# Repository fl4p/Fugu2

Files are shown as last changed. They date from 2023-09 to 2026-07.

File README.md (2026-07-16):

# Bi-directional DC-DC buck or boost converter for Solar MPPT

Links: [git](https://github.com/fl4p/Fugu2)
| [kicanvas](https://kicanvas.org/?github=https%3A%2F%2Fgithub.com%2Ffl4p%2FFugu2)
| [cadlab](https://cadlab.io/project/28816)
| [docs](doc/)
| [pdf schematics](Schematics.pdf)
| IBOM (TODO)
| [firmware](https://github.com/fl4p/fugu-mppt-firmware)
| [additional docs & resources](https://github.com/fl4p/fugu-mppt-doc)

```
TODO 3d web rendering
gate drv considerations:
- separate gate discharge diode?
- eval gate drv voltage?
- pull down for each fet? 10k pull down?
usb-c: select 12V instead of 5V

final points:
- what about the LS diodes? SMD and TO220, do power measurements.
    - ST15100S and ...
    - 2nd LS switch parallel ?
- sw push footprint
- test without TVS diodes at solar voltage divider. when does the mcu die? 
- tune dead-time

bom opts:
- Cin: C11, C22 replace with MSASH32MSB5475MPCA01 / HMK325BJ475MM-PE ?
    cheaper and specifically for SMPS
```

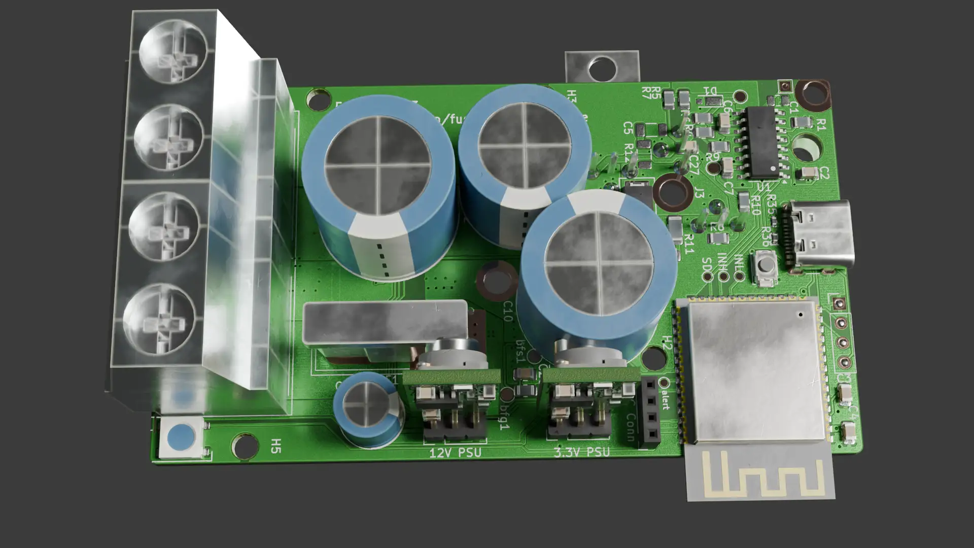
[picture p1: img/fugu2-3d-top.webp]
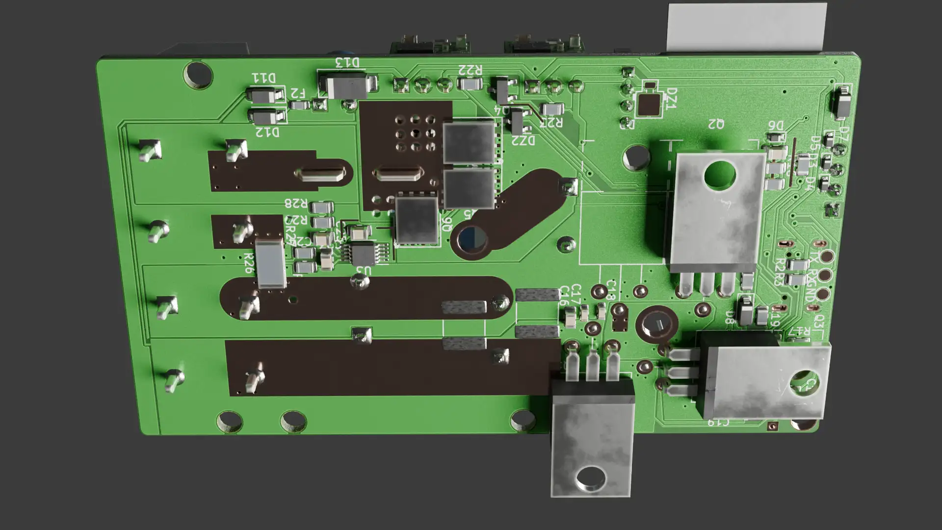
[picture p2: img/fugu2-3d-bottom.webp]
|   |
|:------------------------------------------------------------------------------------------------:|
|  Current Hardware v2.3 rendering with USB type-C port and large terminal blocks (top & bottom)   |

## Gallery

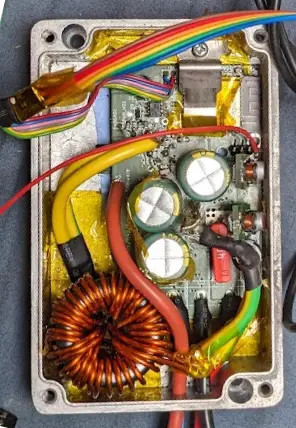
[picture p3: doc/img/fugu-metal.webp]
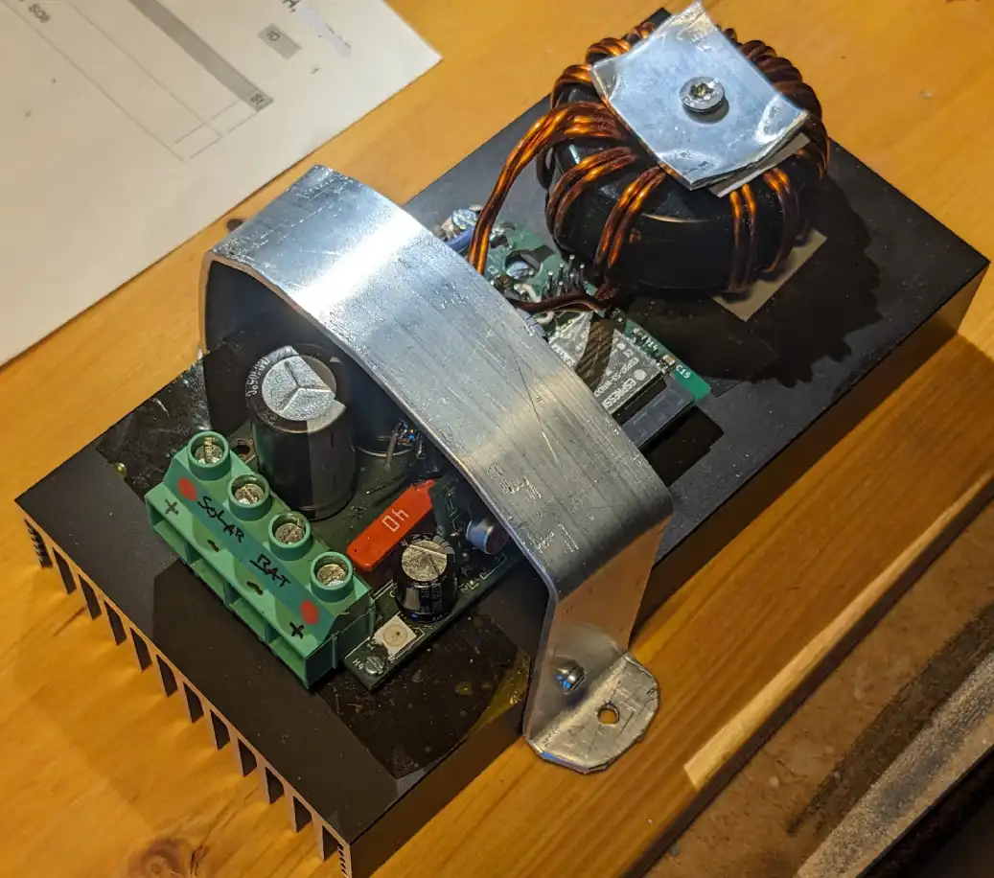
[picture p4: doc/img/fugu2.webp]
|  |  |
|:---:|:---:|
| Small aluminium enclosure with two T130 sendust coil cores [fmetal](HW%20Stories/Fugu%20Metal/README.md) | mounted on heatsink, T184 sendust core [fheat](HW%20Stories/fheat.md) |

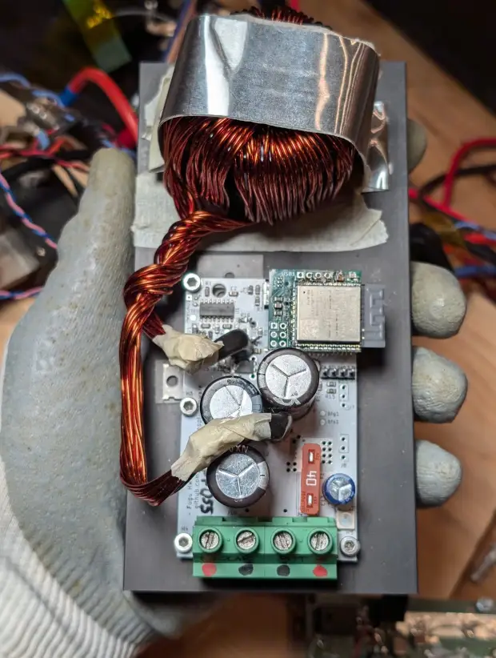
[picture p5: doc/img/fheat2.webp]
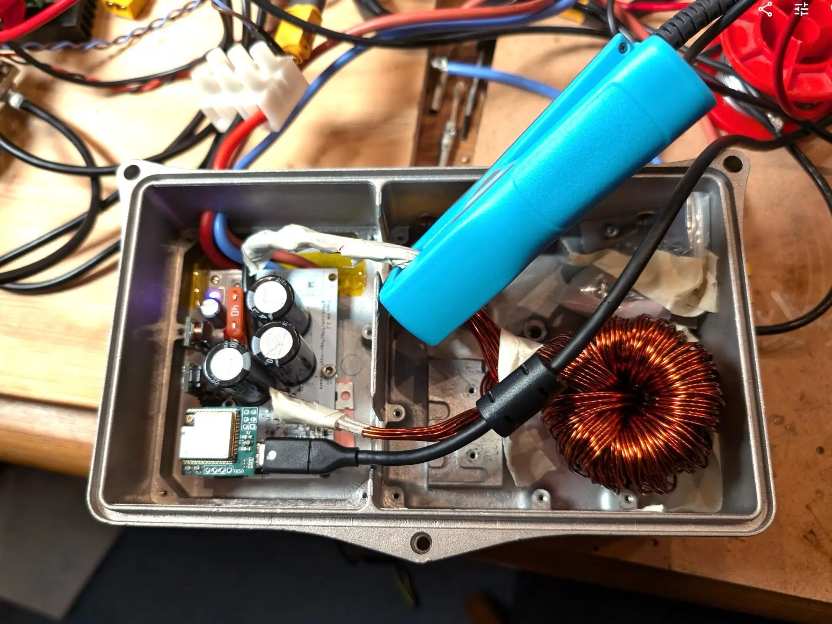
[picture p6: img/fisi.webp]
|  |  |
|:---:|:---:|
| improved coil with two T184 sendust cores [fheat2](HW%20Stories/fheat2.md) | inside an enclosure from a RF amp  [fisi](HW%20Stories/fisi.md) |

## Specs

* Solar input voltage: 12 ~ 80V (higher voltage configurations possible, please create an issue if you need help with
  component selection)
* Battery output voltage: 12 ~ 60V (LiFePo4 4s ~ 16s)
* Max output current: 32 A
* Boost operation with input and output terminals swapped
* Efficiency Measurements
    * Vin=72 Vout=27 Iout=32A: 98.17% (measured with INA228 & Riedon
      SSA-100, [smart-shunt](https://github.com/open-pe/smart-shunt-fw))
    * Vin=71.5 Vout=27.1 Iout=29.1A: 98.12% (measured with INA228, Riedon RSN20-50, DCCT
      DS200ID, [details](doc/Efficiency%20Measurements.md))

This is inspired by [Fugu MPPT](https://www.instructables.com/DIY-1kW-MPPT-Solar-Charge-Controller/).
The design has been optimized with real life experience, considering signal noise and EMI issues,
replaced hall sensor with shunt resistor and faster switching. See the list below for more changes.

## How to build

You can place the ESP32-S3 directly on the board and use the USB pin header or the ESP-PROG header for flashing.
Alternatively, you can place SMD pin headers where the ESP32-S3 footprint is and use the MCU header board.
This makes it easier to replace the MCU in case it breaks. You can of course create your own header board using another
MCU series such as the STM32.

* order PCB (or make @home)
    * 1x `Fugu2.kicad_pcb`
    * 1x `psu/buck100.kicad_pcb` (for 3.3V supply)
    * 1x `mcu-head/Fugu2-esp32s3-wroom-head.kicad_pcb` (optional. this allows easy replacement of the ESP32S3 during
      development. alternatively place the ESP32(-S3) directly on the Fugu2 board)
    * you can use [kikit-packer](https://github.com/fl4p/kikit-packer/)
      or [Kikakuka](https://github.com/buganini/Kikakuka/) to create a single PCB for the manufacturing job.
        * kikit-packer instructions: follow the install instructions in
          the [readme](https://github.com/fl4p/kikit-packer/tree/main?tab=readme-ov-file). make sure you have `Fugu2/`
          and `kikit-packer/` in the same directory. then run `panelize.sh` (linux, mac) or `panelize.bat` (windows). It
          will generate `combined.kicad_pcb` which you can send to your PCB manufacturer.
* assemble PCBs (ibom TODO)
    * you can order assembly through pcbway or jlcpcb
    * if you assemble @home
        * place solder-paste on all SMD pads
        * put SMD items first (resistors, caps, diodes, inductors and then IC)
        * heat with a hotplate (a cooking pan filled with sand works) or hot air gun
        * solder the THT components (electrolytic caps, power inductor, mosfets, pin headers, power terminal blocks)
* mount the PCB on a heatsink (expect 20W of heat)
    * drill mounting holes
    * if mosfets are not isolated use thermal pads for isolation
    * M3 plastic screws are a cheap and easy alternative
* enclosure
    * todo: there is no enclosure yet
* build inductor
    * order core and copper wire.
      cores are available at [semic](https://www.semic.info/) or digikey.
      I buy wire from eBay.
    * wind the coil
* flash [firmware](https://github.com/fl4p/fugu-mppt-firmware)

## Design Principles

* Simplicity with minimum number of components, while keeping EMI and efficiency in mind
* Only 2-layer PCB and using mostly 0805 SMD components, so this can be made at home
* Using TO220 switches for the buck for easy maintenance
* Dense PCB design to reduces parasitic L and R

## Compared to the original design:

- Multiple input caps to increase life-time, efficiency and reduced EMI
- 2 high-side switches in parallel to reduce heat and increase efficiency
- Using ESP32 ADC to sense input voltage, INA226 for bat voltage
- Using current sense resistor with INA226 (immunity against magnetic fields, less drift)
- Current sense on the battery side (less noise, can detect bat reverse current)
- Low-side current sensing because it supports up to 60V battery voltage (for 16s lifepo4 48V batteries)
- Backflow switch on battery side (bat eFuse if sth goes wrong, can safely handle a short of the high-side switches)
- Backflow switch powered by bootstrapping charge pump from the HS gate driver (no extra DC-DC)
- Much higher 4 A gate drive current (previously 130mA and 1.4 A) to reduce switching losses (TI UCC21330)
- Introducing RC snubber circuit to reduce EMI and MOSFET voltage stress
- TVS protection circuit to protect internal power supply
- off-board 3.3V and 12V power-supply
- USB break-out and off-board programmer (ESP PROG Header)
- Improved voltage and current sense PCB Design (voltage divider & filter caps close to ADC)
- Using LM5163 for power supply. (XL7005A explodes at surge voltages ~80V. Seems vulnerable at temps >~70°C)

## Power loss reduction

* 4A gate driver UCC21330BQDRQ1 with programmable dead-time
    * fast switching (high-side)
    * optimized dead-time, reduce free-wheeling losses (low-side)
* dense half-bridge PCB design for minimum parasitic inductance
* short and min-area gate-drive tracks for minimum gate drive inductance
* low-side rectifier Schottky barrier diode to reduce free-wheeling loss and reverse-recovery loss
* cascade of input capacitors: 220nF, 1uF, 10uF, 470uF input caps to minimize capacitor ESR-loss
    * low impedance electrolytics
* optimized coil designs
    * optimized core flux density and core power loss
    * multi-[strand](https://www.e-magnetica.pl/doku.php/strand) coil for reduced R_dc and R_ac (considering skin &
      proximity effect)

# Inductor Quick Start Guide

The inductor should have an inductivity value that is high enough to keep the ripple current in range, a common design
rule is that ripple is in the range of 0.3 ~ 0.5 of the dc current. Notice that inductivity decreases with dc bias
current. The dc bias current is the average current through the coil. This means that the higher the output current of
the converter,
the lower the inductivity. This causes the AC indcutor ripple current to rise faster than linear with higher currents.
High ripple currents cause more loss in the inductor core (hysteresis loss) and capacitors (parasitic ESR).
Going beyond the safe limits can cause extremely high peak currents leading to destruction of the FETs.

The [micrometals design tool](https://www.micrometals.com/design-and-applications/design-tools/inductor-designer/) is a
good starting point to find suitable inductor designs with mostly toroid cores. It gives the user recommendations on
core shape, core material and wire (diameter and strands).

Off-the-shelf inductors exists, however they are usually expensive (>$20), such as the 	
CODACA CPEX4141L-500MC (optimized for dc bias / saturation current) and CPEA4141L-500MC (optimized for low loss).
On LCSC you'll
find [Ruishen RSEQ32-470M](https://www.lcsc.com/product-detail/Power-Inductors_Ruishen-RSEQ32-470M_C37634010.html),
[RSEQ3635-460M](https://www.lcsc.com/product-detail/C37634012.html)  and
[RSEQ3635-700M](https://www.lcsc.com/product-detail/Power-Inductors_Ruishen-RSEQ3635-700M_C37634013.html).
I have only tested toe CODACA cores and no experience with the LCSC parts.

Diving into inductor design can be overwhelming at first. In practice there is no perfect inductor for a specific
application.
Given current, voltage and temperature contraints, the designer usually optimizes for one or more goals, which always
comes with trade-offs. In short:

* chose inductivity L0 high enough (L0 is the unbiased inductivity, e.g. I=0)
* good dc bias saturation performance (L drops with increased dc current)
* low DC resistance of winding
* low core losses

Winding an inductor is nothing to worry about and is actually fun. Below you'll find two design proposals, one
for 12 and 24V, upto 40A and the other for 48V batteries. Before, let's have a short intro to better understand the
design decisions.

A well designed inductor has a core/copper loss ratio between 50/50 and
20/80 ([micrometals](https://www.micrometals.com/design-and-applications/core-design-considerations/#inductor-design-basics)).
Copper is easier to cool
than the core.
With higher DC output current the core material magnetization increases and inductivity value drops. A good design has a
maximum drop of ~50% of its initial inductivity.
Lower inductivity will cause higher ripple current, which will cause more loss in the core and capacitors (increased AC
amplitude of magnetic field and current).

For higher DC currents chose a larger core (or materials optimized for DC saturation, which can have low availability
and a higher price tag).
For higher output voltage chose a higher inductivity value.

Sendust (KoolMµ)  is a magnetic core material commonly used for power applications. It is affordable with high
availability,
has good saturation characteristics and low loss.
Manufacturers offer optimized materials, tuning for price, dc bias and/or core loss.
([KDM](https://semic.cz/!old/files/pdf_www/Ljf_KDM.pdf): KPH, KAM, KAH, KH)

For the coil winding choose isolated Copper wire made for electrical applictions commonly referred as W210 with typical
conductivity of 58.5 MS/m. Choose diameter and number of strands so that inner diameter of the toroid core has a good
usage.
Prefer multiple strands for easier winding (>2mm diameter becomes unhandy to wind) and reduced ac loss (skin & proximity
effects). Many strands (>10) increase complexity of winding. A diameter between 1 and 2mm appears to be good choice.
More copper reduces dc resistance and leakage fringing (TODO ref). Evenly wind the wire on the core to reduce leakage
fringing.

## 12V or 24V battery up to 40A

* Optimized for low loss 12V and 24V batteries, up to 40A battery current @39kHz
* Core: 2 stacked [KS184-125A](https://www.semic.info/ljf-t184-s-125a-bk/) (or 0077438A7
  from [digikey](https://www.digikey.com/en/products/detail/magnetics-a-division-of-spang-co/0077438A7/18626927))
* Wire: Ø=1.18mm Cu (1.25mm total), W210 (Grade 2) Copper
* Winding: 10 strands, 12 turns, need 20 meter wire in total (10x 2m)
* Systematic name: 2s-KS184-125A-118cu-10s-12t
* [Micrometals analyzer](https://www.micrometals.com/design-and-applications/design-tools/inductor-analyzer/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)

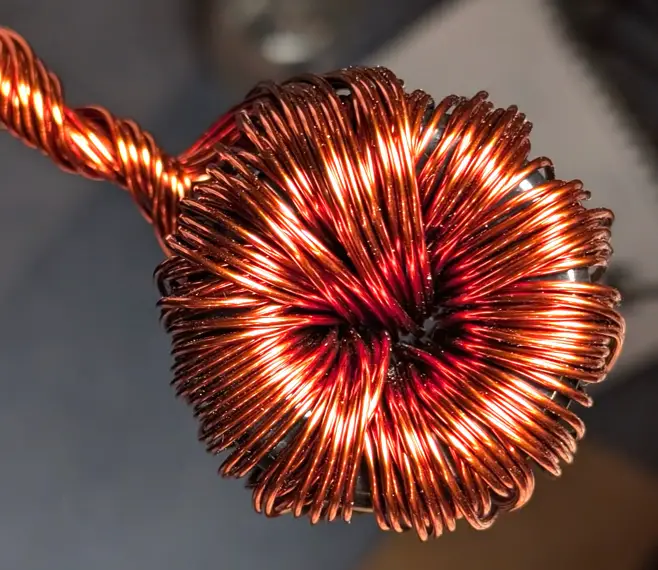
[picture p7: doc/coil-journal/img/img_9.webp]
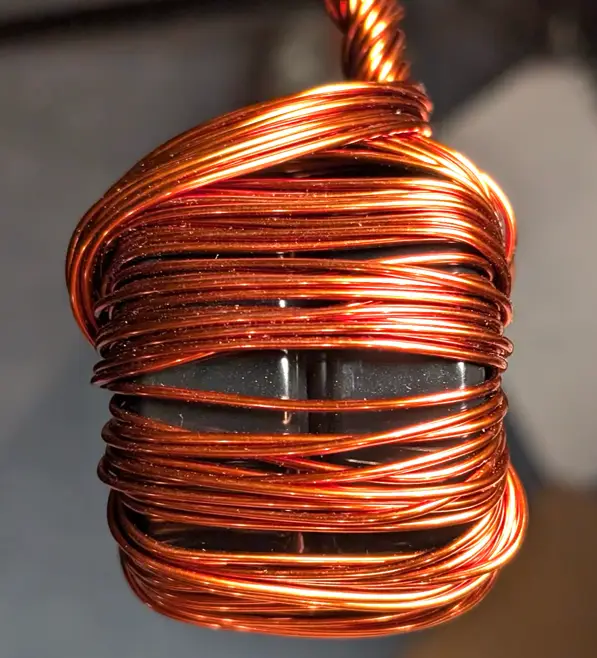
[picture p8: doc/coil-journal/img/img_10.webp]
 

## 48V batteries up to 20A

* Core: 1x [KS184-125A](https://www.semic.info/ljf-t184-s-125a-bk/)
* Wire: Ø=1.63mm Cu (AWG14), W210 (Grade 2) Copper
* Winding: 4 strands, 20 turns
* Systematic name: 1s-KS184-125A-163cu-4s-20t
* [Micrometals Analyzer](https://www.micrometals.com/design-and-applications/design-tools/inductor-analyzer/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)

# Mosfet Selection

In a nutshell, the LS switch should have low Rds_on, low Qrr, low Qgd (low self turn-on). The HS switch should have low
Qsw.
See [Toshibas Product Guide on pg. 16](https://www.mouser.com/datasheet/2/408/toshiba%20america%20electronic%20components,%20inc._bce008-1209380.pdf#page=16).

Use [fetlib](https://github.com/fl4p/fetlib) for an extensive parametric search and ranking by power loss estimation.

## High Side Mosfet (HS, cntrl)

- exposed to switching stress
- short switching times to lower switching losses (small Qsw) but increase potential ringing (EMI)
- low Rds_on
- body diode never conducts
- picks:
    - IPP055N08NF2S (80V 5.5mΩ Qsw=13nC)
    - IPP040N08NF2S (80V,)
    - CSD19501KCS (80V 5.5mΩ Qsw=11nC)
    - IPA050N10NM5S (100V 5mΩ Qsw=16nC Qoss=67nC)
    - IPP089N15NM6 (150V Qsw=11nC)
    - IPP057N15NM6 (150V Qsw=16nC)
    - IPP050N10NF2S (100 V)

## Low Side Switch (LS, sync)

- Choose a mosfet with low Q_rr ([how to compute qrr loss](https://www.ti.com/lit/ta/ssztc00/ssztc00.pdf))
    - Qrr rises with increasing temperature, current and current transient
    - Qrr ringing and loss can be reduced with external Schottky diode
      or [cascode configuration](https://www.researchgate.net/publication/378199983_Improving_the_Reverse-Recovery_Performance_of_Si_SJ-MOSFETs_with_a_Low-Voltage_GaN_HEMT_in_a_Cascode_Configuration).
- low Rds_on
- low Qgd, Qgd/Qgs (prevent self turn-on)
- low r_g (prevent self turn-on)
- Picks
    - IPP040N08NF2S
    - IPP022N12NM6
    - IPP019N08NF2S
    - IPP018N10N5 (100 V) 

Current through the LS Switch always flows from source to drain (4th quadrant of V-I plane),
which makes the gate drive signal rather irrelevant. It is much easier to switch than the HS, ringing is generally
not an issue. [TI Gate Drive Fudamentals](https://www.ti.com/lit/ml/slua618a/slua618a.pdf#page=22)
Switching happens near zero voltage, as the body diode is usually already/still conducting when switching on/off.

Choose a MOSFET that is designed for synchronous rectification. Consider switch node ringing and choose a higher voltage
fet to avoid channel break-down if needed.

# Higher input voltages

* input caps
* remove PV supply diode at board power supply
* bigger inductivity to keep ripple current at a reasonable level
* change mosfets HS & LS V_GS(breakdown) to 120V, 150V or 200V
* voltage sense resistors

# Water Robustness Considerations

* Add a clear varnish coat to the PCB and components (especially the current sensor circuit, Supply DCDC converters)
* Choose low R_filt for the anti-aliasing filter at the current sensor (INA226) inputs to avoid destruction of the
  chip's amplifiers.
* If using a (almost) sealed enclosure (aluminium box), add a bag silica to compensate internal humidity. When the
  converter is cooling down at night it'll suck water into the enclosure. The ESP32 WROOM metallic case is not sealed.
  Consider placing a membrane? Sticker on its breathing hole.

# Further Reads

* [Power Conversion Eff. Opt.](doc/Power%20Conversion%20Efficiency%20Optimization.md)

https://www.minewing.com/

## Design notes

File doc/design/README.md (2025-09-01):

MMPT Charger for residual applications.
- cost efficient
- not too heavy
- wireless RF interface

In our MPPT application we target batteries of 12, 24 and 48 V (nominal).
This the effective output voltage range is 10 ~ 59V.

Standard residual solar panels have open-circuit volages between 16 and 40 V.
-> Buck topo

For a power MOSFETS 80 V, 100 V, 120 V, 150 V, 200V
We pick 80 V.

For 2x 450W panels and a 24V battery we should accept currents up to 40A.

Hi
* improves panel matching and partial shading performance
* incresed failure safety 
* conversion ratios closer to 1 means higher efficiency
* convential microcontrollers (with RF) have limited PWM precision
* GaN usually needs >2-layers design (+cost)
  * fast switching requires good gate drive design
  * 

GaN?

GaN 

dsPIC33

Hihgher:
One of the most important design objective of DC-DC converters is conversion efficiency.
The higher the eff. the lower the power loss reducing the need of cooling.

Varying load points (operating point, working point) should be considered in thermal design
and component selection. If we want to optimize total efficiency across the whole working range
we measure would use the weighted average.

For compact designs with thermal it might be sufficient to just evaluate the highest load point.

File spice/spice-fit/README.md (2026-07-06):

# spice-fit — datasheet-fit diode models + application benches

Build and validation for the datasheet-fit SPICE models in [`../models/`](../models/),
plus Fugu2 application benches that use them. Repo overview: [`../README.md`](../README.md).

## Part fits (one subdir each)

| Part | Fit dir | VF@15 A, 25 °C |
|---|---|---|
| SMC **ST15100S** | [`st15100s/`](st15100s/README.md) | 0.68 V typ |
| PANJIT **SVT15100UB** | [`svt15100ub/`](svt15100ub/README.md) | **0.61 V typ** (lower loss) |

Each subdir: the digitized `datasheet_points.py`, `plot_validation.py` (model-vs-
datasheet overlay), any `trace_*.py` / `val_*.cir`, and a `reference/` with the
datasheet PDF + curve crops. The full **datasheet-over-vendor-model** write-up
(with the SMC ST15100 evidence) lives in [`st15100s/README.md`](st15100s/README.md).

## Application benches (Fugu2)

- [`ls_schottky_test.py`](ls_schottky_test.py) — does an external LS Schottky
  (ST15100S) across the switch reduce body-diode Qrr? DPT, TO-220 vs TDSON-8
  transfer-loop inductance.
- [`loss_budget_schottky.py`](loss_budget_schottky.py) — loss budget of a parallel
  SVT15100UB across the LS net (deadtime conduction + Qrr + added Coss) vs simply
  shortening the deadtime.

## Running

Use the repo venv: `../../venv/bin/python3` (numpy, scipy, pillow, matplotlib,
spicelib; LTspice for the benches). **LTspice-macOS gotcha:** run headless with
`LTspice -b file.cir` — never `-Run` (hangs the GUI); absolute `.include` paths
don't resolve in `-b`, so use a relative path or inline the `.MODEL`.

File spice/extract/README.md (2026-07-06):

# Commutation-loop parasitic extraction (KiCad → FastHenry → LTspice)

Extracts the **power commutation-loop inductance** of the Fugu2 buck from the
real PCB copper and feeds it into `../buck_parasitcs.asc`, replacing the
hand-guessed lumped inductors.

The switch stage is a compact SMD half-bridge on **B.Cu**: HS = `Q1‖Q3`
(Solar+→SW), LS = `Q2` (SW→BuckGND) with rectifiers `D9`/`D16`. Because the FETs
are SMD (Infineon PG-TDSON-8), not TO-220, the loop is tight and mostly planar.

## Result

**Loop inductance ≈ 5.3 nH** (pitch band 4.8–5.8 nH), HF loop R ≈ 21 mΩ,
measured across the nearest HF ceramic `C16`. See `results.md`.

## Tools

- **FastHenry 3.0.1** (MQS PEEC inductance solver), built from source at
  `/Users/fab/dev/vendor/FastHenry2` (FastFieldSolvers fork). Legacy K&R C, so
  built with: `make fasthenry CFLAGS='-O -DFOUR -m64 -std=gnu89 -fcommon
  -Wno-implicit-function-declaration -Wno-implicit-int -Wno-return-type
  -Wno-deprecated-non-prototype'` → binary in `bin/fasthenry`.
- **KiCad 9 bundled python** (has `pcbnew`) for geometry extraction:
  `/Applications/KiCad/KiCad.app/Contents/Frameworks/Python.framework/Versions/Current/bin/python3`
- **system python3** for the runner/reducer.

## Run

```sh
cd spice/extract
python3 run.py            # parallel 2.0/1.0/0.7 mm convergence sweep, ~8 s
python3 run.py --pitch 1.0   # single pitch
python3 run.py --full        # full 100 kHz–100 MHz L(f) curve (slower)
```

`run.py` shells out to the KiCad python (`kicad_to_fasthenry.py`) and to
`fasthenry`, parses `Zc.mat`, and writes `results.md`.

## How it works

`kicad_to_fasthenry.py` reads `Fugu2.kicad_pcb` and, for nets `Solar+`, `SW`,
`BuckGND` on both layers inside the switch-cluster ROI:

- meshes each filled pour into a **filament grid clipped to the polygon**
  (tracks are Manhattan-routed into the same grid so narrow connections survive;
  a global per-cell occupancy prevents coincident cross-net nodes → no NaN),
- stitches layers with **via** segments,
- shorts each switch drain→source with a thin **device bridge** (loop L =
  copper only; FET package L is added separately in LTspice),
- excites one **port** across the closest ceramic `C16`.

## Speed notes

- FastHenry rebuilds its preconditioner **per frequency**, so we solve only the
  ~10–100 MHz plateau (2 points), not a full sweep — the biggest lever.
- `-p diag` preconditioner + running the independent pitch solves concurrently.
- The source has **no OpenMP** (single-threaded); parallelism comes from running
  many independent solves at once.
- `0.5 mm` pitch needs the slow `-p cube` preconditioner (`diag`/`seg` → NaN on
  the large fine mesh), so the default sweep stops at `0.7 mm`.

## Caveats

- The gridded-filament plane approximation does not converge monotonically with
  pitch (~±9% scatter here) — treat 4.8–5.8 nH as the uncertainty band, not a
  single exact value. A future refinement is FastHenry uniform ground-plane
  (`G`) elements for the broad pours.
- FastHenry is magnetoquasistatic (L/R only); Coss resonance / ringing stays in
  LTspice.

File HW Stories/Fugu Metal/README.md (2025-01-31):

fugu metal in a aluminium case

G107-IP67 Gehäuse 125x80x40mm Alu-Spritzguss-Gehäuse IP67 https://www.ebay.de/itm/163117581325
Computed Thermal Resistance (40mm height, 100cm2 area) https://www.omnicalculator.com/physics/thermal-resistance
https://www.heatsinkcalculator.com/heat-sink-thermal-resistance-calculator.html
R = 0.016547 K/W

Alloy Thermal Conductivity: 110 - 120 130 - 160
W/mK https://www.bopla.de/technische-daten/technische-informationen/materialinformationen-aluminium/eigenschaften-von-aluminiumlegierungen

Input Caps

- 2x Beryl 100V 470µF D16xL26mm (china)
- 2x 10UF 100V X7S 2220 (TDK C5750X7S2A106K230KB) 2.2uF @
  80V [dc-bias](https://product.tdk.com/en/search/capacitor/ceramic/mlcc/info?part_no=C5750X7S2A106K230KB)
- 2x 1uF 100V X7R 1206 (TDK C3216X7R2A105K160AA)
- 2x .22uF 100V X7S 0603 (TY HMK107C7224)

Inductor / Coil

* Core: 2x stacked KS130-060A (33.8mm * 2x11.6mm)
    * sendust toroidal core from [semic-shop](https://www.semic.info/ljf-t130-s-060a-bk-en/)
        * micrometals equivalent: MS-132060-2 (optimized OC-132060-2)
        * https://www.micrometals.com/design-and-applications/design-tools/inductor-analyzer/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
    * Al=61nH, BSAT=1050 mT (per Core)
    * f33.83xf19.30x11.61mm
* Wire: 2 strands of 1.8mm (AWG#13) copper, 140cm (with σCu=58 we compute ESR=4.7mΩ)
    * turns=19.5 Turns
* Computed Inductivity = 2*61nH * 19.5^2 = 46.4 uH

Optimizations:

* Use OC with higher µ: OC-132090-2 @26Aout  : 6.3W -> 5.2W Coil Loss (4cu,1.1 Core)
  https://www.micrometals.com/design-and-applications/design-tools/inductor-analyzer/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
* increase f_sw from 40khz to 60khz:
    * OC-132090-2 loss: 5.2W ->  4.7W. (3.9W cu loss)
      * 4.3W https://www.micrometals.com/design-and-applications/design-tools/inductor-analyzer/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
    * reducing turn from 19 to 17: 4.5W
    * with MS-132090-2: 5.4W

Snubber: C0805C222K2GEC7800 2.2nF 200V C0G

- the aluminium enclose is a humdity trap
- wifi connection with the ESP32-WROOM-1 (PCB antenna) still possible `WiFi.rssi()` returns -88 ~ -80

- gate driver ir2184
- LS gate drive resistor 15ohm
- HS gate charge resistor 22 dis: 5ohm

HS: 2p TK6R8A08QM
LS switch [FDP027N08B]()

left it outisde at night it was raining
suced water inside. found water on the pcb and chips
ESP32 metal shield looks oxidated. Have problems to communicate with INA226 and external IC2 display whic i connected
for testing.

Sometimes it worked, sometimes not. I could see the device in the battery current graph turning on and off.

I heated the PCB with a hear dryer for some minutes but it didnt help. Now my idea is to turn on WiFi so the ESP32
generates some heat that will eventually evaporate the water from the inside.
THe only problem was, I didn"t have the right firmware version at hand (my laptop died 2 weeks ago),
so before flashing a new firmware that enables the WiFi hardware, I tried to create a flash dump with esptool.py (
read_flash).
That didn't work, it just didn't start to download after it uploaded the stub.

Next effort: try to run a binary from RAM
https://docs.espressif.com/projects/esptool/en/latest/esp32s3/esptool/advanced-commands.html#load-ram
esptool.py --no-stub load_ram ./test/images/helloworld-esp8266.bin

* validate image with image_info

October 2024:

- recovered some firmware code from backups
- replaced the ESP32S3 chip, and the charger was running again
  the 2nd day at 14:00 it ran into power-derating at 600W, 75°C. After a periodic sweep it took some time until current
  calibration passed (temperature drift), but it failed to start the conversion again. I found the 10V power supply
  XL7005A chip to be smoked, including the IR2184 gate driver. replaced both, successful test run at 20V. then 75V solar
  input, after 30 seconds noticed some weird data on serial console about when the INA226 alert pin interrupt was
  set-up. then a little explosion near the 3.3V power supply. now the other XL7005A burned, killing the ESP32S3. need to
  use a better chip, e.g. LM5163 .

Some log lines from that day, picked at different hours:

```
19°C ambient:
V=68.20/25.57 I= 3.5/ 9.04A 240.8W 30°C 124sps  0kbps PWM(H|L|Lm)= 791|1243|1243 MPPT(st= MPPT,1) lag=67.3ms N=92158 rssi=-84
V=66.97/26.89 I= 6.2/14.95A 412.6W 45°C 124sps  0kbps PWM(H|L|Lm)= 867|1168|1168 MPPT(st= MPPT,1) lag=67.3ms N=110781 rssi=-79
V=63.66/27.43 I= 8.8/19.89A 562.2W 70°C 123sps  0kbps PWM(H|L|Lm)= 933|1102|1102 MPPT(st= MPPT,1) lag=10023.8ms N=45069 rssi=-79
V=63.26/27.50 I= 9.4/21.06A 598.6W 74°C 124sps  0kbps PWM(H|L|Lm)= 938|1097|1097 MPPT(st= MPPT,1) lag=10023.8ms N=110973 rssi=-86
de-rating:
V=63.43/27.50 I= 9.5/21.18A 600.5W 75°C 124sps  0kbps PWM(H|L|Lm)= 936|1099|1099 MPPT(st=   CP,1) lag=10023.8ms N=115814 rssi=-82
V=67.70/27.33 I= 7.9/19.05A 536.9W 76°C 124sps  0kbps PWM(H|L|Lm)= 877|1158|1158 MPPT(st=   CP,1) lag=10023.8ms N=136672 rssi=-83

```

the sweep before the 10V power supply burnt

* todo: why not re-starting mppt after sweep? and controlMode=0 (st=N/A)

```
V=66.52/27.22 I= 8.4/19.96A 560.2W 75°C 124sps  0kbps PWM(H|L|Lm)= 889|1146|1146 MPPT(st= MPPT,1) lag=10023.8ms N=151197 rssi=-81
I (56831968) mppt: periodic zero-current calibration
I (56831971) mppt: Start sweep
I (56831974) mppt: Start calibration
I (56831977) sensor: U_in_raw reset calibration
I (56831979) sensor: Io reset calibration
I (56831983) sensor: U_out_raw reset calibration
I (56832003) store: Wrote /littlefs/stats (size 32)
I (56832006) flash: Wrote flash value /littlefs/stats
PWM disabled (duty cycle was 888)
I (56832333) sampler: Sensor U_in_raw calibration: avg=77.4220 std=0.003713
I (56832339) sampler: Sensor Io calibration: avg=0.1864 std=0.001848
I (56832342) sampler: Sensor Io midpoint-calibrated: 0.186386
I (56832351) sampler: Sensor U_out_raw calibration: avg=26.7787 std=0.000010
I (56832354) sampler: Calibration done!
V=77.52/  nan I= nan/  nanA   nanW 75°C  0sps  0kbps PWM(H|L|Lm)=   0|   0| 123 MPPT(st=  N/A,1) lag=10023.8ms N=0 rssi=-87
buck: CCM -> DCM (vr=0.9900, pwmMaxLs=0.0, lsCCM=2047)
Backflow switch disabled
V=77.27/26.70 I=-0.0/-0.10A  -2.7W 76°C 165sps  0kbps PWM(H|L|Lm)=   0|   0| 123 MPPT(st=  N/A,1) lag=10023.8ms N=495 rssi=-82

I (56838317) main: received serial command: ''
I (56838320) main: unknown or unexpected command
V=77.21/26.70 I=-0.0/-0.12A  -3.3W 77°C 165sps  0kbps PWM(H|L|Lm)=   0|   0| 123 MPPT(st=  N/A,1) lag=10023.8ms N=990 rssi=-84
V=77.18/26.69 I=-0.0/-0.14A  -3.8W 77°C 165sps  0kbps PWM(H|L|Lm)=   0|   0| 123 MPPT(st=  N/A,1) lag=10023.8ms N=1488 rssi=-86
V=77.21/26.68 I=-0.1/-0.15A  -4.1W 77°C 165sps  0kbps PWM(H|L|Lm)=   0|   0| 123 MPPT(st=  N/A,1) lag=10023.8ms N=1984 rssi=-88
V=77.44/26.67 I=-0.1/-0.16A  -4.3W 77°C 165sps  0kbps PWM(H|L|Lm)=   0|   0| 123 MPPT(st=  N/A,1) lag=10023.8ms N=2480 rssi=-88
V=77.10/26.67 I=-0.1/-0.16A  -4.5W 77°C 165sps  0kbps PWM(H|L|Lm)=   0|   0| 123 MPPT(st=  N/A,1) lag=10023.8ms N=2976 rssi=-88
V=77.35/26.67 I=-0.1/-0.17A  -4.7W 76°C 165sps  0kbps PWM(H|L|Lm)=   0|   0| 123 MPPT(st=  N/A,1) lag=10023.8ms N=3472 rssi=-85
V=77.24/26.66 I=-0.1/-0.17A  -4.8W 76°C 164sps  0kbps PWM(H|L|Lm)=   0|   0| 123 MPPT(st=  N/A,1) lag=10023.8ms N=3967 rssi=-84
V=77.24/26.66 I=-0.1/-0.18A  -4.9W 76°C 165sps  0kbps PWM(H|L|Lm)=   0|   0| 123 MPPT(st=  N/A,1) lag=10023.8ms N=4464 rssi=-81
V=77.27/26.65 I=-0.1/-0.18A  -5.0W 76°C 165sps  0kbps PWM(H|L|Lm)=   0|   0| 123 MPPT(st=  N/A,1) lag=10023.8ms N=4961 rssi=-81
```

# V2
- Caps
  - the beryl cap is poor, high impedance
  - https://www.digikey.de/short/b9pp4zc5
  - KYOCERA REF1625471M100B has 45mΩ with 16mm.
  - maybe change to 18mm caps
    - chemi con EKZN101ELL561MM25S
    - ruby con 100ZLJ470M18X25 (18mm dia)
- Inductor
  - OE-130090-2 https://www.micrometals.com/design-and-applications/design-tools/inductor-analyzer/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
  - SM-130060-2 (KAM* nanodust, Ljf T130-AM-060A-E14 GK) https://www.micrometals.com/design-and-applications/design-tools/inductor-analyzer/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
  - 2s HS-130060 (58071A2-2)
    - 19Turns, 1.18mmCu, 5strands
  - 2s GX-130125-2
    - 15/16 turns, 1.18mmCu 6strands
    - got 18 turns (L0=90µH with 6strands), very tight!
      - micrometals analyzer with 16,8AWG says ID use=0.47 (for awg17=0.44)

- Switches:
  - Low: IPP022N12NM6AKSA1 (gdrv: 4.7R) and  ST15100S Trench MOS Schottky Rectifier (SMD)
  - HS: 2x IPP040N08NF2SAKMA1 (gdrv: 4.7R, discharge: 4.7R/2)

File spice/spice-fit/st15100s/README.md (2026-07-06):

# ST15100S SPICE model — datasheet fit

SMC Diode Solutions **ST15100S** (100 V, 15 A trench-MOS Schottky rectifier,
TO-277B) has **no vendor SPICE model** published (the "Spice Model" column on
SMC's Ultra-Low-VF list points to the homepage). This directory builds one by
fitting the datasheet (N2219 Rev.-) and validating it in LTspice.

> **See also:** the lower-VF pin-compatible alternative **PANJIT SVT15100UB**
> (0.61 vs 0.68 V @15 A) — fit in [`../svt15100ub/`](../svt15100ub/README.md).
> Repo overview in [`../../README.md`](../../README.md).

**Model:** [`../../models/ST15100S.lib`](../../models/ST15100S.lib)

## Guiding principle: the datasheet outranks any vendor SPICE model

Trust order: **datasheet table > datasheet chart > vendor SPICE model.** A vendor
`.lib` is a *derivative* — a curve-fit constructed *from* the datasheet — so it can
only lose or distort information relative to the datasheet, never add it; the
temperature block (`TRS1/TRS2`, `EG`, `XTI`) is where it usually goes wrong. Case in
point: SMC's own **ST15100** model matches its datasheet at 25 °C but at 125 °C/15 A
gives 0.863 V vs the table's 0.66 V typ (+203 mV, wrong direction), exploding to
1.57 V @30 A — it contradicts the datasheet it ships with. So this model was built
*from the ST15100S datasheet*, and any vendor model should be validated against the
datasheet **at the operating point AND at temperature** before it's trusted.

## Result (LTspice-validated)

| Characteristic | Model | Datasheet | 
|---|---|---|
| VF @ 15 A, 25 °C | 0.685 V | 0.68 typ / 0.71 max |
| VF @ 15 A, 125 °C | 0.598 V | 0.60 typ / 0.64 max |
| CT @ 5 V, 1 MHz | 663 pF | 650 pF typ |
| CT @ 0 / 10 V | 2200 / 436 pF | 2200 / 420 pF |

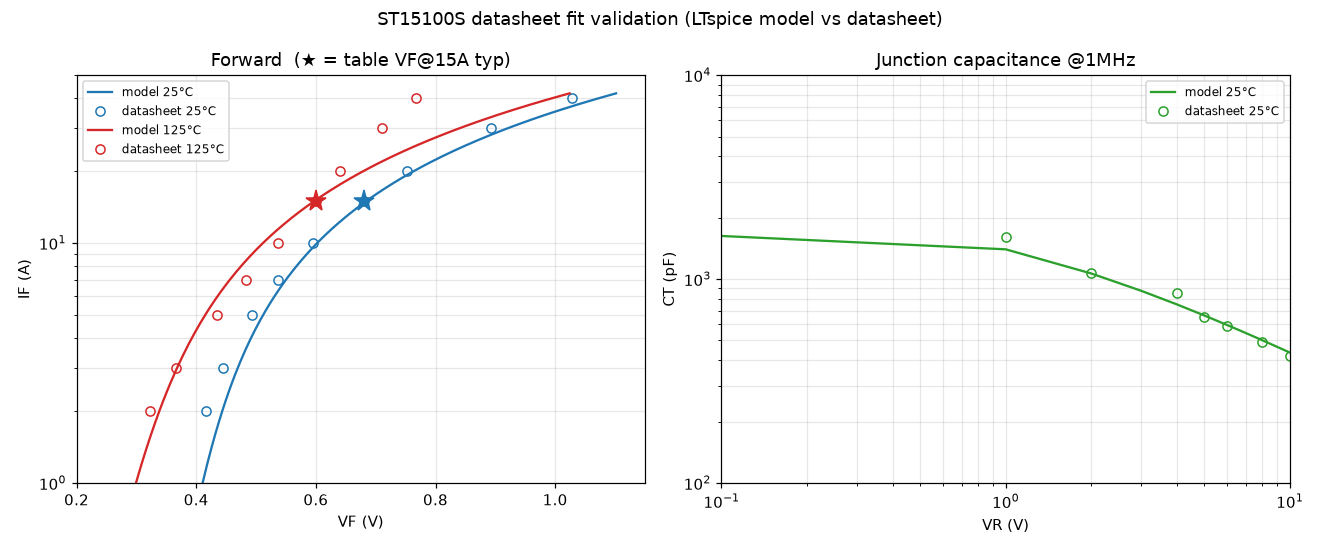
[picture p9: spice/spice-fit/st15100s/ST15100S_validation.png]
validation


## Method

1. **Data source.** SMC's site is behind a JS "browser security check" WAF
   (`_wtsjsk` cookie), so `curl`/WebFetch get 403. The datasheet PDF and the two
   sibling models (`ST15100`, `ST15100C`) were fetched with a headless browser
   (Playwright) that executes the challenge, then via same-origin `fetch`.
2. **Digitize the forward curves** (`trace_fwd.py`) — a gridline-calibrated
   raster trace of Figure 1 (both 25 °C and 125 °C), adapting the
   grid-mask + dark-run approach from `pwr-mosfet-lib/dslib/viz/raster_extract.py`,
   plus a connected-component filter to remove the in-chart label boxes. The
   guaranteed 15 A points come from the table, not the trace.
3. **Fit** (`fit` cells, see git history / notes) — IS, N, RS to the 25 °C
   operating region; CJO, VJ, MJ to the C-V curve; EG, XTI to the forward VF(T)
   shift. `EG = 0.69 eV` is the physical Schottky barrier and is independently
   consistent with the datasheet reverse-leakage temperature ratio (750×).
4. **Validate** (`val_fwd.cir`, `val_cap.cir`, `plot_validation.py`) in LTspice.

## Cross-check vs the manufacturer sibling model AND datasheet

Both SMC sibling **models** (`ST15100`, `ST15100C`) and the SMC **ST15100
datasheet** (N1038, `reference/ST15100_N1038_datasheet.pdf`) were pulled and
checked. Three findings, each of which validates a modelling choice here:

**(a) A single physical diode cannot reproduce the high-current tail of EITHER
sibling's Figure 1 — so anchor to the guaranteed table, not the chart tail.**
Both charts (digitized) show the 125 °C curve staying *lower-VF* than 25 °C at
every current — **no crossover** — with the gap narrowing to a mid-current
minimum then *widening* at high current:

| gap (VF₂₅ − VF₁₂₅) | 2 A | ~10 A (min) | 30 A |
|---|---|---|---|
| ST15100 (digitized) | +68 mV | +22 mV | +94 mV |
| ST15100S (digitized) | +94 mV | +60 mV | +182 mV |

Same shape; ST15100S just has a larger gap (bigger temp coefficient). A widening
high-current gap means the 125 °C incremental resistance is *lower* than 25 °C
(ST15100: 17.5→13.9 mΩ; ST15100S: 14.9→8.75 mΩ over 10→30 A) — hard to reconcile
with a Schottky's RS *rising* with temperature. A physical single-diode model
(positive RS-TC) instead makes the curves *converge* at high current, so it
cannot trace these chart tails. Hence the model is anchored to the guaranteed
**table VF@15 A** (both temps) + the 10–20 A operating region, and is allowed to
deviate from the extreme high-current 125 °C tail. This is inherent to fitting
either part — NOT an ST15100S-specific anomaly (an earlier version of this note
wrongly claimed ST15100's curves cross; they do not). See
`reference/ST15100_fig1_curves.png`.

**(b) SMC's own ST15100 model contradicts SMC's own ST15100 datasheet.** The
model gives VF@15A 0.666 V (25 °C) → **0.863 V (125 °C)** — but the datasheet
table says 0.70 → **0.66**. The model is +203 mV off and *backwards* in
temperature direction (its `EG=1.17` Si-bandgap + large `TRS1/TRS2`). Copying
that block would import the bug; this model uses `EG=0.69` so VF correctly falls.

**(c) The siblings have genuinely different temp coefficients** (ST15100 −40 mV,
ST15100S −80 mV @15 A over 25→125 °C), so a sibling model can't just be reused —
each part needs its own temperature fit.

(ST15100C datasheet: SMC's server 502s on that specific file; the direct TO-220
sibling ST15100 is conclusive.)

## Caveats

- Optimised for the 10–20 A operating region; the 2 A and 40 A tails carry more
  error (a single SPICE diode cannot fit the full 2–40 A span at both temps —
  the datasheet curves *diverge* with temperature).
- Reverse-leakage **magnitude** is ~20× low (0.5 µA vs 10 µA typ @100 V) — a
  known single-diode Schottky limitation (SMC's own sibling model under-predicts
  it too). The temperature *behaviour* is physical. Negligible for
  switching/conduction simulation.
- `TT=0`: Schottky, negligible reverse recovery.

## Files

| File | |
|---|---|
| `../../models/ST15100S.lib` | the model (validated) |
| `trace_fwd.py` | digitize Fig 1 forward curves |
| `datasheet_points.py` | digitized + table reference points |
| `val_fwd.cir`, `val_cap.cir` | LTspice validation benches |
| `plot_validation.py` | model-vs-datasheet overlay → `ST15100S_validation.png` |
| `reference/` | datasheet PDF, sibling mfr models, Fig-1 crops |

**LTspice-macOS gotcha:** run headless with `LTspice -b file.cir` (no `-Run`,
which hangs the GUI). Absolute `.include` paths do **not** resolve in `-b` mode —
use a relative path from the `.cir`, or inline the `.MODEL` (as `plot_validation.py` does).

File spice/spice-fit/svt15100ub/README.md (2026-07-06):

# PANJIT SVT15100UB SPICE model — datasheet fit

PANJIT **SVT15100UB** (100 V, 15 A "Extreme Low VF" trench-MOS Schottky, TO-277B)
has **no vendor SPICE model** — Panjit's library contains no SVT/trench parts at
all. Built from the datasheet (SVT15100UB-REV.02, 2025-12-10), same method as the
SMC `ST15100S` fit, and validated in LTspice.

**Model:** [`../../models/SVT15100UB.lib`](../../models/SVT15100UB.lib)

## Why this part

A lower-loss alternative to the SMC ST15100S (same 100 V/15 A/TO-277B):

| @15 A, 25 °C | **SVT15100UB** | SMC ST15100S |
|---|---|---|
| VF typ / max | **0.61 / 0.66 V** | 0.68 / 0.71 V |
| IR @100 V, 25 °C | **80 µA max** | 500 µA max |
| IFSM | 250 A | 220 A |
| Forward curves | **4 temps** (25/75/125/150 °C) | 2 temps |

## Result (LTspice-validated)

| Characteristic | Model | Datasheet |
|---|---|---|
| VF @15 A, 25 °C | 0.608 V | 0.61 typ / 0.66 max (table) |
| VF @5 A / 1 A, 25 °C | 0.474 / 0.389 V | 0.47 / 0.38 (table) |
| VF @15 A, 125 °C | 0.529 V | ~0.54 (Fig 4; not in table) |
| CJ @1 / 5 / 10 V | 2019 / 1091 / 707 pF | ~2000 / 1250 / 600 (Fig 2) |

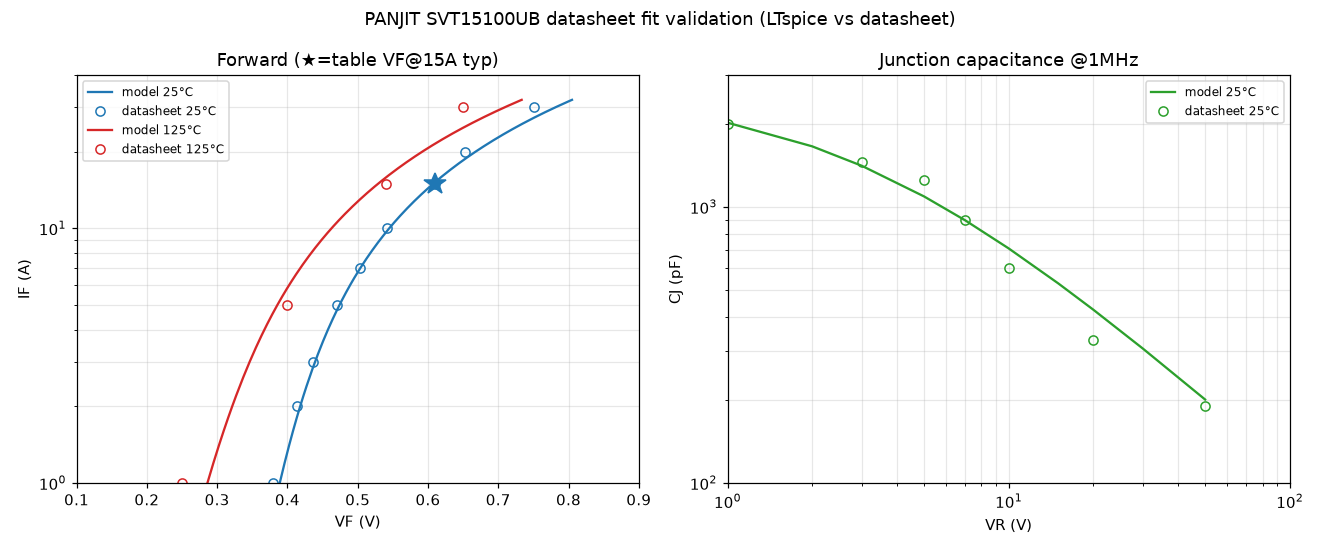
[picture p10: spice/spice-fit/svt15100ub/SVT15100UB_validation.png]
validation


## Method & fit notes

- Datasheet has only 6 pages, richer curves than SMC: **Fig 4 gives four forward
  temperature curves**. Digitized with a gridline-calibrated raster trace, the
  x-scale pinned to the vertical gridlines (`VF=(col-272)/858`) and the log-y
  calibrated against the 25 °C **table anchors** (1/5/15 A) — so the calibration
  is validated by the guaranteed points before any 125 °C value is read.
- Table gap: **no VF@15 A at 125 °C** (only 1 A & 5 A) — the 15 A/30 A hot points
  come from Fig 4 (~0.54 / 0.65 V). No tabular CT (Fig 2 only).
- `IS=9.5e-7, N=1.05, RS=0.0104` — lower RS than ST15100S (0.0144), matching the
  lower VF.
- **`TRS1=0`**: the datasheet's incremental resistance is ~14 mΩ at *both* 25 °C
  and 125 °C (5→15 A), so RS is temperature-independent here. This keeps the
  25/125 °C curves from crossing at high current (gap stays ~75 mV) — avoiding the
  vendor-model failure mode where an over-large RS tempco makes the hot curve
  explode past the cold one (see the SMC ST15100 model, `../reference/`).
- `EG=0.65` (~Schottky barrier) reproduces the VF(T) shift across all four curves
  and the ~1000× reverse-leakage temperature ratio (80 µA→15 mA @100 V).
- `TT=0`: Schottky. **Caveat:** reverse-leakage magnitude ~10× low (single-diode
  Schottky limit); the single-junction cap model can't perfectly track Fig 2's
  flat-then-knee shape (MJ=0.90 is the compromise). Both negligible for
  switching/conduction simulation.

Same guiding principle as the ST15100S fit: **the datasheet is the ground truth**
(here there's no vendor model at all), validate in LTspice at operating point and
temperature. Full write-up: [`../st15100s/README.md`](../st15100s/README.md);
index: [`../README.md`](../README.md).

## Files
| File | |
|---|---|
| `../../models/SVT15100UB.lib` | the model |
| `datasheet_points.py` | digitized + table reference points |
| `plot_validation.py` | model-vs-datasheet overlay → `SVT15100UB_validation.png` |
| `reference/` | datasheet PDF, Fig-4 (forward) & Fig-2 (cap) crops |

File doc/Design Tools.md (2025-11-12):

# Inductor

[micrometals designer](https://www.micrometals.com/design-and-applications/design-tools/inductor-designer/)

[micrometals analyzer](https://www.micrometals.com/design-and-applications/design-tools/inductor-analyzer/)

https://www.mag-inc.com/Design/Design-Tools

# Capacitors
https://product.tdk.com/en/search/lc_select_tool

https://ds.murata.com/simsurfing/mlcc.html?lcid=en-us

# Mosfets / GaN
EPC Cross Reference https://epc-co.com/epc/design-support/part-cross-reference-search
[EPC Buck](https://epc-co.com/epc/design-support/tools-and-calculators/gan-power-bench/gan-fet-selection-tool-for-buck-convertors)

https://www.dmcinfo.com/latest-thinking/blog/id/10517/mosfet-power-loss-calculator

# Thermal, Heat sink

https://www.heatsinkcalculator.com/heat-sink-size-calculator.html

https://epc-co.com/epc/design-support/gan-power-bench/gan-fet-thermal-calculator

# Python

ltspice package to read LT-spice .raw file

https://schemdraw.readthedocs.io/en/latest/

latex circuits https://ctan.org/pkg/circuitikz?lang=en
M4 circuits  https://ece.uwaterloo.ca/~aplevich/Circuit_macros

interactive plots
https://github.com/matplotlib/ipympl

QSPice

# DCDC
https://www.poweresim.com/

# PV
https://github.com/pvlib/pvlib-python

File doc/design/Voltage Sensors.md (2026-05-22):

To measure high voltages, we use two resistor to form a voltage divider.
Parallel to the lower resistor we add a capacitor, which serves two purposes:

1. Buffering ADC input. Filter capacitance should be much higher than ADC input capacitance.
2. RC low-pass to filter aliasing frequencies

We can compute the cut-off frequency of the "filtered voltage divider" with $f_c = \frac{1}{2\pi * (R_1//R_2) * C_1}$
and with $R2 << R1$ it is simply $f_c = \frac{1}{2\pi * R_2 * C_1}$

Let's use some real values:

We chose R1 = 200k and R2 = 7.5k for a max. input voltage of 80V.
With an input capacitor value of 100nF, the cut-off frequency (-3dB = 0.5 attenuation) will be 212 Hz .
At 2 kHz, attenuation will be -20dB, which is a factor of 0.01. At 20 kHz, -40dB = 1e-4.

Rise time (10% to 90%) of an RC low-pass is $t_r = RC \cdot 2.2$, so here 1.65 ms.

## Non-linearity
The the ESP-IDF API reference about
the [ESP32-S3 ADC](https://docs.espressif.com/projects/esp-idf/en/v4.4/esp32s3/api-reference/peripherals/adc.html)
mentions some non-linearity at the upper voltage end. We can ignore this, or implement some polynominal curve fit
calibration. We can calibrate each chip individually or use the same coefficients we are chips.
Here we use a voltage range of 0 .. 2.86V and ignore the non-linearity.

## ADC input impedance
$R_1$ should be << $R_{ADC}$.

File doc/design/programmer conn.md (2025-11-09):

esp32 has wifi. we will need usb mostly for dev, jtag, hw config. system integration through usb is rather uncommon and usb hosts usually have bluetooth.
we can also put the esp32 i host mode and use a female connector for usb sticks etc.
to keep things simple & small, we chose for a 2.54 4-pin header connector (TOOD JST?)

the USB connector enables
- flashing/programming and serial console
- JTAG debugger
- USB mass storage, otg, host
board can read usb sticks or emulate one
TODO: feed vbus into PV inp? 
if we manage to get 20v 5A, the board can be a usb-c powered charger, power supply
- usb type c can (no PD) 15 W at 5 V / 3 A

TODO> have CC1 and CC2 NOT CONNECTED to each other, like RPI issue, see https://hackaday.com/2023/01/04/all-about-usb-c-resistors-and-emarkers/

to keep things simple, maybe just add another 4pin header, +5V, GND, D- D+ 
the extension board can then implement usb-connector (type C has many different footprint), protection diodes, resistors, even PD?

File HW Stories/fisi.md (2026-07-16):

# fisi (now fry)



- Board: Fugu HW 2.2
- Enclosure from Wisi Value Line VX 22
- Switches:
  - Low: IPP022N12NM6AKSA1 (gdrv: 4.7R) and  ST15100S Trench MOS Schottky Rectifier (SMD)
  - HS: 2x IPP040N08NF2SAKMA1 (gdrv: 4.7R, discharge: 0R)
  - no snubber (?)
- Inductor:
  - Core: 2x [KDM KS184-125A](https://www.semic.info/ljf-t184-s-125a-bk/) (Al=2*281nH)
  - Coil: 12 strands d=1.18mm Cu W210 Wire, 10 Turns (really 10? maybe 12?)
  - L0_nom = 56µH or 81??
- Caps:
  - in: 2x Rubycon ZLH 470uF 100V 16mmx31mm (Z=33mΩ each)
  - out: 1x "
- Power Measurement: ([smart-shunt](https://github.com/open-pe/smart-shunt-fw))
  - Pin=879W Pout=863W, Ploss=1.83%
  - Pin=1.02kw Pout=1.00 Ploss=2.09%

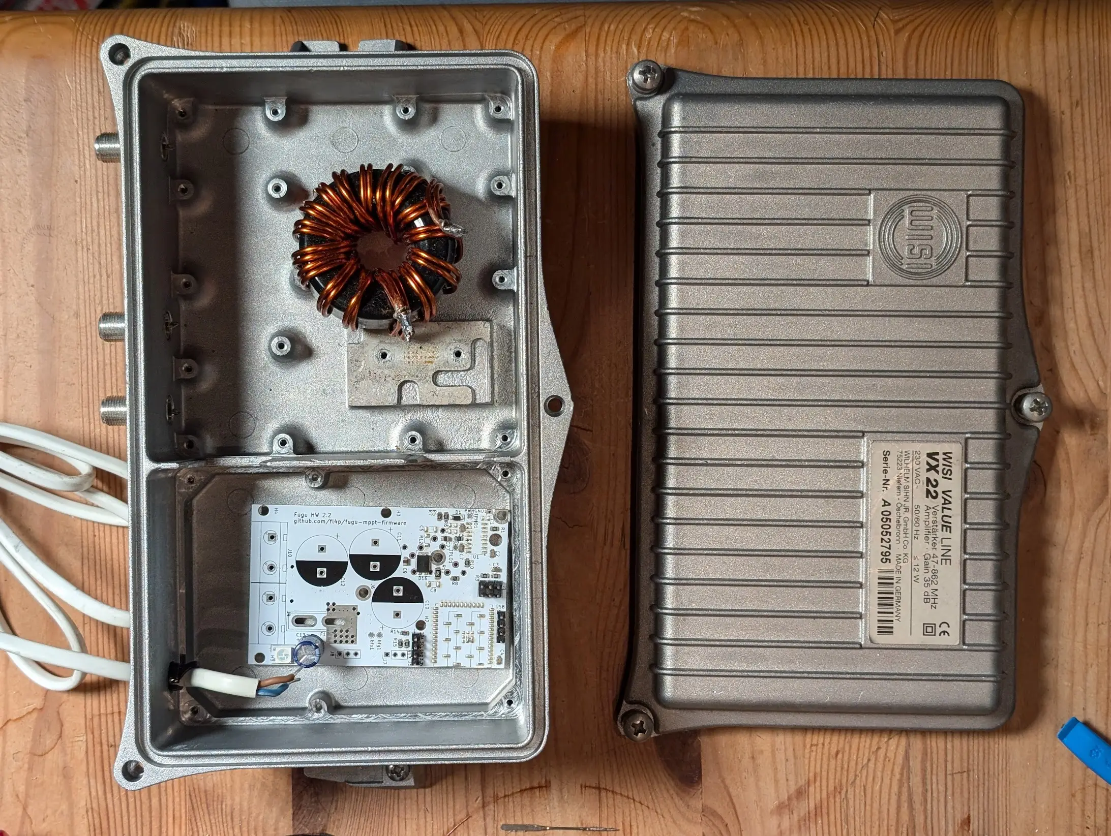
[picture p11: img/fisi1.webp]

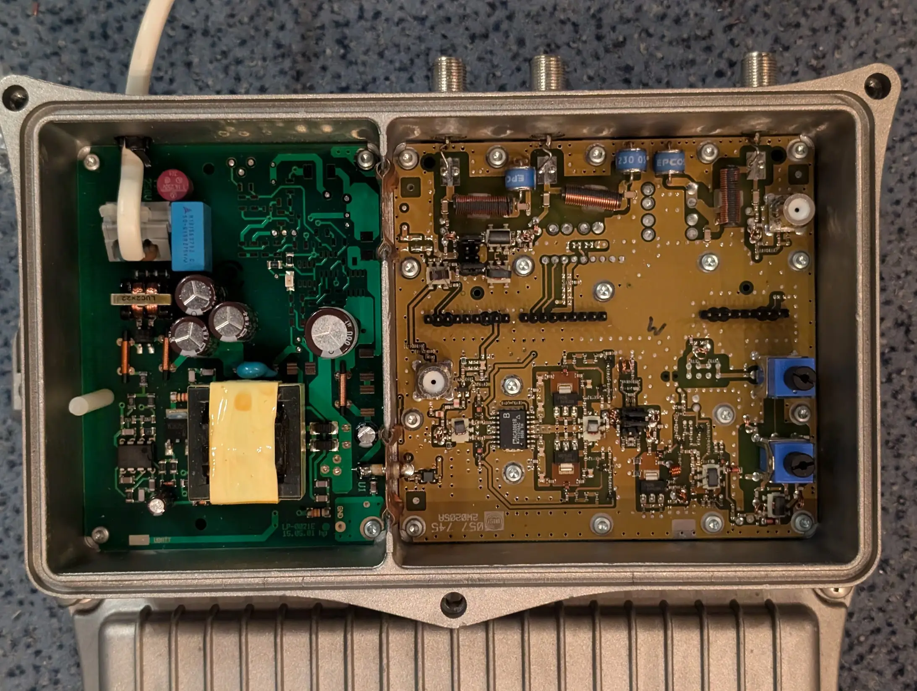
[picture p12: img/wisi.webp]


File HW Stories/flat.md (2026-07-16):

# flat

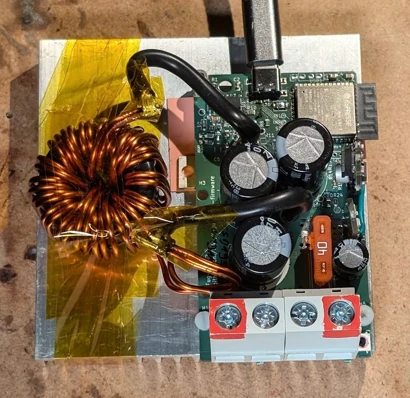
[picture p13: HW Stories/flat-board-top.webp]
flat-board-top


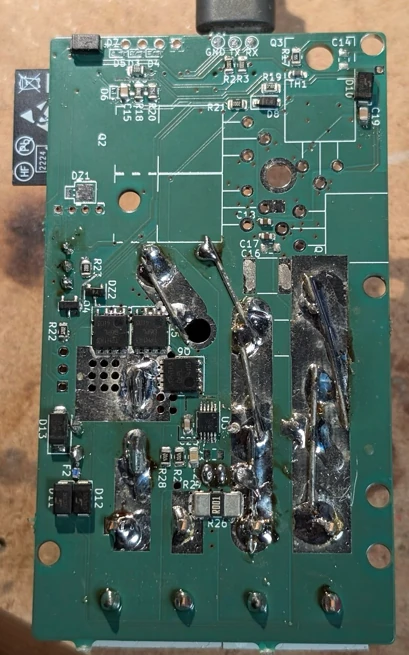
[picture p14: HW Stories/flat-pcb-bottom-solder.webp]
flat-pcb-bottom-solder


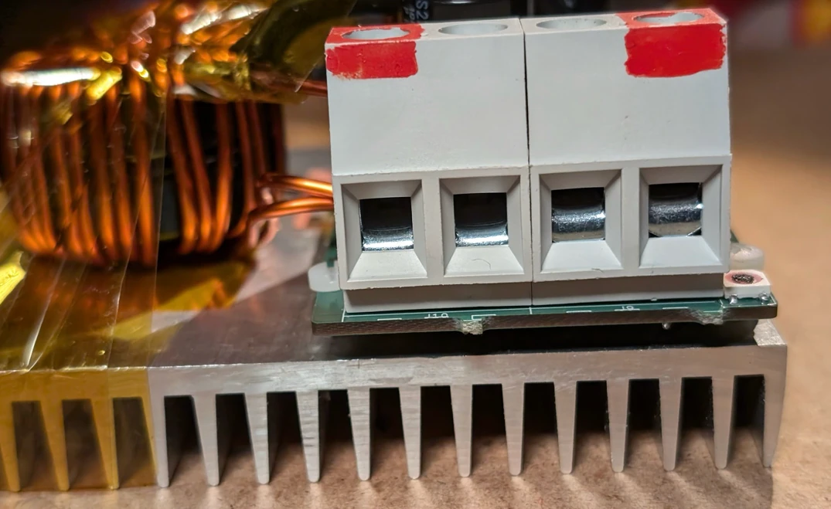
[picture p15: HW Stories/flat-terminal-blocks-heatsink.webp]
flat-terminal-blocks-heatsink


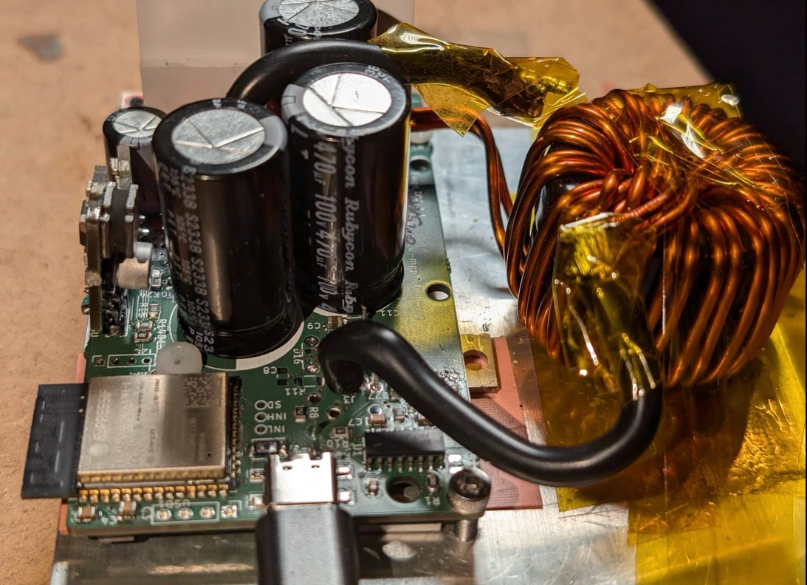
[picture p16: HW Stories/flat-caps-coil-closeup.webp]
flat-caps-coil-closeup


* first time tried the 3.3V -> 12V boost supply for gate drive voltage
* first build with on-board usb-c

Switches (written on board)
- LS: 1x IPP019N08NF2S
  - 4.7 gate charge
  - no gate dsg (there was an issue with the supply or something, see below)
- HS: 2p CSD

Coil
- Core: 2 staked KS130-060A (Al=122nH/N^2)
- 19~20?Turns => 44~54 uH?

Caps:
- Input: 2p rubycon ZLH 470u 100v
- no 10u ceramic input caps

Heat sink: 100x100x18mm aluminium (~3-5 €)

- ls rise time 262NS
  - FALL 176NS
  - too much?
- when connecting the gate discharge r 2.2, it fails (boot strap supply UV, failure)
- hs r/ftime = 50ns (good)

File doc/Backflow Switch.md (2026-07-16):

The backflow switch prevents current flow from the battery through the converter and the solar panels at night.

It ensures safe shutdown in case of shorted solar terminals.

To better understand, why it is needed, take a look at this equivalent circuit diagram of the converter, which includes
the power mosfets body diodes and the coil only:

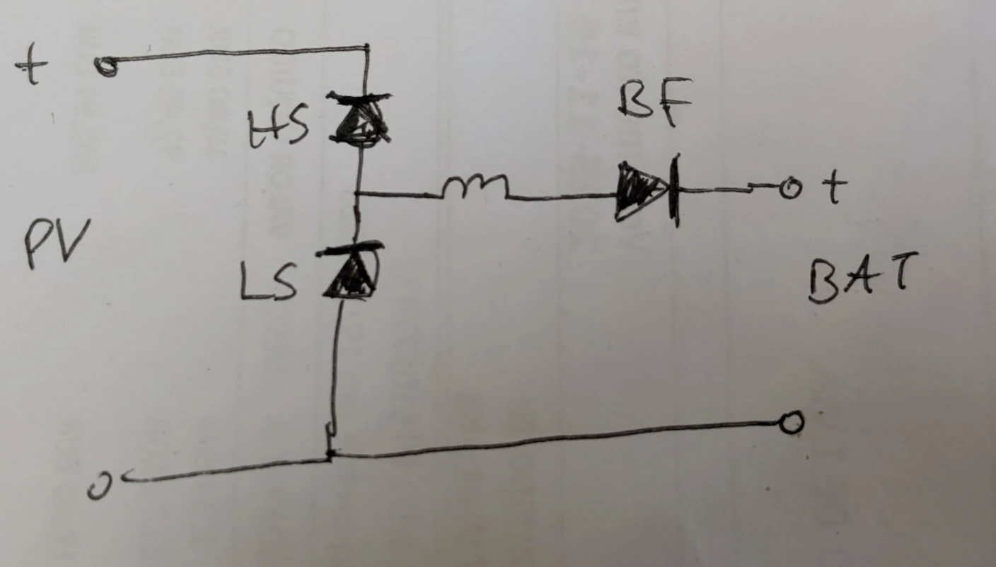
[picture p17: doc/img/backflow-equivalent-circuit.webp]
backflow equivalent circuit


(HS: High-side mosfet, LS: low-side MOSFET, BF: backflow switch)

## Location

There are 4 locations where the backflow switch can be placed:

* Bat(+)
* Bat(GND)
* Solar(+)
* Solar(GND)

The current at the Solar (high-voltage) side is less, so conduction loss will be lower. Notice that the
maximum blocking voltage is the battery voltage, not the solar voltage. So with 60V battery voltage, a 80V switch is
sufficient,
even with 100V solar voltag
Putting the backflow switch on the battery (low-voltage) side comes with fail-safe benefits in these 2 situations:

(1) In case of a shorted HS Mosfet, solar current will flow unregulated into the battery. With lithium batteries,
the BMS will cut charging at some point when the end-of-charge voltage is reached. Then the solar voltage is present at
battery terminals, which might destroy any connected loads.
Just opening the backflow switch will not help here, because of the body diode. We can permanently turn on the LS
switch, which will short the solar voltage and stop any battery current, protecting the charger output against over-voltage.

(2) In case of a shorted LS switch the backflow switch on the battery side can prevent a burned fuse.

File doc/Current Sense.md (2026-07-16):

## High-side current sensing

* immune to ground connecting errors, leakage
* works in an non-isolated power-loop rig (buck output connected to boost input and boost output to buck input)
* can monitor coil current if bandwidth is sufficiently high (x10 switching freq?)

how to implement:

* using a high CMRR amplifier (e.g. INA226, INA228)
* or heaper: put op amp supply to power rail (+) and a supply that creates -5V from power rail (+). open collector output
  builds a current source that allows level-shift to ground through a resistor:
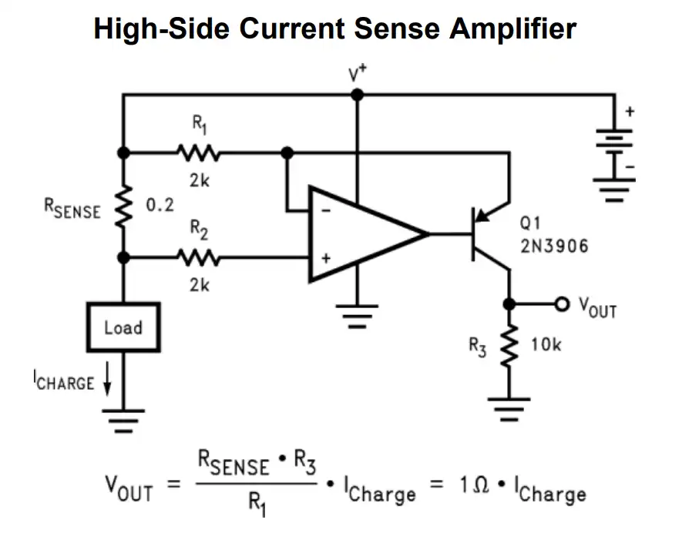
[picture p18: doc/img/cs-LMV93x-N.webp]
   (from the LMV93x-N datasheet)

## low side current sensing
* simpler and cheaper

## bi-directional current sensing
* independently of high- or low-side measurement
* buck hardware can become boost hardware by swapping input and output
* detect faults that cause reverse current 

# Design Notes / Literature

* [pcb: INA226 datasheet](https://www.ti.com/lit/ds/symlink/ina226.pdf#page=30) 
* Current sense filtering https://www.ti.com/lit/ds/symlink/ina226.pdf#page=14

[Current-sensing techniques for DC-DC converters](https://rincon-mora.gatech.edu/publicat/cnfs/mw02_isns.pdf), H.P. Forghani-zadeh et
al.

* series sense resistor
* Rds sensing
* filter-sense inductor
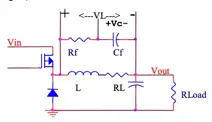
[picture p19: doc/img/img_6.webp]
* 
* 
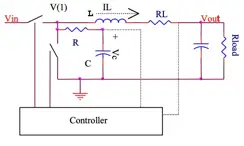
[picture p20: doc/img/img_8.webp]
* 
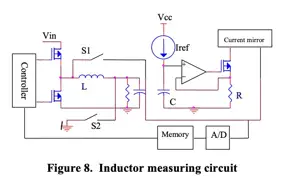
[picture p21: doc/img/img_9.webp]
* 

# Amplifiers
Todo this list needs an update

| | | DC CMRR | CMRR @50 kHz | Gain err | TempDrift | Voff  | BW | gains | notes |
|---|---|---|---|---|---|---|---|---|---|
| INA281  | +110 V | 120-dB  | 65-dB | 0.5% | 20ppm | | 1.3MHz | 20..500 | cheapest TI , $1.18 |
| INA310A | 110V | 160dB | | 0.15% | 10ppm | 20uV  | 1.3MHz | 20..500 | int. Comparator $1.53 |
| INA310B | 110V | 160dB | | 0.5% | 20ppm | 150uV | 1.3MHz | 20..500 | int. Comparator |
| INA169  | 60V | | | | | | | | $1.22 |
| INA791x | | | | | | | | | internal 50A EZ-Shunt |

Reject Noise

* 50hz inverter
* 380Hz Power supply
* 39 kHz pwm

A loss-less technique to measure average output current:
Use an RC-Filter to measure average switch node voltage. With this V_sw_avg, Vo and the coil ESR we can compute the
current.
Note that copper has temp coeff a = 0.0043/°C (https://cirris.com/temperature-coefficient-of-copper/), so a temperature
change of 30°C results about 13% error. For an MPPT this is fairly enough, not for precise energy metering though.

https://sci-hub.se/10.1109/MWSCAS.2002.1186927

INA226
INA229

# OP amp / current sense amp

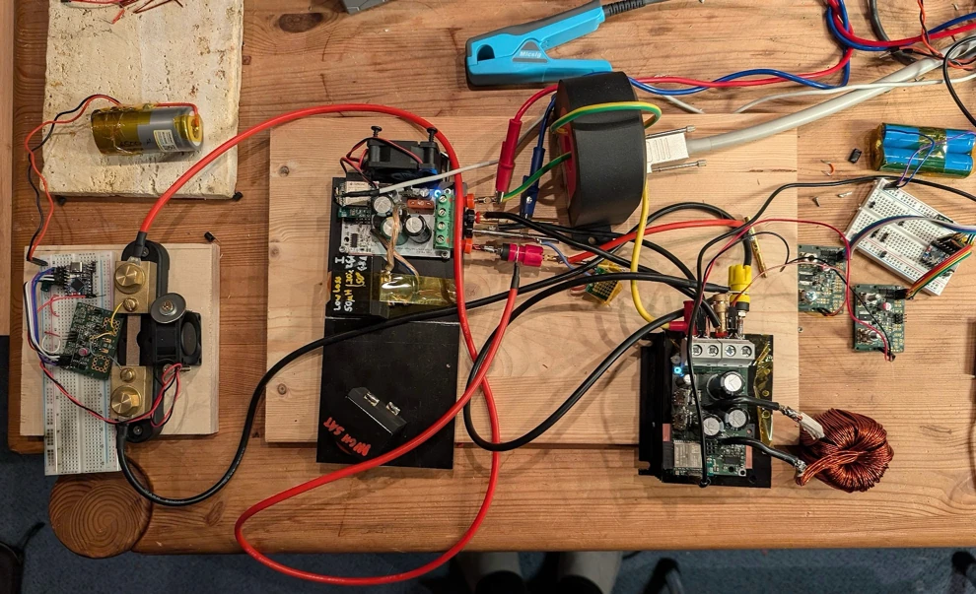
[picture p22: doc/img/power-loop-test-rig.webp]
power-loop-test-rig


the OP amp should have no Vos cross-over distortion, and a low Vos drift

* LMV931SQ3T2G (onsemi) is $0.18
* MMBT3906 (onsemi) is a SMD substitute for 2N3906 (PNP BJT, 40V, 200mA)
* for Vbat up to 60V: BC856BLT1G (65V, 100mA) or MMBT2907ALT1G (60V, 600mA) or MMBTA56LT1G (80V, 500mA), all ~300MHz

* MCP6C02 https://www.mouser.de/datasheet/2/268/Zero_Drift_65V_High_Side_Current_Sense_Amplifier_D-3444102.pdf
    * already comes with level-shift
    * 68V common mode
    * VOS: ±1.65 μV (typic
    * CMRR: 154 dB (typical)


https://www.analog.com/media/en/technical-documentation/data-sheets/ltc2063-2064-2065.pdf

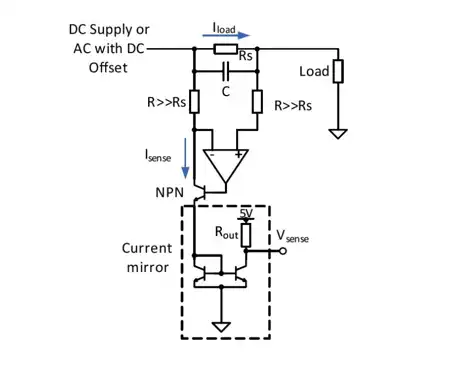
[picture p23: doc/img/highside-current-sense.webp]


from https://www.mouser.com/pdfDocs/RECOMACDCBOOKOFKNOWLEDGE.pdf#page=181
from https://recom-power.com/en/acdc-bok-chapter13-measuring.html?0 (AC/DC book of knowledge)

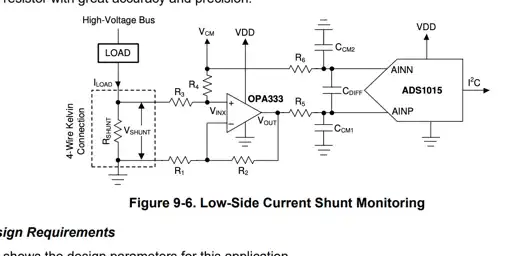
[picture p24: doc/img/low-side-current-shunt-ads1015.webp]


OPA333:

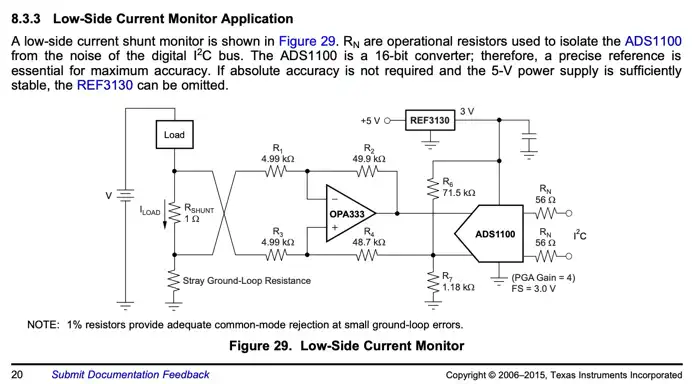
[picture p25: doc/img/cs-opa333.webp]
cs-opa333.web


# Simulations

[low-side bi-directional](https://www.falstad.com/circuit/circuitjs.html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)

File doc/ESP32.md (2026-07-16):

ESP32 vs ESP32-S3

The ESP32 has a higher bandwidth ADC and PWM high-speed mode for "glitch free" transition, whatever this means.
see LED Control (LEDC) https://docs.espressif.com/projects/esp-idf/en/stable/esp32/api-reference/peripherals/ledc.html

| | ESP32 | ESP32-S3 |
|---|---|---|
| ADC SPS | 2M | 83.3k |
| PWM high-speed mode | y | n |
| USB phy | n | y |
| heap RAM | | |
| | | |

https://github.com/UnexpectedMaker/esp32s3/blob/main/schematics/schematic-omgs3.pdf

* Programming /flashing over USB
    * need BOOT button, as when chip is in panic boot loop, unable to put it in download mode over USB

Mounting the ESP32-S3 on a small break out enables easy replacement.
We can choose another chip with a different footprint.
MCU specific interfaces (USB etc) that do not belong to the board
can be moved to that break out.

KiCad SMD 2.54mm pin headers are ordinary 90deg THT headers with the odd pins
twisted. An SMD footprint of such headers can be placed inside the ESP32-S3-WROOM
footprint.
[SMD 2.54mmpin header](https://pt.farnell.com/fischer-elektronik/sl11-smd-062-40s/header-pin-2-54mm-40way/dp/9729046)

# Pin Considerations

check the [ESP32-S3 datasheet](https://www.espressif.com/sites/default/files/documentation/esp32-s3_datasheet_en.pdf)

* Vcc GND
* EN not normally not needed. The MCU can sleep and wake-up. The EN is just needed for programming
* Some pins have start up glitches (GPIO1-17 low, GPIO18-20 high!). don't use this for pwm signals
    * GPIO >= 21 for outputs
* ADC1 channels are useful (ADC2 conflicts with WiFi)
* SPI native pins?

Rust Dev Board Kicad https://github.com/esp-rs/esp-rust-board/tree/master/hardware/esp-rust-board
Power Supply https://www.espressif.com/sites/default/files/documentation/esp32-s3_datasheet_en.pdf#cd-pwr-supply

| | Int. Flash | PSRAM | Ambient Temp. Max |
|---|---|---|---|
| ESP32-S3-WROOM-1U-N4R2 | | | 85 |
| ESP32-S3-WROOM-1U-H4 | | | 105 |
| ESP32-S3-WROOM-1-H4 | | | 105 |

# Flash and PSRAM

* PSRAM resides in the ESP-S3 chip
* Flash is inside the WROOM metal enclosure, connected to the ESP32 chip with SPI
* Flash has 100k erase cycles

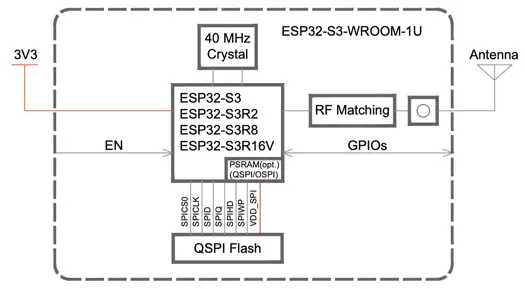
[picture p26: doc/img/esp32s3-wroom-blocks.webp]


# Antenna Connector

* U.FL Series connector from Hirose
* MHF I connector from I-PEX
* AMC connector from Amphenol
  https://www.digikey.pt/en/products/detail/seeed-technology-co-ltd/103990623/18724506

| MPN | Type | Freq | Gain | cable | Px | |
|---|---|---|---|---|---|---|
| Seeed XIAO ESP32C3 | Rod  | 2.45GHz | 2.81dBi | | 2€ | [digikey](https://www.digikey.pt/en/products/detail/seeed-technology-co-ltd/103990623/18724506) |
| Ezurio MAF94045 | PCB  | 2.4GHz | 2dBi | 10cm  | 1.3€ | [digikey](https://www.digikey.pt/en/products/detail/ezurio/MAF94045/2392209) |
| Ezurio MAF95310 | PCB  | 2.45GHz, 5GHz | 2.8dBi, 3.4dBi | 18cm  | 1€ | [digikey](https://www.digikey.pt/en/products/detail/ezurio/MAF95310/5876486) |
| Inventek W24P-U | PCB  | 2.4GHz | 3.2dBi | 9cm | 1.3€ | [digikey](https://www.digikey.pt/en/products/detail/inventek-systems/W24P-U/4488778) |
| Inventek W2.4-5P-U | PCB  | 2.4GHz, 5Ghz  | 2.6dBi, 3.3dBi | 9cm | 1.5€ | [digikey](https://www.digikey.pt/en/products/detail/inventek-systems/W2-4-5P-U/4965325) |
| Fanstel ANT060 | Rod  | 2.45GHz | 6dBi | 10cm  | 2.9€ | [digikey](https://www.digikey.pt/en/products/detail/fanstel-corp/ANT060/8323643) |

# Dev Boards

## Unexpected Maker Nano

https://lectronz.com/products/nanos3
um-nanos3

* pricy
* 

## WaveShare
https://www.waveshare.com/esp32-s3-zero.htm

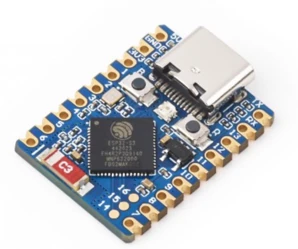
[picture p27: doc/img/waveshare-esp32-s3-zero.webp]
waveshare-esp32-s3-zero


* has thermal issues (over-heat) without heat-sink
* had wifi connection issues. antenna performance is lower than WROOM PCB antenna

https://github.com/femtoduino/femu-hardware/tree/master/femu/kicad/femu
esp32-rust

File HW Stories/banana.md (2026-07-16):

mounted on an 10x10x1.4cm heatsink

# Power Rig Test

* V = 73.7/27
* Iout = 31.5A
* rig supply: 27V, 1.93A
* onboard temp (ntc): 74°C
* coil temp: 100°C
* thermocouple on PCB between caps: 80°C
  * probably heat transfer through wires from coil
* heatsink temp 58°C

put 2sMS184075 coil:
- now 32.8A
- rig supply: 1900mA

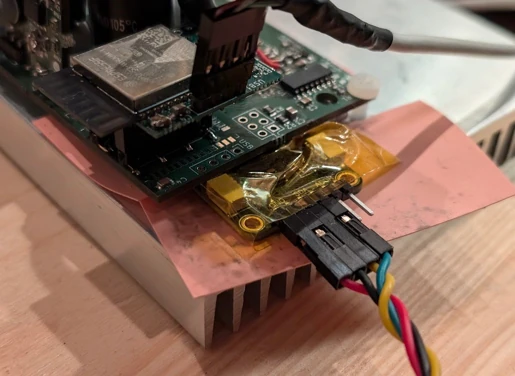
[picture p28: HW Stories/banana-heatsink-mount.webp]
banana-heatsink-mount


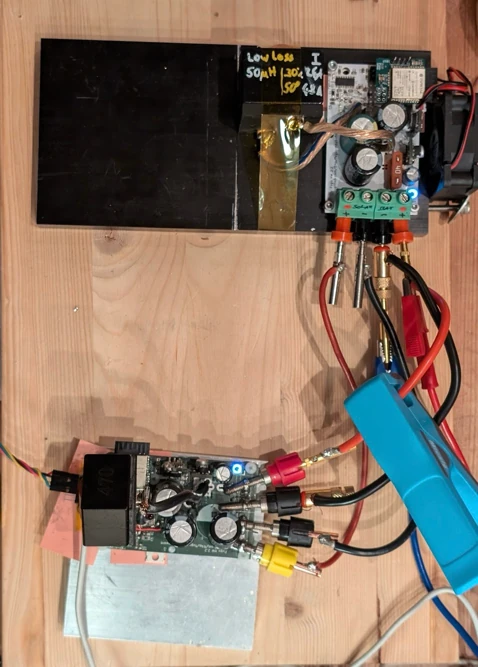
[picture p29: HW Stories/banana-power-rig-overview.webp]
banana-power-rig-overview


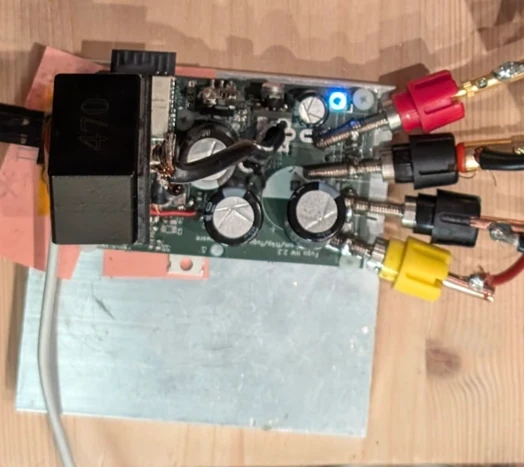
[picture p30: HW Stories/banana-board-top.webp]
banana-board-top


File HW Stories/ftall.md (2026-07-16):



- Board: Fugu HW 2.2
- Switches: (both 100V breakdown)
    - Low: 2p IPA050N10NM5S?  (gdrv: 4.7R)
    - HS: 2x  (gdrv: 4.7R, discharge: 0R)
- Inductor:
    - codacoa high sat 70µH
- Caps:
    - in: 2x Rubycon ZLH 470uF 100V 16mmx31mm (Z=33mΩ each)
    - out: 1x "

```
power loop
Isupply=2.05A
Iout=33A
V=73.8/26.10 I=xxx   xxW 68℃44℃ 443sps  0㎅/s CCM(H|L|Lm)= 786|1261|1261 st= MANU,1 lag=3126㎲ N=2080320 rssi=-50

now cold:
V=74.4/26.06 I=xxx   xxW 28℃28℃  0sps  0㎅/s CCM(H|L|Lm)= 786|1261|1261 st= MANU,1 lag=3090㎲ N=7797 rssi=0
Iout=34.4
Isupply=2.02A

```

```
eff 97.95% (std=0.000353)   loss=16.61W
   in power     812.028 W  (std 0.0255)   @ 71.519V
  out power     795.423 W  (std 0.0257)   @ 27.122V

eff 97.89% (std=0.170010,last=97.97)   loss=17.01W
   in power     788.086 W  (std 7.9790)   @ 71.578V
  out power     772.096 W  (std 8.3676)   @ 27.120V

voltage adcs: 2x ina228, isolated from each other
input current sensor: RSN20-50 with ina228 calibrated to <60ppm error with DCCT + HP3458A
output current sensor: DCCT and HP3458A .

   in power     788.620 W  (std 0.0287)   @ 71.577V
  out power     772.649 W  (std 0.0302)   @ 27.120V
eff 97.98% (std=0.000474,last=97.97)   loss=15.97W

eff 98.24% (std=0.005989,last=98.24)   loss=8.17W
   in power     465.221 W  (std 0.9677)   @ 72.299V
  out power     457.042 W  (std 0.9562)   @ 27.119V

the next day (and new ina228 chip):
eff 97.88% (std=0.013967,last=97.89)   loss=15.06W
   in power     709.154 W  (std 0.0703)   @ 73.888V
  out power     694.208 W  (std 0.0469)   @ 27.104V

eff 97.93% (std=0.001362,last=97.93)   loss=17.03W     <- yesterday it was 97.95%, so yeah so close!! (consider thermal)
   in power     821.922 W  (std 0.0713)   @ 73.950V
  out power     804.892 W  (std 0.0774)   @ 27.112V

now with the small 47u coil (lcsc):
eff 97.77% (std=0.002032,last=97.76)   loss=18.28W
   in power     818.743 W  (std 0.0407)   @ 71.434V
  out power     800.461 W  (std 0.0235)   @ 27.118V
  
after letting everything warm up and applied some forced heat to reach thermal steady state:
eff 97.69% (std=0.001544,last=97.69)   loss=18.70W
   in power     810.185 W  (std 0.0403)   @ 71.490V
  out power     791.442 W  (std 0.0350)   @ 27.126V
  
ms-184075 14T coil: TODO ripple
eff 98.12% (std=0.000000,last=98.12)   loss=15.11W
   in power     803.377 W  (std 0.0000)   @ 71.480V
  out power     788.265 W  (std 0.0000)   @ 27.121V
after warm-up:
eff 98.08% (std=0.001085,last=98.08)   loss=15.50W
   in power     805.414 W  (std 0.0607)   @ 71.524V
  out power     789.918 W  (std 0.0592)   @ 27.134V

```

```
ruishen 700 coil: (ipp=9.82A@39khz)
eff 98.03% (std=0.314417,last=97.91)   loss=16.10W
   in power     820.213 W  (std 2.4756)   @ 71.473V
  out power     803.070 W  (std 1.1517)   @ 27.133V
  
after warmup:
eff 97.88% (std=0.000539,last=97.88)   loss=17.35W
   in power     819.254 W  (std 0.0585)   @ 71.468V
  out power     801.910 W  (std 0.0560)   @ 27.127V
eff 97.87% (std=0.000305,last=97.87)   loss=17.42W
   in power     816.609 W  (std 0.0030)   @ 71.473V
  out power     799.209 W  (std 0.0038)   @ 27.126V
```

```
T184-075 with 2 big strands, 17? turns (ipp=13.86)
eff 96.51% (std=0.001071,last=96.51)   loss=28.95W
   in power     830.910 W  (std 0.3730)   @ 71.403V
  out power     801.941 W  (std 0.3624)   @ 27.119V
  
=> this coil is bad for some reason
```

```
other double strand coil KS184125A (KDM) TODO Iripple?
eff 97.92% (std=0.000000,last=97.92)   loss=17.00W      < wow this is supringly good for
   in power     816.153 W  (std 0.0000)   @ 71.483V     < a single T184 core
  out power     799.137 W  (std 0.0000)   @ 27.132V
after warm up:
eff 97.89% (std=0.001153,last=97.89)   loss=17.22W
   in power     814.696 W  (std 0.0588)   @ 71.491V
  out power     797.466 W  (std 0.0601)   @ 27.130V
```

```
"too many" turns coil (ipp=12.5A)
eff 97.79% (std=0.000000,last=97.79)   loss=18.16W
   in power     820.038 W  (std 0.0000)   @ 71.474V
  out power     801.878 W  (std 0.0000)   @ 27.139V
after warmup 2min:
eff 97.73% (std=0.000559,last=97.73)   loss=18.55W
   in power     818.913 W  (std 0.0226)   @ 71.466V
  out power     800.382 W  (std 0.0233)   @ 27.128V
eff 97.69% (std=0.000699,last=97.69)   loss=18.84W
   in power     815.913 W  (std 0.0333)   @ 71.476V
  out power     797.105 W  (std 0.0358)   @ 27.124V
```

```
2s T130-060 19 turns 13.2AWG, with "earthing" wire  ~7W loss?
eff 97.83% (std=0.000000,last=97.83)   loss=17.77W
   in power     817.746 W  (std 0.0000)   @ 71.440V
  out power     800.012 W  (std 0.0000)   @ 27.126V
warm:
eff 97.77% (std=0.005876,last=97.77)   loss=18.17W
   in power     815.107 W  (std 0.0707)   @ 71.439V
  out power     796.950 W  (std 0.0880)   @ 27.117V
  
micrometals analyzer:
Core Loss (W)	3.577
Rdc (Ω)	        0.008333                                < measured: 4.75Ω
Rac Factor	    7.921
Cu Loss (W)	    10.13
Total Loss (W)	13.71                                   < vs 18W total converter loss???, sth is wrong here)
```

```
another "unknown" 2stack T130 2strands
eff 97.81% (std=0.000000,last=97.81)   loss=17.96W
   in power     818.373 W  (std 0.0000)   @ 71.475V
  out power     800.430 W  (std 0.0000)   @ 27.135V

eff 97.76% (std=0.002451,last=97.76)   loss=18.25W
   in power     814.703 W  (std 0.1072)   @ 71.479V
  out power     796.424 W  (std 0.1213)   @ 27.129V  

```

```
another 2stack T130 1strand "dark" (high temp drift)
eff 97.31% (std=0.000000,last=97.31)   loss=22.18W
   in power     823.757 W  (std 0.0000)   @ 71.439V
  out power     802.031 W  (std 0.0000)   @ 27.127V
eff 97.15% (std=0.009163,last=97.14)   loss=22.71W
   in power     796.010 W  (std 0.6710)   @ 71.506V
  out power     773.237 W  (std 0.7197)   @ 27.112V
```
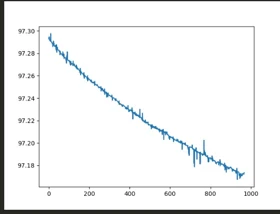
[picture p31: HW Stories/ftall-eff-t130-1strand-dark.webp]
ftall-eff-t130-1strand-dark


```
T130 2stack 6strands (ipp=22A)
eff 97.80% (std=0.000000,last=97.80)   loss=18.19W
   in power     825.300 W  (std 0.0000)   @ 71.456V
  out power     807.063 W  (std 0.0000)   @ 27.127V
warm:
eff 97.69% (std=0.000396,last=97.69)   loss=18.87W
   in power     818.586 W  (std 0.0473)   @ 71.463V
  out power     799.717 W  (std 0.0462)   @ 27.119V
```
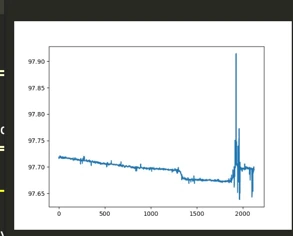
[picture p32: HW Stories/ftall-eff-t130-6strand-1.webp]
ftall-eff-t130-6strand-1

ftall-eff-t130-6strand-2

```
codaca low loss (ipp=16.64A)
eff 98.07% (std=0.000000,last=98.07)   loss=15.85W      < vs "high sat" eff: 97.88%
   in power     821.925 W  (std 0.0000)   @ 71.498V
  out power     806.072 W  (std 0.0000)   @ 27.141V
warm:
eff 98.06% (std=0.003044,last=98.06)   loss=16.06W
   in power     827.109 W  (std 0.1596)   @ 71.510V
  out power     811.067 W  (std 0.1500)   @ 27.146V
after 30h mins:
eff 98.042% (std=0.000922,last=98.04)   loss=16.14W
   in power     824.321 W  (std 0.0473)   @ 71.502V
  out power     808.185 W  (std 0.0462)   @ 27.141V
  
put HS gate discharge resistor 2.2ohm:
eff 98.116% (std=0.001012,last=98.12)   loss=14.89W
   in power     790.514 W  (std 0.0354)   @ 71.587V
  out power     775.624 W  (std 0.0350)   @ 27.140V
```

ftall-eff-codaca-lowloss-1
ftall-eff-codaca-lowloss-2
eff over time samples. applied some forced heat during warm-up

Here's a plot over time of converter efficiency (sampling rate ~4 Hz).
ftall-eff-over-time-fan

The spikes are me touching the converter. Just before x=500 I put a fan next to the converter.
This increased eff by almost 0.05%. As you can see afterwards it takes a long time to reach the steady state of
thermal equilibrium. It also looks like the converter doesn't fall back to its initial

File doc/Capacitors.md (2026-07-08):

# Two roles: ripple (electrolytic) vs. spikes (ceramic)

The input cap bank does two physically separate jobs, split across the two cap types:

| | Electrolytic (bulk) | Ceramic (hot-loop MLCC) |
|---|---|---|
| absorbs | 39 kHz sawtooth ripple | MHz commutation spikes (Qrr/Qoss) |
| limited by | ESR → **loss** | ESL → **loop area / Vds overshoot** |
| purpose | ripple current, bulk energy | EMI, switch-node overshoot, rail hold-up |
| size for | RMS ripple + ESR rating | low ESL, small loop, hold-up during spike |

**The electrolytics own the loss; the ceramics own the HF behaviour.** Ceramics are
*not* an efficiency part — they cut HF noise/EMI and Vds overshoot, not power loss.

## Loss split (Fugu2 @ 72→27 V, 30 A, D = 0.375, 39 kHz)

Ripple (→ electrolytics). At 39 kHz the electrolytics are low-Z (~17 mΩ) and the
ceramics high-Z (~194 mΩ), so >90 % of the ripple flows through the electrolytics:

$$ I_{cin,rms} = I_O\sqrt{D(1-D)} \approx 14.3\,\text{A} $$
$$ P_{ripple} \approx I_{cin,rms}^2 \cdot ESR_{elec} \approx 14.3^2 \cdot 16.5\,\text{m}\Omega \approx 3.4\,\text{W} $$

This is essentially the *whole* Cin loss.

**Temperature does *not* help here.** Aluminium-electrolytic ESR is strongly
temperature-dependent only on the **cold** side (below 20 °C, where the electrolyte
stiffens). *Above* 20 °C the impedance/ESR is nearly flat — per Rubycon's own curve
(technical note Fig. 14, `Zt/Z(20°C)`) the impedance ratio is ~1.0 at 20 °C, ~0.95 at
60–70 °C, ~0.90 at 105 °C, and the ZLH tan δ curve (Fig. 15) is flat from 20 °C to
105 °C. So hot ESR is only ~4–5 % below the 20 °C spec → **no meaningful hot
derating** (an earlier estimate of "~2 W hot" was wrong; it's ~3.2–3.4 W hot too).
Second-order, 39 kHz is *below* the 100 kHz spec point, so real ESR at 39 kHz is if
anything slightly *higher* than the datasheet 33 mΩ. Net: the 20 °C / 100 kHz value
is a good, slightly-conservative estimate; the tool's ~3.4 W is essentially correct.

Spikes (→ ceramics). Per HS turn-on the ceramics deliver Qrr + Qoss ≈ 860 nC in
~18 ns (≈48 A peak), but that is only **0.73 A rms**. The spike is a **tens-of-MHz**
event, so it sees the ceramic's **ring-band ESR ~26 mΩ**, *not* the ~3–5 mΩ 50 kHz /
SRF-floor value (reading a MHz phenomenon off the low-frequency ESR is the same
wrong-band trap as reading electrolytic ESR at the wrong point). That gives
0.73² · 26 mΩ ≈ **14 mW** — still **negligible** (~250× below the ripple; the spike RMS
is ~20× smaller). The electrolytics **can't** supply these spikes (their ~11 nH ESL is
near-open at MHz) — that is why the ceramics sit in the hot loop. (Ring-band ESR and the
DC-bias'd SRF: `dcdc-tools/loss/docs/ring.md`.)

> The Qrr/Qoss *energy* (~0.6 + 1.0 W) **is** a real loss, but it is dissipated in the
> **FET channels** (counted as P_rr / P_coss in the loss budget), not the caps.

## How to reduce P_cin (and what doesn't)

`P_cin = I_cin,rms² · ESR`, and for a buck the input-cap ripple current is set by the
**chopped DC load current**, not by the inductor ripple:

$$ I_{cin,rms}^2 = \underbrace{I_O^2\,D(1-D)}_{\text{chopped DC — fixed}} + \underbrace{\tfrac{D\,\Delta I_L^2}{12}}_{\text{inductor ripple — tiny}} $$

For Fugu2 (32 A, D = 0.375, L ≈ 50 µH → ΔI_L ≈ 8.6 A pp): term 1 ≈ **240 A²**,
term 2 ≈ **2.3 A²** (< 1 %). So the loss is almost entirely the chopped DC term.

| lever | effect on P_cin | why |
|---|---|---|
| **more electrolytics ∥ / lower-ESR parts** | ✅ **P_cin ∝ 1/N** | same ripple current splits over N caps → ESR/N; also cooler → longer life |
| raise f_sw | ❌ ~none | `I_cin,rms = Io·√(D(1−D))` is **independent of f_sw**; only shrinks ripple *voltage*, and raises FET + core loss |
| raise L | ❌ ~none (~25 mW) | only shrinks term 2; doubling L saves <1 % of I_cin,rms². And on Fugu2 → more turns → **higher DCR** (the dominant loss) |

The classic trap: higher L / higher f_sw reduce the **inductor's triangular ripple**,
which lands in the **output** cap (`I_cout,rms = ΔI_L/√12`), *not* the input cap. The
input cap bursts because the HS FET is fully on/off — a duty-cycle effect L and f_sw
can't change. **The only real Cin lever is ESR: more electrolytics in parallel.**
On this magnetics-limited board that's also cheap vs. touching the coil.

Refs: full loss budget `Fugu2/spice/loss_budget.py`; hot-loop L & overshoot
`Fugu2/spice/PARASITIC_MODELING.md`; ceramic vendor SPICE models (TY/Murata DC-bias)
`Fugu2/spice/extract/capmodels/`.

---

# Ceramic

MLCC have can have poor DC bias performance, resulting capacity drop of around 80% at 80V (100V rated voltage).

https://docs.google.com/spreadsheets/d/1vxxJvD4m8UsKfiyYFJieKQtYqnGDK7agQkgYiSCFPeM/edit?usp=sharing

* X7S (and C0G ?) has lower DC-bias capacitance drop
    * good for snubbers, input caps

**Verified 72 V effective-C** (populated parts, read off the vendor DC-bias curves at the
72 V rail): 220 nF **0.164×**, 1 µF **0.195×**, 10 µF **0.157×**. The **10 µF derates the
*hardest*** (a "10 µF" contributes only ~**1.57 µF** at the rail), the 1 µF the least — bigger
case ≠ automatically better, so budget effective C accordingly.

> Per-part ESR(f) / ESL / DC-bias curve values, the cross-check that the TY/Murata SPICE models
> are datasheet-faithful, the SRF-into-ring-band effect, and **how the loss tool resolves caps
> by value-bucket (not MPN)** are in the tool repo: `dcdc-tools/loss/docs/capacitors.md`
> (mechanism: `dcdc-tools/loss/docs/ring.md`).

## Which ceramics carry the ring (BOM / depopulation)

A **first-cut** ranking splits the commutation-ring current **∝ 1/branch-L** (at tens of MHz,
ωL_b ≫ R_b), from the FastHenry branch inductances (copper geometry):

| cap | branch L | 1/branch-L share |
|---|---|---|
| C18, C9, C17 | 0.80–0.92 nH | **~62 % total** |
| C16 | 1.24 nH | ~14 % |
| C21, C22 (10 µF) | 2.0–3.1 nH | ~9 % / ~6 % |
| **C27** (1 µF) | **5.67 nH** | **~3 %** |

**But `∝ 1/branch-L` is the trunk/scalar approximation — it drops the mutual coupling between
branches, and for a decoupled far cap that is badly wrong.** The authoritative physical port
matrix (ceramic ESL/ESR + all off-diagonals, `--cin-esl/--cin-esr`) has now been run
(`dcdc-tools/loss/cin_physical_split.py`), and it splits into two regimes:

- **f_sw ripple band (100 kHz–1 MHz) — the ESR *heat*.** Capacitance-dominated: the two
  **10 µF C21/C22 carry ~83 % of the current, ~91 % of the MLCC ESR loss**; **C27 ~3 %**. Here
  the 1/branch-L proxy is *wrong the other way* (it says C27 ~3 % for the right reason but ranks
  the small-L near caps top, when the big-C caps actually own the ripple).
- **HF ring (>SRF, ~55 MHz) — inductive.** Mutual coupling matters: the full matrix gives
  **C27 ≈ 26 % of the ring current / 22 % of the ring ESR-loss**, *not* ~3 %. C27 is far/
  decoupled, so it escapes the near-bank's circulating cancellation and carries a clean large
  slice.

**C27 is still a depopulation candidate — but on the *ripple* argument, not the ring one.**
It does ~no f_sw ripple work (~3 % of the ESR heat; a 1 µF ceramic against the electrolytics
that own the ripple), so pulling it costs little filtering. What is **not** true is the earlier
"~3 % at the ring": C27 actually carries ~26 % of the ring *current*. Removing it barely moves
the *aggregate* SW ring/peak (Z_eff is common-mode — the parallel caps back-fill), but do not
justify the pull with the 1/branch-L ring figure. Mechanism + the extractor's automatic depop
flag + the three-band reconstruction: `dcdc-tools/loss/docs/ring.md` §8.

| | | | | | 80V dc-bias | R@1kHz | R@50Khz | px | |
|---|---|---|-----|---|---|---|---|---|---|
| murata GRM31cr60e227 | | | | | | | | | |
| murata GRM32EC72A106KE05L | 10uF  | 100V | X7S | 1210 | 1.4uF | | 5mΩ | 100: 0,47750 €  | [link](https://www.murata.com/en-global/products/productdetail?partno=GRM32EC72A106KE05%23) |
| tdk C5750X7S2A106K230KB | 10uF  | 100V | X7S | | 2.22uF | 162mΩ  | 6.3mΩ | | [link](https://product.tdk.com/en/search/capacitor/ceramic/mlcc/info?part_no=C5750X7S2A106K230KB) |
| tdk CKG57NX7R2A106M500JH | 10uF  | 100V | X7R | | 3.6uF | 104mΩ  | 5.3mΩ | | 5mm MEGACAP!  expensive |
| tdk C3216X6S2A106K160AC | 10uF  | 100V | X6S | | 0.8uF | | 4mΩ | | |
| yuden HMK107C7224KAHTE / MCASH168SC7224 (C17/C18) | 220nF | 100V | X7S | 0603 | -86% (31nF) | | 96m | | [link](https://ds.yuden.co.jp/TYCOMPAS/or/detail?pn=MCASH168SC7224KTCA01&u=M) |
| yuden HMK212BC7105KGHTE (smps) | 1uF | 100V | X7S | 0805 | -83% | 762Ω | 20m | 100 : 0,14650 € | [link](https://ds.yuden.co.jp/TYCOMPAS/ut/detail?pn=MMASH21GBC7105KTCA01&u=M) |
| murata GRJ21BC72A105ME11L | 1uF | 100V | | | 0.165uF | 1.5k | 40m | 100 : 0,10120 € | |
| yuden HMR212CC7105KG-T (bypass) | 1uF | 100V | X7S | 0805 | -82% | 724 | 20m | 100 : 0,12090 € | |
| yuden HMK316AC7225KL-TE (smps) | 2.2 | 100V | | | | | 10m | 100 : 0,16320 | |
| TY MSASH32MSB5475MPCA01 (smps)  <br/> HMK325BJ475MM-PE | 4.7uF | 100V | | | | 130mΩ  | 6mΩ | 100 : 0,17120 € | |

# Electrolytic

| | | | | | |
|---|---|---|---|---|---|
| | | | | | |
| | | | | | |
| | | | | | |

$$ C_{in} >= \frac{D \cdot (1-D) \cdot I_O}{ \Delta V_{in} \cdot f_{sw} }$$

[ref: TIDA-010042 400-W GaN-Based MPPT Charge Controller](https://www.ti.com/lit/ug/tiduej8c/tiduej8c.pdf#page=13)

How to select input capacitors for a buck converter https://www.ti.com/lit/pdf/slyt670

TDK has a
good [parametric search](https://product.tdk.com/de/search/capacitor/ceramic/mlcc/list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)

[Digikey aluminium elec. caps D=16mm](https://www.digikey.de/short/dhw78pnf)

See parts datasheet for rated ripple current. Manufacturers usually specify it at 100khz, 105°C.
You'll usually find impedance as well, which gives you an idea how much power lost in the capacitor.

Loss is proportional to HF impedance, usually specified in the data sheet at 100 kHz.

## Film bulk option

Film caps are plausible as an electrolytic replacement only if we accept more input
ripple, higher switching frequency, or a large off-board/edge-of-board capacitor bank.
They do not remove the buck input-cap RMS-current requirement:

$$ I_{cin,rms} \approx I_O\sqrt{D(1-D)} \approx 15\,\text{A} $$

At the current Fugu2 operating point (72→27 V, 32 A, D≈0.375, 39 kHz), the capacitance
needed for a target input ripple is:

| fsw | 0.2 Vpp, roughly present electrolytic-class ripple | 0.5 Vpp | 1.0 Vpp |
|---:|---:|---:|---:|
| 39 kHz | ~960 µF | ~385 µF | ~190 µF |
| 120 kHz | ~313 µF | ~125 µF | ~63 µF |
| 250 kHz | ~150 µF | ~60 µF | ~30 µF |

So a practical film experiment is not "one film cap" at 39 kHz; it is around
**200 µF** for a 1 Vpp target. At 120 kHz the same 1 Vpp target drops to about
**63 µF**, and at 250 kHz it drops to about **30 µF**. Keep the ceramic hot-loop bank
either way: film bulk replaces the slow switching-ripple/energy role, not the
tens-of-MHz commutation-spike role.

Approximate bank sizes and cost using the cheap shortlisted 20 µF KEMET C4AQCBW5200A3FJ
and 15 µF Eaton EFDKS55K156D132LH. Prices below assume the ~200-piece DigiKey break:
KEMET 20 µF at **$3.61** each (116+ tier) and Eaton 15 µF at **$2.61** each
(140+ tier).

| fsw | target ripple | 20 µF MPN | with 20 µF film | 20 µF price | 15 µF MPN | with 15 µF film | 15 µF price |
|---:|---:|---|---:|---:|---|---:|---:|
| 39 kHz | 0.2 Vpp | C4AQCBW5200A3FJ | 48 pcs = 960 µF | ~$173 | EFDKS55K156D132LH | 64 pcs = 960 µF | ~$167 |
| 39 kHz | 0.5 Vpp | C4AQCBW5200A3FJ | 20 pcs = 400 µF | ~$72 | EFDKS55K156D132LH | 26 pcs = 390 µF | ~$68 |
| 39 kHz | 1.0 Vpp | C4AQCBW5200A3FJ | 10 pcs = 200 µF | ~$36 | EFDKS55K156D132LH | 13 pcs = 195 µF | ~$34 |
| 120 kHz | 0.2 Vpp | C4AQCBW5200A3FJ | 16 pcs = 320 µF | ~$58 | EFDKS55K156D132LH | 21 pcs = 315 µF | ~$55 |
| 120 kHz | 0.5 Vpp | C4AQCBW5200A3FJ | 7 pcs = 140 µF | ~$25 | EFDKS55K156D132LH | 9 pcs = 135 µF | ~$23 |
| 120 kHz | 1.0 Vpp | C4AQCBW5200A3FJ | 4 pcs = 80 µF | ~$14 | EFDKS55K156D132LH | 5 pcs = 75 µF | ~$13 |
| 250 kHz | 0.2 Vpp | C4AQCBW5200A3FJ | 8 pcs = 160 µF | ~$29 | EFDKS55K156D132LH | 10 pcs = 150 µF | ~$26 |
| 250 kHz | 0.5 Vpp | C4AQCBW5200A3FJ | 3 pcs = 60 µF | ~$11 | EFDKS55K156D132LH | 4 pcs = 60 µF | ~$10 |
| 250 kHz | 1.0 Vpp | C4AQCBW5200A3FJ | 2 pcs = 40 µF | ~$7 | EFDKS55K156D132LH | 2 pcs = 30 µF | ~$5 |

The capacitance math improves quickly with frequency, but the system trade changes:
120 kHz and 250 kHz move the input-ripple fundamental closer to / into the conducted
EMI band, and FET/Qrr/Coss/core losses must be re-budgeted rather than scaled only
from the capacitor table.

Current DigiKey shortlist (2026-07-08, USD; bank-cost examples use the shown
quantity break where available; verify stock/price before ordering):

| part | value | voltage | dielectric / role | ESR | size | price basis | 1 Vpp bank |
|---|---:|---:|---|---:|---|---:|---:|
| [Eaton EFDKS55K156D132LH](https://www.digikey.com/en/products/filter/film-capacitors/15-%C2%B5f/62) | 15 µF | 550 V | PP, DC filtering | - | 32 x 22 x 37.8 mm | ~$2.61 @140+ | 13 pcs = 195 µF, ~$34 |
| [Eaton EFDKS70K156D132LH](https://www.digikey.com/en/products/filter/film-capacitors/15-%C2%B5f/62) | 15 µF | 700 V | PP, DC filtering | - | 32 x 22 x 37.8 mm | ~$2.59 @140+ | 13 pcs = 195 µF, ~$34 |
| [KEMET C4AQCBW5200A3FJ](https://www.digikey.com/en/products/filter/film-capacitors/20-%C2%B5f/62) | 20 µF | 650 V | PP, AEC-Q200 DC link | 5.3 mΩ | 42 x 20 x 40.2 mm | ~$3.61 @116+ | 10 pcs = 200 µF, ~$36 |
| [TDK B32776Z0206K000](https://www.digikey.com/en/products/filter/film-capacitors/20-%C2%B5f/62) | 20 µF | 1000 V | PP, DC link | 6 mΩ | 42 x 30 x 45 mm | ~$6.76 | 10 pcs = 200 µF, ~$68 |
| [WIMA DCP4L052007GD4KSSD](https://www.digikey.com/en/products/filter/film-capacitors/20-%C2%B5f/62) | 20 µF | 800 V | PP, AEC-Q200 DC link | 6.2 mΩ | 41.5 x 20 x 39.5 mm | ~$9.62 | 10 pcs = 200 µF, ~$96 |
| [KEMET C4ATDBW5200A30J](https://www.digikey.com/en/products/filter/film-capacitors/20-%C2%B5f/62) | 20 µF | 250 V | PP, DC link / switching | 4.2 mΩ | 42.5 x 28 x 37 mm | ~$13.43 | 10 pcs = 200 µF, ~$134 |

Current LCSC shortlist (2026-07-08, USD; live stock/prices, verify before ordering):

| part | LCSC | value | voltage | package | stock | price basis | 1 Vpp bank | notes |
|---|---|---:|---:|---|---:|---:|---:|---|
| [XIAMEN FARATRONIC C3D1U206JF0BC00](https://www.lcsc.com/product-detail/C783659.html) | C783659 | 20 µF | 600 V | TH, P=37.5 mm | 284 | ~$2.07 @126+ | 10 pcs = 200 µF, ~$21 | best confirmed 20 µF LCSC fit |
| [KYET C3D206K2H2702P](https://www.lcsc.com/product-detail/C51939908.html) | C51939908 | 20 µF | 500 V | TH, P=27.5 mm | 65 | ~$1.30 @30+ | 10 pcs = 200 µF, ~$13 | cheap, but low stock and 85 °C |
| [HONGFA HCDB/1U1505KB420](https://www.lcsc.com/product-detail/C5128961.html) | C5128961 | 15 µF | 600 V | DIP-4, P=27.5 mm | 176 | ~$1.34 @100+ | 13 pcs = 195 µF, ~$17 | good price, stock below 200 |
| [KYET KP106J2E2701](https://www.lcsc.com/product-detail/C5116053.html) | C5116053 | 10 µF | 250 V | TH, P=27.5 mm | 2128 | ~$0.41 @100+ | 20 pcs = 200 µF, ~$8 | very cheap, twice the placements |
| [KYET MPBH106K2H2701](https://www.lcsc.com/product-detail/C18214247.html) | C18214247 | 10 µF | 500 V | TH, P=27.5 mm | 2726 | ~$0.53 @30+ | 20 pcs = 200 µF, ~$11 | better voltage margin than the 250 V part |

Using the LCSC Faratronic 20 µF part at the 126+ price, the same 20 µF bank table
becomes approximately: 39 kHz = **$99 / $41 / $21** for 0.2 / 0.5 / 1.0 Vpp,
120 kHz = **$33 / $14 / $8**, and 250 kHz = **$17 / $6 / $4**.

First prototype picks: **10x LCSC C783659**, **10x KEMET C4AQCBW5200A3FJ**, or
**13x Eaton EFDKS55K156D132LH**. The LCSC 10 µF KYET options are cheaper, but they
double placement count and need a datasheet check for ripple-current/thermal limits.
Avoid the 100 V film parts for this role unless the input is truly clamped well
below 100 V; many of the attractive 100 V listings are polyester and leave little
transient margin for a solar input.

## Rubycon

* [Rubycon Catalog](https://www.rubycon.co.jp/wp-content/uploads/catalog/aluminum-catalog.pdf)
* [Rubycon PX Series](https://www.digikey.de/en/htmldatasheets/production/1059592/0/0/1/16px100mefc5x11)

* ZL low imp.
    * ZLH long life
        * ZLJ high ripple
        * ZLQ mini (up to 35V)

## Selection

Round 100 V electrolytic picks for the input bulk positions, using **35 mΩ max** as
the practical impedance filter. Board footprints cover 7.5 mm lead pitch with 16 mm
and 18 mm cans; check enclosure height before using the 40 mm parts. Prices are live
distributor checks from 2026-07-08. The preferred basis is the DigiKey 200-piece
break; where DigiKey did not expose that break in public indexed data, the nearest
visible break is shown.

| mfr, series | cap | v | D | L | ripple @100 kHz | imp @20°C/100 kHz | price basis | px/Z | MPN / supplier |
|---|---:|---:|---:|---:|---:|---:|---:|---:|---|
| Rubycon ZLH | 470 µF | 100 | 16 | 31.5 | 2.40 A | **33 mΩ** | ~$1.17 @200, $233.22/200 | ~$0.035/mΩ | [100ZLH470MEFCGC16X31.5](https://www.digikey.com/en/products/detail/rubycon/100ZLH470MEFCGC16X31-5/3568260) |
| Rubycon ZLJ | 470 µF | 100 | 16 | 31.5 | 2.64 A | **32 mΩ** | ~$1.37 @200, $273.03/200 | ~$0.043/mΩ | [100ZLJ470M16X31.5](https://www.digikey.com/en/products/detail/rubycon/100ZLJ470M16X31-5/3133973) |
| Chemi-Con KZN | 680 µF | 100 | 16 | 40 | higher than KZE | **<30 mΩ class** | ~$2.11 @50 | >~$0.070/mΩ | [EKZN101ELL681ML40S](https://www.digikey.com/en/products/detail/chemi-con/EKZN101ELL681ML40S/4843960) |
| Chemi-Con KZE | 470 µF | 100 | 16 | 31.5 | 1.85 A | **32 mΩ** | ~$2.27 @50, 200 not exposed | ~$0.071/mΩ @50 | [EKZE101ELL471MLN3S](https://www.digikey.com/en/products/detail/chemi-con/EKZE101ELL471MLN3S/4001432) |
| Rubycon ZLJ | 680 µF | 100 | 16 | 40 | 3.15 A | **20 mΩ** | ~$1.73 @200, $345.83/200 | ~$0.086/mΩ | [100ZLJ680M16X40](https://www.digikey.com/en/products/detail/rubycon/100ZLJ680M16X40/3133975) |
| Rubycon ZLJ | 680 µF | 100 | 18 | 35.5 | 3.15 A | **20 mΩ** | ~$2.48 @200, $496.32/200 | ~$0.124/mΩ | [100ZLJ680M18X35.5](https://www.digikey.com/en/products/detail/rubycon/100ZLJ680M18X35-5/3564783) |
| Chemi-Con KYB | 470 µF | 100 | 16 | 31.5 | 2.40 A | **22 mΩ** | ~$3.51 @1, limited stock | ~$0.160/mΩ | [EKYB101ELL471MLN3S](https://www.digikey.com/en/products/detail/chemi-con/EKYB101ELL471MLN3S/4843834) |
| Chemi-Con KZE | 680 µF | 100 | 16 | 40 | 2.20 A | **27 mΩ** | DigiKey page, 200 not exposed | - | [EKZE101ELL681ML40S](https://www.digikey.com/en/products/detail/chemi-con/EKZE101ELL681ML40S/4001435) |
| Chemi-Con KZE | 680 µF | 100 | 18 | 35.5 | 2.20 A | **27 mΩ** | DigiKey page, 200 not exposed | - | [EKZE101ELL681MMP1S](https://www.digikey.com/en/products/detail/chemi-con/EKZE101ELL681MMP1S/756261) |
| Chemi-Con KZE | 560 µF | 100 | 16 | 35.5 | 2.00 A | **29 mΩ** | DigiKey page, 200 not exposed | - | [EKZE101ELL561MLP1S](https://www.digikey.com/en/products/detail/chemi-con/EKZE101ELL561MLP1S/756260) |
| Rubycon ZLJ | 820 µF | 100 | 16 | 40 | 3.71 A | **18 mΩ** | check stock/height | - | 100ZLJ820M16X40 |
| Rubycon ZLJ | 820 µF | 100 | 18 | 35.5 | 3.71 A | **18 mΩ** | check stock/height | - | 100ZLJ820M18X35.5 |

Older / unresolved references:

| mfr, series | cap | v | D | L | ripple @100 kHz | imp @20°C/100 kHz | price basis | MPN |
|---|---:|---:|---:|---:|---:|---:|---:|---|
| Rubycon PX | 470 µF | 100 | 16 | 26 | 1.06 A | <60 mΩ? | - | - |
| Nichicon HE(M) | 470 µF | 100 | 16 | 36 | 1.9 A | 45 mΩ | - | - |
| BERYL RC | 470 µF | 100 | 16 | 26 | 1.98 A | 60 mΩ | - | LCSC C365811 |
| Samyoung NXA | 470 µF | 100 | 16 | 31.5 | 1.85 A | 32 mΩ | - | [pdf](https://www.samyoung.co.kr/download/new/NXA.pdf) |
| Nichicon UHE | 680 µF | 100 | 18 | 35.5 | 1.89 A | 40 mΩ | ~$1.00 @100 LCSC | UHE2A681MHD / LCSC C340710 |

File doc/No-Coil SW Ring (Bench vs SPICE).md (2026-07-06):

# No-Coil SW-Node Ring — Bench vs SPICE

Investigation of the half-bridge switch-node (SW) waveform during a **coil-disconnected
bench test**, and the reconciliation of an over-predicting LTspice model against the scope.
The short version: **the real board is benign** (small overshoot, no avalanche); the sim
over-predicted for three separable reasons, the biggest of which was a **test-deck setup
error (missing input decoupling)**, not device physics.

## Bench measurements (Rohde&Schwarz, RT-ZP11 passive probe)

| Config | Vin | SW peak | Overshoot | Rise | Ring | Avalanche? |
|---|---|---|---|---|---|---|
| No coil, no snubber | 60 V | **74 V** (max 74.1, mean 66.6) | ~1.23× | 15.8 ns | ~55–65 MHz, ~4 cyc | **No** |
| Coil + load (Vout 9 V, Iout 2.6 A) | 20 V | **24 V** (max 24.1, mean 22.1) | ~1.2× | 15.3 ns | **~37 MHz** (Coss loop, scales w/ Vin) | **No** |

Key cross-checks from having two operating points:

- **Overshoot ratio is ~1.2× in both** (60 V→74 V and 20 V→24 V). A steep-low-V-Coss
  device would blow up the *20 V* case (ratio grows as Vin drops); it doesn't. → the real
  Coss(V) is **gentle** (StrongIRFET is planar-trench, not superjunction).
- **The ~60 MHz ring is the local Coss commutation ring — present with *and* without the coil.**
  The loaded (coil-connected) ring **scales with bias** exactly as a Coss tank must:
  **37.0 / 53.8 / 58.5 MHz at 20 / 40 / 60 V** (Fab on-scope periods 27 / 18.6 / 17.1 ns),
  matching **f ∝ 1/√Coss(V)** (bench ratios f₂₀/f₆₀ = 0.63, f₄₀/f₆₀ = 0.92 vs predicted 0.64 / 0.89).
  Solving the tank at 60 V (58.5 MHz, ~800 pF) gives **L ≈ 9.3 nH = the same commutation loop as
  no-coil**, and **loaded-60 V (58.5 MHz) ≈ no-coil-60 V (60 MHz)** → the output coil does **not**
  touch the ring. **Correction history (reversed twice, now stable):** an intermediate draft claimed
  the loaded ring was a *voltage-independent ~18–19 MHz coil self-resonance* (a different loop) —
  that was **bad on-scope cursor reads, ~2× too low**, since retracted: `codex-ee-ring`'s pixel reads
  flagged the scaling, and Fab re-measured 20 V = 27 ns = **37 MHz**. The `--coil-cw` winding-cap SRF
  model built for it is reverted. So the original "present with and without the coil" reading stands,
  now backed by the full 1/√Coss scaling. **(My own earlier pixel read of the 20 V shot as ~20 MHz
  was also wrong — the humps are ~27 ns apart, ~37 MHz.)** Peak/no-avalanche is coil-independent
  regardless (loaded peaks reconcile via Coss: ~25 V@20 V / ~54 V@40 V / 74 V@60 V = the no-coil 74 V).
- **No flat clamp plateau** at 80–85 V in either capture → no avalanche.
- Two grounding methods (GND-croc and "no probe clips") agreed at 72–74 V → the peak is
  real, not a probe-attenuation artifact.

Devices: LS `IPP024N08NF2S`, HS `2× IPP055N08NF2S` (StrongIRFET 80 V), Rg = 15 Ω, no gate
discharge diode.

## What the sim first said, and why it was wrong

The first LTspice model (Infineon `_L0` vendor models, no-coil deck) predicted a **105 V
natural / 85 V-clamped** SW overshoot and concluded the OFF LS FET went into **repetitive
avalanche** (the `_L0` body-diode `Dbd` breaks down at BV = 85 V). That conclusion was
**wrong** — falsified by the scope. It failed for three independent reasons, found in order:

### 1. Missing input decoupling (Cin) — the dominant error, a deck-setup bug

The no-coil driver built the deck with **no input capacitor** (`cin_text=None`, `Cbulk=0`).
The trap: "no coil, no load" strips the *output* side, but **Cin is on the input side and
is always physically present** on the board. Without it, the commutation loop can only close
through the 200 nH input feed (`Lfeed`), which fabricates a **spurious ~11 MHz resonance
that replaces the real ~60 MHz Coss ring** and badly inflates the SW peak.

Fix / proof: add a Cin bypass at the leg and the ring jumps into place:

| Cin at leg | SW peak | ring |
|---|---|---|
| **none** (the bug) | 104.9 V | **11 MHz** |
| 100 nF | 62.5 V | **71 MHz** (≈ scope 60 MHz) |

This alone explains the 12-vs-60 MHz "mystery" and most of the peak error. It is **not** a
device-Coss shape error and **not** an extractor bug — the extractor emits a full Cin
network (`--emit-cin-network`); the driver just didn't consume one. The `no_coil` mode in
`dcdc-tools/loss/lib/deck.py` now **warns** when built with no Cin.

### 2. Vendor `_L0` behavioral Miller network — ~+18 V

In the **no-Cin regime** the `_L0` model over-states the overshoot further. A **clean
home-built model** built from dslib scalars + datasheet physics (gm channel +
nonlinear-junction Coss + physical gate-charge caps + body diode, **without** the vendor's
behavioral `Maux/Eaux/Cox` Miller network) gives a natural peak of **86.8 V vs the vendor's
105 V** — so that behavioral stack adds ~+18 V. **But this delta is a no-Cin artifact:** with
proper input decoupling the two models converge (vendor 62.9 V vs homebrew 62.2 V) — once Cin
suppresses the (spurious) large overshoot, the aux network's contribution is negligible. So
the vendor-aux +18 V only mattered on the wrong (no-Cin) deck. The home-built model still
earns its keep independently on transparency and as a vendor-free `--device-model`
candidate. **Rise-time is NOT validated**, though: on the canonical (real-bank) deck the
home-built edge is **~21 ns** and the vendor `_L0` **~7.8 ns** vs the scope's 15.8 ns —
neither reproduces it, and they bracket rather than match. (The two differ because `_L0`
carries the behavioral aux-Miller network and the home-built uses a fixed Cgd; and the
edge detector itself is fragile against deadtime Coss-divider drift. An earlier "16.6 ns"
figure did not reproduce on the accepted deck and is retracted.) The 700 MHz-bandwidth
probe (≈0.5 ns rise limit) captures the real 15.8 ns edge faithfully, so this is a genuine
model gap, not measurement smearing.

### 3. The over-ring is edge-limited, not a "missing ~2.5 Ω Coss loss" (reframed)

An earlier draft said the clean model rings under-damped and attributed the gap to a **~2.5 Ω
device Coss loss** modeled in the Coss branch. The `dcdc-tools` loaded-sw-ring **damping budget**
shows that is **not physical** — the 2.5 Ω is ~10× any real loop resistance:

- Tank characteristic impedance **Z₀ = √(L/C) ≈ 3.4 Ω** (9.2 nH / 800 pF).
- The observed **~4-cycle decay needs only ζ ≈ 0.04 → ~0.27 Ω** effective series R — *not* 2.5 Ω.
- The physical R budget is ~10× below even that: FastHenry copper **17 mΩ** + **frequency-resolved
  MLCC ESR ~6–12 mΩ** (the SRF-floor under-counted 2–12×; now extracted via ngspice AC from the
  vendor cap models in `loss/lib/params.py`) ≈ **~25 mΩ**. Radiation is µΩ; core loss is N/A (coil out).
- **Coss hysteresis is a *superjunction* effect** — small for this 80 V **trench** part (IPP024). So
  the earlier "lossy-Coss / hysteresis" attribution is **retracted**.
- **The modest first overshoot is the FINITE EDGE, not damping.** The 15.8 ns rise ≈ **one ring
  period** at 60 MHz, so the edge only *weakly excites* the tank. The sim over-rings (undamped ~140 V
  with the correct small Cgd) largely because it does **not reproduce the 15.8 ns edge** (rise-time
  gap → `dcdc-tools` issue #1); a too-fast sim edge over-excites the ring.

**So `Rcoss ~2 Ω` is a peak-calibration knob (~10× physical loop R), not a device Coss-loss term** —
don't cite it as physics. This also resolves the earlier **peak-vs-decay tension**: the peak is
*edge*-controlled, not damping-controlled, so forcing the peak with a series R necessarily over-damped
the decay. With the correct edge, **light damping (~0.27 Ω) matches the decay and the peak falls out**.
A small residual remains (0.27 Ω is still ~10× the ~25 mΩ budget), but it is an order of magnitude
smaller mystery than the retracted 2.5 Ω, and largely moot once the edge is right.

## Refinement: the exact peak is a bracket; the real Cin bank closes it

The *missing-Cin frequency artifact* is settled (missing Cin → 11 MHz; add Cin → the real
~60 MHz-regime ring). The *exact* ring frequency / loop-L split is a separate, still-open
question (see "Frequency" below). The *exact peak* is bracketed, not yet pinned:

- **Lower bound ~62 V** — an *ideal* local input cap (`Cbulk vi 0`, zero ESL) strongly
  decouples and collapses the overshoot to ~62 V (just above the 60 V rail). Vendor `_L0`
  and the home-built model agree here (62.9 V vs 62.2 V), so this bound is model-independent.
- **Upper bound ~105–107 V** — the no-Cin / decoupling-defeated case.
- **Real board 74 V** sits between the two.

An attempt to interpolate by giving a *single* Cin an ESL **failed as a deck/topology bug,
not physics**: a sweep of Cin ESL from 50 pH to 1 nH pinned the peak flat at ~107 V —
i.e. right back at the no-Cin value. The tell (ee-review): 50 pH is 0.02 Ω at 60 MHz and
*cannot* defeat decoupling, and a flat result across a 20× ESL range is not an inductance
effect. What actually happened is the single-branch `cin_text`/`Vs_cin` path was **not
decoupling the commutation node at all** — the loop stayed on the 200 nH `Lfeed`, exactly
as in the no-Cin deck (hence 107 V ≈ 105 V). So that experiment is inconclusive about the
peak; only the two clean brackets above are trustworthy.

Closing the bracket to the measured 74 V needs the **validated `out_cinnet` cin_network**
(9-cap bank, per-cap Lb/ESL/ESR — ceramics ∥ bulk) assembled and wired to the commutation
node by the loss tool's cin-consumer path.

**Acceptance test — peak/avalanche PASS.** With the real assembled 9-cap bank wired to the
commutation node, the canonical no-coil sim at Vin = 60 V gives **peak 72.4 V (vendor `_L0`,
−2 %) / 78.0 V (home-built, +5 %) vs the scope's 74 V**, and **no avalanche** (BV = 85 gives
the same peak as BV = 200, so it never reaches the clamp; Dbd stays off). The scope sits
*between* the two models — a **~5.6 V (~7 %) model spread**, so the peak is *primarily* but
**not exclusively** Cin-limited (it is NOT a clean model "convergence"). The full parallel
bank reproduces the ~74 V overshoot that a single cap could not (it was binary 62 / 107 V).
A separate loss-budget
concern — the Cin trunk (`cin_L_shared/R_shared`) and
the commutation loop (`L_loop`, `r_hs/r_ls`) are **largely the same copper** (7.67 nH ≈
8.21 nH; 6.28 mΩ ≈ 6.85 mΩ), so a deck that places both in series double-counts the loop —
must be fixed in the cin-consumer contract (deck carries only the residual switch-side
copper, `L_loop − cin_L_shared`).

**Caveat on the peak — composition-sensitive, and the mechanism is *not* "ceramics".** A
bank-toggle test shows the **full 9-cap bank gives the lowest peak (77 V)**, while
ceramics-only (91 V) and bulk-only (82 V) are both *higher* — so the decoupling is set by
the **number of parallel branches (lowest effective decoupling ESL)**, not by ceramics
"catching the fast edge" (an earlier framing, now **retracted**). The peak therefore carries
a **±14 V composition sensitivity** tied to the per-cap ESL/ESR/DC-bias-derate defaults in
the assembled `cin_network` — the 77 V ≈ 74 V match is not a clean mechanism proof at that
tolerance. One tell to chase in Slice 2: **bulk-only decoupling *better* than ceramics-only
is physically backwards** at 50–60 MHz (a 0402 ceramic ~0.5 nH/0.19 Ω should beat a bulk can
~5 nH/1.9 Ω ~10× at HF); that the sim shows the reverse points at the ceramic-branch ESL
being set too high (or bulk too low) in the per-cap defaults — the same knob that sets the
±14 V band.

## Frequency — reconciled at ~60 MHz (three measured corrections), hardware Δf pending

This section was **"open / under-determined"** after a 3-agent adversarial review broke an
earlier "solved at 8.2 nH" claim (that was a degenerate `L·C` fit — 60 MHz only appeared when
the physically-present TO-220 leads were zeroed; with the model's own leads restored it rang
37–40 MHz). It is now **reconciled** by anchoring both L and C to *measurements* rather than
model outputs. `f = 1/2π√(LC)` has a one-parameter family of solutions, so the fix is to pin
L and C **independently** — which the following two anchors do.

**Anchor 1 — Coss from the datasheet, not the SPICE models.** A quasi-static C–V charge sweep
(`coss_cv.py`: device off, constant I into drain, `Coss(V) = I / (dV/dt)`) on both models:

| IPP024N08NF2S | Css@40 V | **Css@60 V** | Css@74 V | chord 60→74 V (ring C) |
|---|---|---|---|---|
| vendor `_L0` | 1259 pF | **960 pF** | 835 pF | 893 pF |
| home-built | 1001 pF | **907 pF** | 864 pF | 883 pF |
| **datasheet** | 1000 pF | **~800 pF** | — | ~780 pF |

Both models run **~15–20 % high** on Coss at 60 V vs the datasheet. Corrected to the
datasheet, the ring C (chord over the real 60→74 V swing) is **~780–800 pF** — *not* the
~470 pF once speculated, and *not* the models' ~890 pF. (HS Coss is confirmed **shunted**
during the HS-on ring — its channel mΩ shorts its Coss — so the ring C is LS-side only.)

*Curve-fit close (no scale fudge).* Rather than scaling the whole model down, the home-built
Coss/Cgd were **re-fit to the datasheet Diagram-11 curve** (`coss_fit.py` → behavioral charge
capacitors, with `Qoss=105 nC` / `Qgd=19 nC` as integral constraints). C–V re-verify:
**815 pF@60 V (ds 800), 727@74 V (ds 748)** — within ~3 % of the datasheet across 40–80 V. On
that curve-fit model the ring lands at **60 MHz @ 9.2 nH with no `coss_scale`** — so the
reconciliation is not an artifact of the earlier 0.85 scaling. This also surfaced a genuine
model bug: the old build held **`Cgd = Qgd/40 = 475 pF` constant**, but the real Crss collapses
to ~37 pF by 60 V — so the old model carried ~440 pF of **phantom Cgd** at the ring bias, which
was silently **loading/damping the ring** (see the peak note below). Lesson: a charge-averaged
*constant* Cgd secretly damps a ring and can fake a peak match — use a voltage-dependent Cgd.

**Anchor 2 — the source lead is a *measured* package floor, not a tunable stub.** Aikawa et
al., *"Measurement of the Common Source Inductance of Typical Switching Device Packages"*
(IFEEC 2017, DOI 10.1109/IFEEC.2017.7992207) measured TO-220 **common-source inductance**
(pad-to-die) directly: **3.9–5.7 nH**, *decreasing* with current rating because higher-current
dies carry more parallel source bond wires (FDP120N10, 74 A, 3 bonds → **3.9 nH**). ~⅓ of the
CSI is the bond wire, ~⅔ the fixed leadframe+lead. Our LS `IPP024N08NF2S` is a very-high-current
80 V StrongIRFET → the **low end, ~4 nH** (matches this repo's own
[EMI Parasitics Snubbers](<EMI Parasitics Snubbers.md>) note, *"TO-220: 4 nH common source
inductance"*). This is a **package floor** — irreducible by lead trimming or mount. The earlier
"leads over-estimated, real 2.5 mm leads → higher f" hypothesis is **falsified** by this
measurement: the ~4 nH is internal bond-wire + leadframe, not exposed lead.

**Mount note (horizontal bottom-heatsink, our footprint `TO-220-3_Horizontal_*`).** The SPICE
model's `Lg/Ld/Ls` are *internal* package parasitics — mount-independent; the model doesn't
"assume" vertical vs horizontal. What the mount changes lives on the **board side**: horizontal
mount solders the drain tab flat to the SW-node copper pour (drain lead ≈ **1 nH**, part of the
plane — not a ~2.5 nH vertical stub) and runs the bent leads close to the return plane
(image-plane lowers loop L). So horizontal mount *helps* the drain/external term, but cannot
touch the ~4 nH source-CSI floor.

**The reconciliation (transient, datasheet-curve-fit Coss, no scale fudge):**

| ring-loop L composition | Ltot | ring |
|---|---|---|
| **4 nH board copper + ~1 nH drain + ~4 nH source CSI** | **9.2 nH** | **60 MHz** ✓ |
| 4 nH board + ~6.5 nH leads | 10.7 nH | 55 MHz (low edge) |
| 8.2 nH `out_cinnet` + ~5 nH leads | 13.2 nH | 50 MHz |
| 8.2 nH `out_cinnet` + ~6.5 nH leads | 14.7 nH | 48 MHz |

*(Both the scaled and the curve-fit model give this same frequency column; the peak is a
separate damping story — see below.)*

With the datasheet ~800 pF, the scope's 55–65 MHz demands a **total ring-loop L ≈ 7.5–10.5 nH**,
which decomposes physically as **~4 nH board copper + ~1 nH drain tab + ~4 nH source CSI ≈
9.2 nH → 60 MHz**, peak unchanged. The frequency gap was **three compounding errors, none of
them "lead length"**: (1) **board-copper L too high** — the 8.2 nH `out_cinnet` `L_loop` is
~2× the **4.2 nH golden** PCB-copper figure from the bespoke DPT solver, and is flagged from a
*non-authoritative* board revision; it is the single biggest contributor to the 45 MHz
under-prediction; (2) **Coss ~15–20 % high** in both models vs the datasheet 800 pF; (3) the
earlier "leads zeroed → 60 MHz" was a degenerate fit that happened to compensate (1).

**Still to confirm (turns "reconciled" into "measured"):**
1. **Hardware external-cap Δf test** — drop a known C0G (~470 pF) on SW and re-scope; the
   frequency shift pins L and C non-circularly on the real board. This is the clean check that
   the ~9.2 nH / ~800 pF split above is the real one and not another compensating pair.
2. **Board-copper re-extraction** on the *authoritative* `Fugu2.kicad_pcb` — expect the ring
   loop copper near the ~4 nH golden, not 8.2 nH. If the re-extraction confirms ~4 nH, the
   reconciliation closes without needing the Δf test; if it lands near 8.2 nH, the Δf test
   arbitrates.

**Peak is an EDGE story, not a ring-C or a damping story (phantom-Cgd + reframe).** With the
*correct* voltage-dependent Cgd (small at the 60–74 V ring bias), the curve-fit model rings
*undamped* to ~140 V at 9.2 nH — the old ~78 V was landing near the scope's 74 V only because
the phantom 475 pF constant Cgd was supplying ~2.5 Ω-equivalent damping. A `Rcoss` series R in
the Coss branch pulls it back (Rcoss 0 → 140 V, 1.5 Ω → 92 V, **2.5 Ω → 78 V**, 4 Ω → 70 V, all
~56–60 MHz) — **but ~2.5 Ω is a calibration knob, ~10× any physical loop R, not a real loss term**
(see §3). The physical reason the *real* board's first overshoot is modest is the **finite 15.8 ns
edge (≈ one ring period)**, which only weakly excites the tank; the sim over-rings mostly because
it doesn't reproduce that edge (rise-time gap, `dcdc-tools` issue #1), not because it's missing
2.5 Ω. This **dissolves** the earlier peak-vs-decay tension: the peak is *edge*-controlled and the
~4-cycle decay needs only ~0.27 Ω, so there's no single-R contradiction once the edge is right —
Rcoss was standing in for the missing edge. The peak also carries the Cin-bank decoupling
composition sensitivity (below), independent of the ring L/C.

**What survives regardless (the safety verdict).** The benign / no-avalanche conclusion is
**independent of the ring-L/C identity** — the peak lives on the lower-Q Cin-bank decoupling
loop, and no lead/Coss/damping treatment in this study pushes the real board into avalanche.
The frequency reconciliation does **not** reopen (nor was it needed for) that conclusion.

## What was falsified along the way (don't re-litigate)

- **Qrr / reverse recovery** — TT = 0 changed the peak by 0.0 V (no freewheel current to
  forward-bias the body diodes in the no-coil case).
- **L_loop magnitude** — peak flat across L_loop 4→20 nH. This was itself a missing-Cin
  artifact: with `Lfeed` = 200 nH dominating, the total loop was ~204–220 nH, so sweeping
  board L 4→20 nH was only ±4% → of course flat. The earlier reading of this as an
  "L-independent nonlinear-Coss energy limit / parametric pumping / no-safe-Vin" is
  **retracted** along with the avalanche. On the corrected Cin-present deck, L_loop is
  load-bearing again for the ring frequency — now **reconciled** at a total ring loop of
  ~9.2 nH (~4 nH board copper + ~1 nH drain + ~4 nH measured source CSI) against a datasheet
  ~800 pF Coss → ~60 MHz (see "Frequency" above); the 8.2 nH `out_cinnet` figure is the
  outlier to re-check, and the hardware Δf test is the final confirmation.
- **Coss magnitude** — scaling it *down* raised the peak; model Coss ≈ datasheet anyway.
- **Skin effect as the damper** — real skin-corrected copper is 17 mΩ (+ freq-resolved MLCC
  ESR ~6–12 mΩ ≈ 25 mΩ total), nowhere near the ~2.5 Ω once assumed — and the ~4-cycle decay
  needs only ~0.27 Ω anyway; the over-ring is edge-limited, not under-damped (see §3).
- **Timestep** — the 105 V and 11 MHz were converged (12.8 ns → 0.1 ns), i.e. a *real*
  feature of the (wrong) deck, which is exactly why convergence ≠ correctness.

## Lessons

- **Robustness ≠ accuracy.** The wrong result was timestep-converged and insensitive to
  L_loop, Coss magnitude, gate-L, and Qrr — a fully self-consistent model of the wrong
  circuit. Only the hardware settled it. Validate the dominant physics against an
  independent measurement *before* the sweep matrix.
- **A no-coil / no-load test still needs the input Cin.** It's the easiest decoupling to
  forget and it fabricates a low-frequency resonance that masquerades as the real ring.
- **Distributed HF ring damping is a device/Coss loss, not loop copper** — put it in the
  right circuit element or it double-counts.
- **Get the scope shot early**, and take two grounding methods / two operating points — the
  20 V loaded point is what proved the Coss(V) is gentle.
- **A frequency match can be a degenerate L·C fit.** "60 MHz reproduced at 8.2 nH" looked
  like a pin but only held because physically-present device leads were zeroed; restoring
  them gave 37–40 MHz. `f = 1/2π√(LC)` has a one-parameter family of (L,C) solutions — you
  cannot claim a loop-L from a frequency match alone. Separate L and C **non-circularly**
  (external-cap Δf on the bench, or a lead-inclusive geometric extraction) before pinning.
- **A large-swing resonant ring uses the charge-effective Coss over the *actual* swing**, not
  the small-signal value at one bias — and for a high-bias ring, not the 0→V charge-effective
  either (that over-weights the low-V high-C region). Use the chord over the real swing.
- **Check the probe bandwidth before trusting (or doubting) a fast feature.** The 700 MHz
  probe (~0.5 ns rise) confirmed the 15.8 ns edge and 60 MHz ring are real, not band-limited.

## Verdict

At 60 V no-coil the real board rings to ~74 V with a well-damped **~60 MHz local-Coss ring**;
in normal loaded operation it rings to ~24 V (20 V) with the **same Coss commutation ring, scaling
with bias** (~37 / 54 / 58.5 MHz at 20 / 40 / 60 V — the coil doesn't touch it). It **does not
avalanche** in either case. The sim's avalanche prediction was an
artifact of (1) a missing input capacitor, (2) the vendor model's behavioral Miller network,
and (3) a too-fast simulated edge over-exciting the ring (the ~2.5 Ω "Coss-loss damping" was a
peak-calibration knob, not physics — see §3) — none of them a real board hazard.

---

*Tooling: `dcdc-tools/loss` `no_coil` deck mode (`DeckOpts.no_coil`, with the missing-Cin
guard), `plot_sw_ids.py`, and the home-built dslib model. Validated Fugu2 parasitics:
`out_cinnet/parasitics.json` (L_loop 8.21 nH, r_hs 2.43 / r_ls 4.42 mΩ, full cin_branches).
Copper R(f) skin-corrected ~17 mΩ (nwinc=3). See also
[Half Bridge Simulation (SPICE)](<Half Brdige Simulation (SPICE).md>),
[EMI Parasitics Snubbers](<EMI Parasitics Snubbers.md>), [SW Phases](<SW Phases.md>).*

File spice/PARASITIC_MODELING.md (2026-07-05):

# Fugu2 commutation-loop parasitic modeling — process & findings

Goal: replace the hand-guessed parasitics in `buck_parasitcs.asc` with values
extracted from the real PCB, using vendor SPICE models for the capacitors and
MOSFETs, and cross-check the predicted switch-node ringing.

This doc records **how the model was built**, **what worked / didn't**, and — the
part worth reading before you fight these tools yourself — **what each
manufacturer's SPICE models are actually like to obtain and simulate**.

---

## 0. TL;DR

| Quantity | Value | Confidence |
|---|---|---|
| Commutation-loop PCB copper L (nearest ceramic) | ~4 nH (band 4–6 nH) | high |
| FET pin/lead inductance (TO-220, both switches) | ~9 nH | high (datasheet) |
| **Total hot-loop L** | **~13 nH (pins ~70%)** | high |
| Switch-node ring frequency | **~68 MHz** | high (3 models + analytic agree) |
| Tank impedance Z₀ = √(L/Coss) | 5.6 Ω (13 nH, 420 pF) | high |
| Effective Coss at the swing | ~420 pF (inferred from ring; matches Co(er)≈450 pF) | medium |
| **Un-snubbed overshoot @32 A/80 V** (mfr vendor models) | **5.68 V (peak 85.7 V)** — conservative; ~4.0 V with datasheet-anchored Qrr | high (verified, Miller-limited) |
| Body-diode Qrr loss @39 kHz | ~0.5 W (datasheet-anchored; raw model 2.8 W is ~6–9× high) | med — §5c |
| — with 120 V Infineon `_L0` LS variant | 19 V (peak 99 V) → 21 V margin | high (converged) |

**RESOLVED (see §5): the pessimistic 103 V was wrong.** With proper vendor MOSFET
models (Toshiba `_G0`, or Infineon `_L0`+external leads) the DPT bench converges
and the overshoot is **Miller-limited and modest (~4–19 V, FET-dependent) and
sub-linear in load current** — it does *not* grow with current. The **LS FET sees
the SW overshoot (peak ~84–99 V), so a >100 V LS is the right call** — the user's
**IPP022N12NM6 (120 V) LS gives ~21 V margin**; an 80 V LS would be exceeded. The
snubber (board C8) is for **EMI + margin, not survival**.

---

## 1. Layout reconnaissance (the first surprise)

The README says "TO-220 switches," but the actual v2.3 layout (`pcbnew` on
`Fugu2.kicad_pcb`) uses **SMD Infineon PG-TDSON-8** footprints on B.Cu:
- HS = **Q1 ‖ Q3** (Solar+ → SW), LS = **Q2** (SW → BuckGND), all bottom-layer.
- LS Schottkys **D9 (TO-220) / D16 (TO-277) are DNP** (unpopulated) — freewheel
  is the Q2 body diode.
- HF ceramics (C16/C17/C18/C21/C22/C9/C27) sit right on the B.Cu pours next to
  the switches.

The BOM lists TO-220 alternates (`IPP055N08NF2S` HS, `FDPF2D3N10C` LS) as DNP
options. Per the user the intended build uses the **TO-220 parts**, so the FET
stress work uses those — which is why the FET *leads* end up dominating the loop.

**Finding:** never trust the README/BOM package over the actual footprints; and a
board can carry both SMD and THT options with the "populated" set differing from
the BOM defaults.

---

## 2. Commutation-loop inductance: KiCad → FastHenry

### Tooling
- **FastHenry 3.0.1** (FastFieldSolvers fork), built from source at
  `~/dev/vendor/FastHenry2`. Legacy K&R C — needs
  `CFLAGS='-O -DFOUR -m64 -std=gnu89 -fcommon -Wno-implicit-function-declaration
  -Wno-implicit-int -Wno-return-type -Wno-deprecated-non-prototype'`.
- **KiCad 9 bundled python** (has `pcbnew`) for geometry; **system python3** for
  the runner. Files: `extract/kicad_to_fasthenry.py`, `extract/run.py`,
  `extract/debug_plot.py`, `extract/results.md`.

### Method
Mesh the `Solar+`/`SW`/`BuckGND` pours (both layers) into a **filament grid
clipped to the real filled polygon**; rasterize tracks (Manhattan-routed) and
pads onto the same grid; stitch layers with vias; short each switch drain→source
with a thin die-plane bridge; excite one port across a chosen ceramic.
`L = Im(Z)/ω` on the 10–100 MHz plateau.

### Findings / gotchas
- **Coincident cross-net nodes → NaN.** Two nets landing on the same grid cell
  create identical-coordinate filaments → singular mutual inductance. Fixed with
  a global per-cell **occupancy** map (one net per cell).
- **FastHenry rejects trailing comments** on element lines.
- **Per-cap loop L ranks which ceramic carries the hot loop** (port swept across
  each): C18 4.20, C17 4.33, C9 4.59, C16 4.80, C21 5.36, C22 6.70, C27 16.3 nH.
  → The two 0603s at the switch node dominate; placement beats capacitance.
- **You cannot scalar-parallel the per-cap Ls** — they share copper/mutuals.
  Correct decomposition: shared switch-loop copper (~4.0 nH) + per-cap branch
  excess. Verified: the LTspice Cin subckt gives 4.0 + 0.19 nH bypass ≈ 4.2 nH,
  matching FastHenry.
- **Convergence is non-monotonic in mesh pitch** (2.0/1.0/0.7 mm → 5.8/4.8/5.2
  nH, ±9%). The gridded-filament plane is an approximation; report a band, not a
  point. G-plane refinement is future work.
- **Connectivity prune** (keep only the mesh reachable from the port) turns
  silent NaN into a clean error and drops floating islands.
- **Q2-only (D9/D16 DNP) disconnects the port** — the SW pour is fragmented and
  the HS-side / Q2-side SW were joined only through the diode copper. This is a
  *latent layout observation*: if D9/D16 are truly DNP, check the SW node isn't
  split (KiCad DRC with them unpopulated). Deferred — leads dominate, so the 4 vs
  ~6 nH copper difference is <10% of the 13 nH total.

### Speed
FastHenry has **no OpenMP** (verified — zero `#pragma omp` in the source; the
binary is single-threaded). Speed came from: solving only the ~10–100 MHz
plateau (the preconditioner is rebuilt *per frequency*), `-p diag` preconditioner,
and running the independent pitch solves concurrently. `-s ludecomp` (dense)
*times out* — iterative+multipole is essential. Full 3-pitch sweep: ~8 s.

---

## 3. Manufacturer SPICE models — the real notes

This is the part that cost the most time. Summary of how each vendor ships
models and how they behave.

### Capacitors

**Taiyo Yuden (TY-COMPAS)** — *the good one.*
- Per-part download works via a **session cookie**: GET the detail page
  (`ds.yuden.co.jp/TYCOMPAS/ut/detail?pn=<PN>&u=M`) to set a cookie, then
  `…/ut/download?pn=<PN>&fileType=<T>` with that cookie + Referer.
- File types: `cir_file` (standard **0-bias** RLC-ladder, unencrypted, portable),
  `LTspice_file` (a **zip** with the **temperature/DC-bias** model `_LT.cir` +
  a `.asy` symbol). The bias model is **encrypted** (`* LTspice Encrypted File`)
  → LTspice-only, can't port to ngspice.
- The BOM part numbers are **renamed** under the new scheme: `HMK212BC7105KGHTE`
  → `MMASH21GBC7105KTCA01`, `HMK107C7224KAHTE` → `MCASH168SC7224KTCA01`. Resolve
  via the old-PN detail page.
- Params read straight from the `.cir`: 0603 220 nF → ESL 0.47 nH, ESR 12.2 mΩ;
  0805 1 µF → ESL 0.35 nH, ESR 5.3 mΩ. Clean, well-behaved models.

**Murata (SimSurfing)** — *no clean per-part download.*
- The product page has **no direct SPICE link** (it's inside the SimSurfing JS
  app). Per-part URLs return the SPA shell.
- Workaround: download the **series netlist ZIP** (e.g. `grm-n-v76.ashx`,
  ~9 MB) from the MLCC SPICE page and extract the `.mod` (found
  `GRM32EC72A106KE05.mod`). This is a **0-bias** RLC-ladder model; the
  DC-bias-dependent model lives only in SimSurfing.
- Fine for bulk caps; for the 10 µF 100 V X7S at 60–80 V the 0-bias model
  overstates C (X7S derates hard), but those caps are the *least* important for
  the fast loop (highest loop L), so acceptable — flagged in the manifest.

Models + `MANIFEST.md` live in `extract/capmodels/vendor/`. The Cin bypass
network is assembled in `extract/capmodels/cin_hotloop.lib` (each ceramic =
vendor model in series with its FastHenry copper-branch L) and wired into
`buck_parasitcs_extracted.asc`. **Verified in LTspice** (AC impedance test
`tst_cin.cir`): all 6 vendor models load, Ceff = 21.2 µF (nominal 22.4), HF
bypass ESL parallels to 0.19 nH → SW sees 4.0 + 0.19 ≈ 4.2 nH.

### MOSFETs — *where the trouble was.*

**Infineon** — *best features, worst numerics — but there's a workaround (`_L0`).*
- Sources: the community **metacollin/LTspiceInfineonNMOSLibrary**, AND the
  **official** pack (`infineon-optimos-…-simulationmodels`, per-generation
  `OptiMOS*/StrongIRFET*_LTSpice.lib`). The official and community models are the
  **same** — same subckts, same lead params.
- Each part ships **three variants**: `_L1` (die + internal lead inductors,
  `PARAMS: Ls Ld Lg`), the full 5-terminal thermal model, and **`_L0`
  (die-only, no leads)**.
- **`_L1` is numerically fragile in transient.** An internal behavioral-cap node
  (`e:*:_eds*#branch`) collapses the timestep (→ 2.5e-19) whenever the FET's
  drain sees dV/dt — it fails even during a gentle `Vin` ramp with the FET *off*,
  and it fails **as the LS too** (blows up to 100+ kV at HS turn-on). The 15 A
  bench only survived because the drain was **static** (`uic`). No `uic`/
  soft-start/damping/tolerance trick fixes it.
- **THE FIX: `_L0` (die-only) CONVERGES.** The fragility is specifically the
  `_L1` **internal lead-inductance network**, not the die. So use `_L0` + your
  own external `Ld/Ls/Lg` inductors — official Infineon models are then usable
  and give physical, converged results (Toshiba HS + `IPP022N12NM6_L0` LS → clean
  32 A run, 19 V overshoot).
- **Lesson:** detailed vendor MOSFET models with hidden internal reactive nodes
  can be unusable in fast transients — but the `_L0`/die-only variant (leads
  added externally) sidesteps it. Prefer models built on **standard primitives**
  (see Toshiba) or the `_L0` variant.

**Toshiba** — *the robust one; what the original bench used.*
- Official LTspice/PSpice libs at `toshiba.semicon-storage.com`. `TK6R8A08QM_G0`
  (unencrypted PSpice `.lib`) is built on a **plain `M` primitive with zero
  behavioral E/G/B sources** → numerically bulletproof. The original
  `buck_parasitcs.asc` already used this family (`TK*_G0_00_PSpice_rev1.lib`).
- In the DPT bench it converges at any I/V and gives Miller-limited overshoot
  (9.8 V @15 A, 4 V @32 A) — no leads built in, so add external `Ld/Ls/Lg`.
- Node order `.SUBCKT … 1 2 3` = **1=Drain 2=Gate 3=Source**.

**TI** — `CSD19501KCS.lib` (from `slpm107b.zip`) obtained; PSpice-format, usable
in LTspice. Not needed once Toshiba worked, but on hand as a cross-check.

**onsemi** — *effectively un-scriptable.*
- The LS BOM part `FDPF2D3N10C` model is behind a **WAF** (403 to curl *and*
  WebFetch) and a **SPA/search-API** (guessable URLs return the app shell; even a
  same-origin in-page `fetch` returned HTML). Not worth the effort for a
  secondary part — substituted an Infineon LS from the same lib (README's LS
  picks are Infineon anyway) and flagged it.

**Model-independence finding:** ring *frequency* is robust across every model +
analytic (~68 MHz for IPP055-class Coss). Overshoot *amplitude* is highly
model-sensitive — the behavioral switch and VDMOS over-predict it (no gate-charge
fidelity) and the Infineon `_L1` won't converge, but a **numerically clean vendor
model (Toshiba `_G0`, or Infineon `_L0`+leads) resolves it** to a modest,
Miller-limited value (§5b). Model *numerics*, not physics, drove the confusion.

---

## 4. FET pins + the ringing cross-check

Bench `fugu_ring.cir` (single-HS, Infineon `_L1` with built-in leads, vendor Cin,
extracted 4 nH copper split L5/L4, `uic` at 70 V static drain):
- Loop L = 4 nH copper + 9 nH FET leads = **13 nH — pins ~70%.**
- HS turn-on: SW overshoot ~11 V (peak 81 V), **ring 68 MHz**, decays in ~4
  cycles. Analytic `1/(2π√(13 nH·420 pF)) = 68 MHz` matches → cross-check passes.
- Coss handling: standalone Coss(V) extraction from the model **fails** (the same
  internal-node fragility). Effective Coss **inferred** from the validated ring =
  420 pF at the 70–80 V swing, consistent with Infineon Co(er) ≈ 450 pF.
- The `_L1` `Ls` (source lead) provides common-source degenerative feedback that
  slows di/dt — the 4 nH PCB copper is placed **outside** the package `Ls`
  (Cin → pad), so no double-count.

---
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

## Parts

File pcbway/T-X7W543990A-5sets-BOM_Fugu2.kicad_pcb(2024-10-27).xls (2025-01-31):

PCBWay Bom Quotation, Product No.:T-X7W543990A
Item # | *Designator | *Qty | *Mfg Part # | Description / Value | Vendor Part # | *Package/Footprint | Mounting Type | Your Instructions / Notes | *Unit Price(5 sets) | *Total | *Delivery Time | *Actual Purchase Mfg Part # | *PCBWay Note | Customer Reply | PCBWay Update
1 | C1 | 1 | DNP | 100nF, 25V『 』test first, then place『 』GndLoop |  | C_0805_2012Metric | smt | Yes DNP |  |  |  |  | [DNP不要贴];
2 | C10, C11, C12 | 3 | DNP | 470uF『 』Cin |  | CP_Radial_D16.0mm_P7.50mm | tht |  |  |  |  |  | [DNP不要贴];
3 | C13 | 1 | 47uF, 100V | 47uF, 100V『 』PwrSupply | ERS1KM470F12OT | CP_Radial_D8.0mm_P3.50mm | tht |  | $0.074 | $0.370 |  | ERS1KM470F12OT
4 | C14 | 1 | 100nF, 100V | 100nF, 100V『 』HeatSinkCouple |  | C_0805_2012Metric | smt |  | $0.050 | $0.250 |  | CL21B104KCFNNNE
5 | C15, C2, C24, C4 | 4 | 100nF, 25V | 100nF, 25V『 』[C15]VS_Filt; [C2,C24,C4]bypass |  | C_0805_2012Metric | smt |  | $0.009 | $0.180 |  | CC0805KRX7R8BB104
6 | C16, C27, C9 | 3 | HMK212BC7105KGHTE | 1uF, 100V, X7S『 』DC-bias stable『 』Cin | HMK212BC7105KGHTE『 』C2012X7S2A105K125AB | C_0805_2012Metric | smt |  | $0.119 | $1.785
7 | C17, C18 | 2 | HMK107C7224KAHTE | 220nF, 100V, X7S『 』Cin | HMK107C7224KAHTE『 』HMK107C7224KAHTE | C_0603_1608Metric | smt |  | $0.130 | $1.300
8 | C19 | 1 | 10uF, 16V | 10uF, 16V『 』bootstrap |  | C_0805_2012Metric | smt |  | $0.050 | $0.250 |  | CL21A106KOQNNNE
9 | C20, C23 | 2 | 10nF, 50V | 10nF, 50V『 』[C20]Bflow drive; [C23]VS_Filt |  | C_0805_2012Metric | smt |  | $0.016 | $0.160 |  | CC0805KRX7R9BB103
10 | C21, C22 | 2 | GRM32EC72A106KE05L | 10uF, 100V, X7S『 』Cin | GRM32EC72A106KE05L『 』GRM32EC72A106KE05L | C_2220_5650Metric | smt |  | $0.578 | $5.780 |  |  | The correct package for the listed Part Number [GRM32EC72A106KE05L] is indeed [1210], not [2220].Please confirm. | please use C5750X7S2A156M250KB or 22201C106MAT2A, whichever is available (2220 package)
11 | C25, C3 | 2 | 470nF, 25V | 470nF, 25V『 』[C25]CS_Filt; [C3]ENdelay |  | C_0805_2012Metric | smt |  | $0.050 | $0.500 |  | CL21B474KAFNNNE
12 | C6, C7 | 2 | 100nF, X7R, 25V | 100nF, X7R, 25V『 』low ESR『 』GateDriveBypass |  | C_0805_2012Metric | smt |  | $0.017 | $0.170 |  | CC0805KRX7R8BB104
13 | C8 | 1 | C0805C222K2GEC7800 | 2.2nF, 200V, X7S『 』maybe C0G? C0805C222K2GEC7800『 』Snubber | C0805C222K2GEC7800 | C_1206_3216Metric | smt |  | $0.462 | $2.310 |  |  | The correct package for the listed Part Number [C0805C222K2GEC7800] is indeed [0805], not [1206].Please confirm. | please put 0805 part
14 | D1 | 1 | MSS1P4 | MSS1P4『 』GateDischarge『 』1=K 2=A |  | D_SMF | smt |  | $0.211 | $1.055
15 | D10, D11, D12, D7 | 4 | SS310 | SS310『 』[D10]boostrap; [D11]PwrSupplyPV; [D12]PwrSupplyBAT; [D7]PwrSupplyUSB『 』1=K 2=A |  | D_SOD-123 | smt |  | $0.023 | $0.460 |  |  | Brand: TDD Packaging: SMA, please confirm | Use Slkor DSS310, Packaging: SOD-123FL (LCSC C41369492)
16 | D13 | 1 | SMAJ85A | SMAJ85A『 』PwrSupply |  | D_SMA | smt |  | $0.124 | $0.620
17 | D16 | 1 | ST15100S | ST15100S『 』ULTRA LOW VF SCHOTTKY RECTIFIERS, 100V, 15A |  | TO-277B_ThermalVias | smt |  | $1.030 | $5.150 | 7-10 Workdays
18 | D2 | 1 | WS2812B | WS2812B『 』StatusLED |  | LED_WS2812B_PLCC4_5.0x5.0mm_P3.2mm | smt |  |  |  |  |  | It has multiple suffixes, please provide the complete model number | XL-5050RGBC-WS2812B
19 | D3, D4, D5, D6 | 4 | LESD5D5.0CT1G | LESD5D5.0CT1G『 』USB |  | D_SOD-523 | smt |  | $0.013 | $0.260
20 | D8 | 1 | 1N4148 | 1N4148『 』Bflow drive『 』1=K 2=A |  | D_SOD-123 | smt |  | $0.036 | $0.180 |  |  | onsemi
21 | D9 | 1 |  | ST40100C『 』LS |  | TO-220-3_Horizontal_BottomHeatsink_NoHole | tht |  | $2.493 | $12.465 | 7-10 Workdays |  |  | please DNP
22 | DZ1 | 1 | SM2T3V3A | SM2T3V3A『 』Powermite Unidirectional TVS diode, 3.3V, 200W, Alternate KiCAD Library『 』PwrSupply |  | D_Powermite_KA | smt |  | $0.696 | $3.480
23 | DZ2 | 1 | BZX84-C15,215 | BZX84-C15『 』Bflow drive |  | SOT-23 | smt |  | $0.091 | $0.455
24 | F1 | 1 | DNP | Fuse |  | Fuse_Blade_ATO_directSolder | tht |  |  |  |  |  | [DNP不要贴];
25 | F2 | 1 | 375mA fast 0603 | 375mA fast, 50A |  | Fuse_0603_1608Metric | smt |  | $0.110 | $0.550 |  | 0467.375NRHF | we will supply is 0467.375NRHF,OK? please confirm | OK
26 | H1 | 1 | DNP | MountingHole |  | MountingHole_3.2mm_M3_DIN965_Pad_TopOnly | tht | Yes DNP |  |  |  |  | [DNP不要贴];
27 | H2 | 1 | DNP | MountingHole |  | MountingHole_3.2mm_M3_DIN965 | tht | Yes DNP |  |  |  |  | [DNP不要贴];
28 | H3 | 1 | DNP | MountingHole |  | MountingHole_3.2mm_M3_DIN965 | tht | Yes DNP |  |  |  |  | [DNP不要贴];
29 | H4 | 1 | DNP | MountingHole |  | MountingHole_3.2mm_M3_DIN965 | tht | Yes DNP |  |  |  |  | [DNP不要贴];
30 | H5 | 1 | DNP | MountingHole |  | MountingHole_3.2mm_M3_DIN965 | tht | Yes DNP |  |  |  |  | [DNP不要贴];
31 | J1 | 1 | Male Pin Header | Conn_02x03_ESP_PROG『 』ProgConn |  | PinHeader_2x03_P2.54mm_Vertical | tht |  | $0.120 | $0.600 |  | B-2100S06P-B110 | we will supply is B-2100S06P-B110,OK? please confirm | OK
32 | J10 | 1 | DNP | SOLAR『 』PVinp |  | TerminalBlock_MetzConnect_Type703_RT10N02HGLU_1x02_P9.52mm_Horizontal | tht |  |  |  |  |  | [DNP不要贴];
33 | J3 | 1 | DNP | Conn_L_SW『 』MainInductor |  | SolderWire-1x01_D3mm | tht | Yes DNP |  |  |  |  | [DNP不要贴];
34 | J4 | 1 | DNP | Conn_02x07_Odd_Even『 』Generic connector, double row, 02x07, odd/even pin numbering scheme (row 1 odd numbers, row 2 even numbers), script generated (kicad-library-utils/schlib/autogen/connector/)『 』uCconn |  | PinHeader_2x07_P2.54mm_Vertical_SMD_Pin1Left | smt |  |  |  |  |  | [DNP不要贴];
35 | J5 | 1 | Male Pin Header | I2C Conn『 』i2cConn |  | PinHeader_1x04_P2.54mm_Vertical | tht |  | $0.104 | $0.520 |  | B-2100S04P-A110 | we will supply is B-2100S04P-A110,OK? please confirm | OK
36 | J6 | 1 | DNP | Conn_L_out |  | SolderWire-1x01_D3mm | tht | Yes DNP |  |  |  |  | [DNP不要贴];
37 | J7 | 1 | DNP | 3.3V PSU『 』3.3V supply |  | PinHeader_1x03_P2.54mm_Vertical | tht | Yes DNP |  |  |  |  | [DNP不要贴];
38 | J8 | 1 | DNP | 12V PSU『 』10V supply |  | PinHeader_1x03_P2.54mm_Vertical | tht | Yes DNP |  |  |  |  | [DNP不要贴];
39 | J9 | 1 | DNP | BAT『 』BATinp |  | TerminalBlock_MetzConnect_Type703_RT10N02HGLU_1x02_P9.52mm_Horizontal | tht |  |  |  |  |  | [DNP不要贴];
40 | PWRGND1 | 1 | DNP | ~ |  | TestPoint_THTPad_1.5x1.5mm_Drill0.7mm | tht | Yes DNP |  |  |  |  | [DNP不要贴];
41 | Q1, Q3 | 2 | DNP | TK6R8A08QM『 』HS |  | TO-220-3_Horizontal_BottomHeatsink_SmallHole | tht |  |  |  |  |  | [DNP不要贴];
42 | Q2 | 1 | DNP | CSD19505『 』LS |  | TO-220-3_Horizontal_BottomHeatsink_NoHole | tht |  |  |  |  |  | [DNP不要贴];
43 | Q4 | 1 | AO3400A | AO3400A『 』N-CH 30V『 』Bflow drive |  | SOT-23 | smt |  | $0.191 | $0.955 |  |  | Brand: AOS Package: SOT-23-3L, please confirm | the MPN Value has changed, please use Diodes Incorporated BSS123-7-F (LCSC C85107) or similar
44 | Q5, Q6 | 2 | TPH1R306PL,L1Q | TPH1R306PL,L1Q『 』Bflow |  | Infineon_PG-TDSON-8_FL | tht |  | $2.612 | $26.120
45 | R1 | 1 | 20k | 20k『 』tDT_ns(RDT_kΩ) ≈ 8.6 * RDT_kΩ + 13『 』DeadTime |  | R_0805_2012Metric | smt |  | $0.011 | $0.055 |  | RC0805FR-0720KL
46 | R10, R25, R27 | 3 | 22 | 22『 』[R10]GateCharge; [R25,R27]CS_FILT |  | R_0805_2012Metric | smt |  | $0.004 | $0.060 |  | RC0805FR-0722RL
47 | R11 | 1 | 7.5 | 7.5『 』Snubber |  | R_1206_3216Metric | smt |  | $0.122 | $0.610 |  | RC1206FR-077R5L
48 | R13, R14, R15, R16, R2, R23, R3 | 7 | 10k | 10k |  | R_0805_2012Metric | smt |  | $0.025 | $0.875 |  | RC0805FR-0710KL
49 | R17, R24 | 2 | 1M | 1M『 』[R17]HeatSinkCouple; [R24]Bflow drive |  | R_0805_2012Metric | smt |  | $0.006 | $0.060 |  | RC0805FR-071ML
50 | R18, R21 | 2 | 200k | 200k『 』[R18]ADC; [R21]Bflow drive |  | R_0805_2012Metric | smt |  | $0.009 | $0.090 |  | RC0805FR-07200KL
51 | R19 | 1 | 20 | 20 |  | R_0805_2012Metric | smt |  | $0.011 | $0.055 |  | RC0805FR-0720RL
52 | R20, R8, R9 | 3 | 7.5k | 7.5k |  | R_0805_2012Metric | smt |  | $0.004 | $0.060 |  | RC0805FR-077K5L
53 | R22 | 1 | 47k | 47k『 』Bflow drive |  | R_0805_2012Metric | smt |  | $0.042 | $0.210 |  | RC0805FR-0747KL
54 | R26 | 1 | LR2512D-3W-0.5mR-1% | 0.0005『 』CSBurden | C500733『 』PA2512FKF7W0U5E | R_2512_6332Metric_Pad1.80x3.40mm_HandSolder | smt |  | $1.682 | $8.410 |  | PA2512FKF7W0U5E
55 | R28, R29 | 2 | 47k 1% | 47k, 1% |  | R_0805_2012Metric | smt |  | $0.029 | $0.290 |  | RC0805FR-0747KL
56 | R4, R6 | 2 | DNP | 10『 』GateCharge |  | R_0805_2012Metric | smt |  |  |  |  |  | [DNP不要贴];
57 | R5, R7 | 2 | 7.5 | 7.5『 』GateDischarge |  | R_0805_2012Metric | smt |  | $0.019 | $0.190 |  | RC0805FR-077R5L
58 | TH1 | 1 | NCP18XH103F03RB | NCP18XH103F03RB『 』NTC | NCP18XH103F03RB『 』NCP18XH103F03RB | R_0201_0603Metric | smt |  | $0.251 | $1.255 |  |  | The correct package for the listed Part Number [NCP18XH103F03RB] is indeed [0603（1608 metric）], not [R_0201_0603Metric].Please confirm. | MPN change, please use NCP03XH103F05RL
59 | TPHO1 | 1 | DNP | ~ |  | TestPoint_Pad_D1.5mm | tht | Yes DNP |  |  |  |  | [DNP不要贴];
60 | TPLO1 | 1 | DNP | TP_PWM_LO |  | TestPoint_Pad_D1.5mm | tht | Yes DNP |  |  |  |  | [DNP不要贴];
61 | U1 | 1 | UCC21330BQDRQ1 | UCC21330BQDRQ1『 』Isolated Dual-Channel Gate Driver, Output Current 4.0/6.0A, 5.7kV Isolation, 8V UVLO, SOIC-16 | UCC21330BQDRQ1 | SOIC-16_3.9x9.9mm_P1.27mm | smt |  | $2.238 | $11.190 | 7-10 Workdays
62 | U2 | 1 | DNP | ESP32-S3-WROOM-1 | ESP32-S3-WROOM-1U-N4R2 | ESP32-S3-WROOM-1-noPIN15 | smt |  |  |  |  |  | The quoted part number is [DNP], not [ESP32-S3] as specified in description[DNP不要贴];
63 | U3 | 1 | INA226AIDGSR | INA226 |  | VSSOP-10_3x3mm_P0.5mm | smt |  | $0.954 | $4.770
64 | USB1 | 1 | Male Pin Header | USBConn_01x04_Pin |  | PinHeader_1x04_P2.54mm_Vertical | tht |  | $0.104 | $0.520 |  | B-2100S04P-A110 | we will supply is B-2100S04P-A110,OK? please confirm | OK
65 | bfg1 | 1 | DNP | ~ |  | TestPoint_Pad_D1.5mm | tht | Yes DNP |  |  |  |  | [DNP不要贴];
66 | bfs1 | 1 | DNP | ~ |  | TestPoint_Pad_D1.5mm | tht | Yes DNP |  |  |  |  | [DNP不要贴];
 |  |  |  |  |  |  |  |  | Component Cost | $94.62
 |  |  |  |  |  |  |  |  | Assembly Cost
 |  |  |  |  |  |  |  |  | PCB Cost
 |  |  |  |  |  |  |  |  | V0 Member 0% off | $0.00
 |  |  |  |  |  |  |  |  | All Total 5 Sets | $94.62

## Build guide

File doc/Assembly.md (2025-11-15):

# Inductor mounting

https://electronics.stackexchange.com/questions/18525/what-kind-of-glue-should-i-use-for-pcb-mounted-components-to-avoid-vibrations

* Silicone
  * if using silicone, use *neutral cure*
* epoxy resin

Links

https://www.reddit.com/r/AskElectronics/comments/gm7hw2/what_is_this_white_paste_between_some_components/

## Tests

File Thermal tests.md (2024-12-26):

Condition:
- Vin: 61V
- Vout: 26V
- Ambient Temp: 24-25 C
- Heatsink: 160 x 83 x 25 AK-EL83-160
- 2p TK6R8A08QM (ir2184 and 22r gate drive)
- Coil: 2 stacked sendust cores T130 (KDM KS130-060A), 19.5 turns, 1x1.8mm wire

## lying on wood
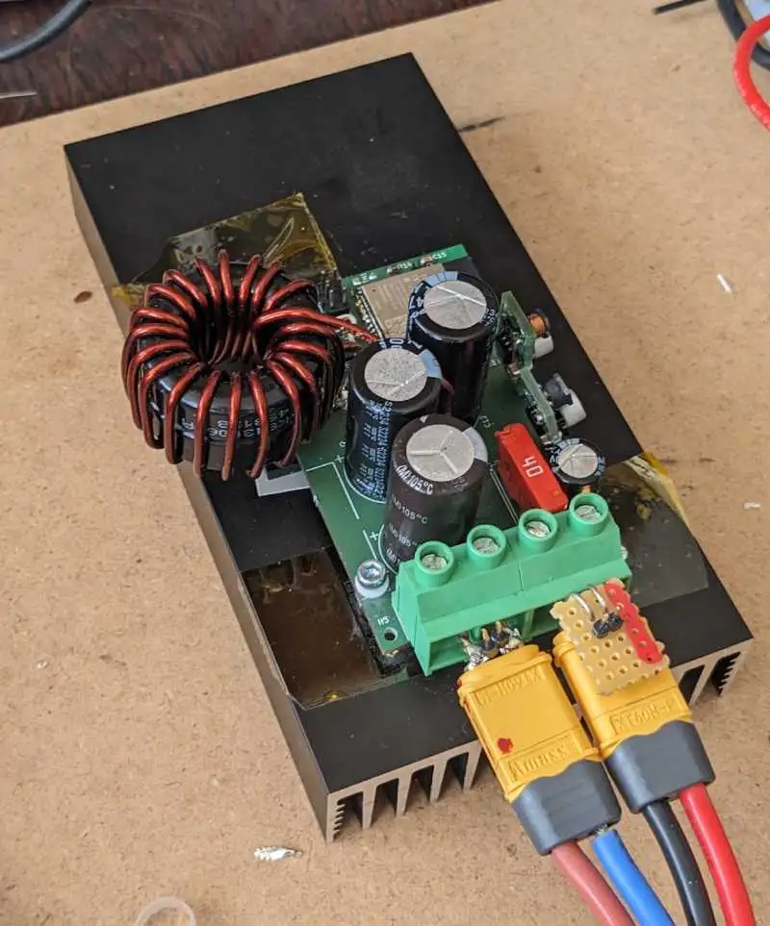
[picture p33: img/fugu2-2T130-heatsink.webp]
Fugu 2 Fugu2


Fugu 2 Fugu2 T130 heat image
*^the coil get very hot^*

* Average Power 760W
* heatsink equilibrium temp: 51 C

## in a cardbox
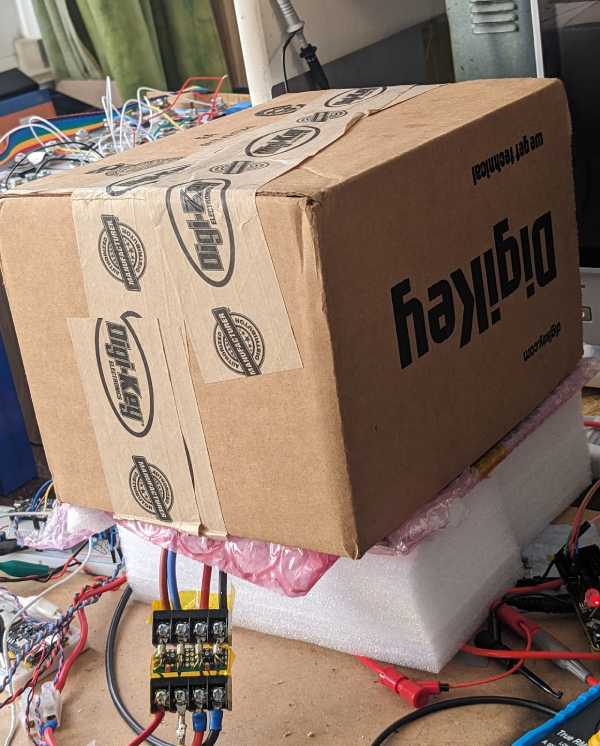
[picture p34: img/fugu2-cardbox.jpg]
Fugu 2 Fugu2 in cardbox


* avg power: 470W
* heatsink equi temp: 61 C

## T180 Coil
* 15.5 turns, 2x1.8mm wire
* avg power (in the card box): 483W  (+13W than with other coil)

Fugu 2 Fugu2 in cardbox
*^ No forced cooling ^*

Fugu 2 Fugu2 Fan cooled
*^ Cooled with a fan ^*

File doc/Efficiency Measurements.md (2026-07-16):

# Power-loop test rig

power-loop-test-rig

I build this test rig to test & measure DC-DC converters.
It runs from a 27V, 3A power supply and uses a boost converter to create a higher voltage.
This voltage is then fed into the buck DUT, and the output of the buck is fed back into the boost input.
This way we can test converters up to 1000W, with only ~60W of supply and without any super expensive bi-directional
power supplies.

* Supply power: 27V
* High voltage output (source): 15 ~ 80V
* Low voltage input (sink): 12 ~ 60V
* Max current: 38A
* Max power tested: 1000W

## Boost Converter

The boost runs in forced PWM mode for good voltage regulation. Additional we can put 1 or 2 isolated power modules
(such as the BMR6852300/001) to decouple the inputs and outputs. Without isolation, any ground-side current measurement
will be just garbage, so we need to measure the high-side currents.
The isolated modules will probably inject some noise, which can affect precision measurements.
I placed a 86V TVS (PTVS1-086C-H) at the boost output to suppress excessive overvoltage.

PWM signals of the boost and the DUT should be synchronized, otherwise any clock drift can cause significant
current noise/oscillation.

## Voltage Sensors

I use two INA228 chips (20bit power monitor) measure voltage at the DUT input terminals (aka 4-Wire Kelvin-Connection).

I've tested INA228 chips from Digikey and they perform quite well (I had bad experience with a chip from LCSC that
showed 500mV offset on the Vbus channel). I used a (broken → drifting) HP3458A and a DMM6500
as references. I ran frequent `ACAL DCV` on the HP3458A, because it has some serious drift issues. INL error when
comparing the 3458A and the DMM6500 was around <2ppm, in the 20-80V range (my power supply was noisy, want to build a
programmable low-noise PSU like drafted in
the [OPA187 datasheet](https://www.ti.com/lit/ds/symlink/opa187.pdf#page=25)).

Before I took measurements, I calibrated gain and offset of both chips to each other. Absolute voltage values
do not matter here, because we are interested in efficiency, which is computed from voltage and current ratios.
I estimate the accuracy of voltage ratio measurements with the two INA228 chips to be better than 10ppm.
More documentation [here](https://github.com/fl4p/pwr-metering/tree/main/doc/ina228-char).

## Current Sensors

For the LV side I use a Danisense DS200ID DCCT with 2 primary turns and the measure DCI with the HP3458A.
I am planning to use VPG Y16905R00000Q9L as burden resistor for the DCCT output to be able to use a voltmeter.

On the HV side I use Riedon RSN20-50 and a INA228.

* Vbus crosstalks to shunt input channel. For best accuracy use one INA228 for Vbus and another for shunt measurement
* forced air cooled
* linearity calibrated with 2nd order polyfit
* gain and offset calibrated
* estimated INL<100ppm

* DUT: ftall
    * high-side switch: 2p IPA050N10NM5S
        * gate drive: 4.7R
    * low-side switch: 2p ???
    * coil: core: 2 stack MS184075, 14 turns, 9 strands, 1.8mm copper wire coil
  * Vin=71.5 Vout=27.1 Iout=29.1A
      * efficiency: 98.12% (+-0.02% uncertainty)

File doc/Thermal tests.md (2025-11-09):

Condition:
- Vin: 61V
- Vout: 26V
- Ambient Temp: 24-25 C
- Heatsink: 160 x 83 x 25 AK-EL83-160
- 2p TK6R8A08QM (ir2184 and 22r gate drive)
- Coil: 2 stacked sendust cores T130 (KDM KS130-060A), 19.5 turns, 1x1.8mm wire

## lying on wood
Fugu 2 Fugu2

Fugu 2 Fugu2 T130 heat image
*^the coil get very hot^*

* Average Power 760W
* heatsink equilibrium temp: 51 C

## in a cardbox
Fugu 2 Fugu2 in cardbox

* avg power: 470W
* heatsink equi temp: 61 C

## T180 Coil
* 15.5 turns, 2x1.8mm wire
* avg power (in the card box): 483W  (+13W than with other coil)

Fugu 2 Fugu2 in cardbox
*^ No forced cooling ^*

Fugu 2 Fugu2 Fan cooled
*^ Cooled with a fan ^*

# Thermal meltdown
* running for an hour, Vin=75V, Vout=27, Iout=32A
* on 10x10 cm heatsink

temperature measured with TMP117 attached to heatsink:

* the HS melted at arround 00:28
* not sure what happend at 00:08
* i adjusted the output power manually to keep the temperature at 80°C, which worked for 40minutes
* then temperature dropped, and increased. 



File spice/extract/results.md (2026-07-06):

# Fugu2 commutation-loop parasitic extraction — results

FastHenry MQS extraction of the power commutation loop (SMD half-bridge Q1‖Q3 / Q2, port across nearest ceramic C16).

**Loop inductance ≈ 5.3 nH** (pitch band 4.8–5.8 nH), HF loop resistance ≈ 21 mΩ. Nominal from 1.0 mm mesh.

L(f) at 1.0 mm pitch:

| freq | R (mΩ) | L (nH) |
|---|---|---|
| 10 MHz | 21.28 | 4.82 |
| 100 MHz | 21.44 | 4.80 |

Pitch scatter over [2.0, 1.0, 0.7]mm: L = 4.8–5.8 nH (nominal 5.3 nH, ±9%). Gridded-filament plane approximation; treat as the uncertainty band.

## Suggested LTspice values (buck_parasitcs.asc)

- Hot-loop copper L (one calibrated element in the commutation path): **5.3 nH** (band 4.8–5.8)
- FET package internal L (~1–3 nH/FET): SEPARATE lumped element (FastHenry sees copper only).
- Cin electrolytic ESL: separate slow-path element, not in this fast loop.

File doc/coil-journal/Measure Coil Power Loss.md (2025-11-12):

# Power Loss

## Temperature Rise

- with the thermal resistance to ambient and the part temperature we can calculate power loss
- if thermal resistance is unknown, generate known heat power in the part
    - for coils you can simply use dc current
- if heating the part is not possible, put it in an enclosure with known thermal resistance to ambient and measure
  temperature rise inside the enclosure. note that this might increase the operating temperature if the part

## i(t)*v(t) method
- measure coil current and voltage
- i(t) * v(i) = p(t)
- cycle mean p(t)

parts might have large voltage swings, to acquire an accurate power voltage measurement needs to have a low offset and low
linearity error (coils, mosfets). the voltage probe need to have good CMRR.
current measuring can be done with hall sensors.

https://www.tek.com/en/documents/application-note/circuit-measurement-inductors-and-transformers-oscilloscope
https://www.tek.com/en/datasheet/advanced-power-measurement-and-analysis

x-y mode oscilloscope

- picoscope!
- B-H curve

https://scdn.rohde-schwarz.com/ur/pws/dl_downloads/dl_application/pdfs/Working-with-acquired-waveform-data-in-Python_ac_en_3683-5700-92_v0100.pdf

# Net Loss Method

put the part in circuit where you know the other losses or keep them as low as possible.
e.g. for a coil you can use a highly efficient GaN half-bridge, and keep capicator loss low

# Measurement Results:
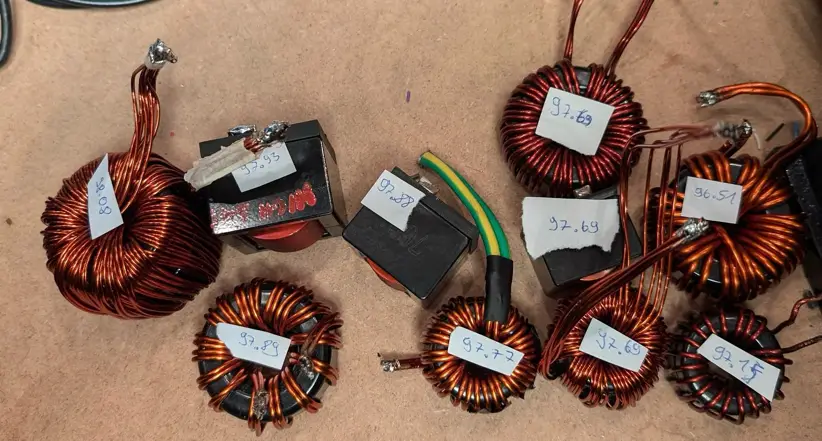
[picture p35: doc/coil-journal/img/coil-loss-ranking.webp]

coils with total converter efficiencies.
measured with ftall, 72vin/27vout P=~800W
[detailed measurement log](../../HW%20Stories/ftall.md)

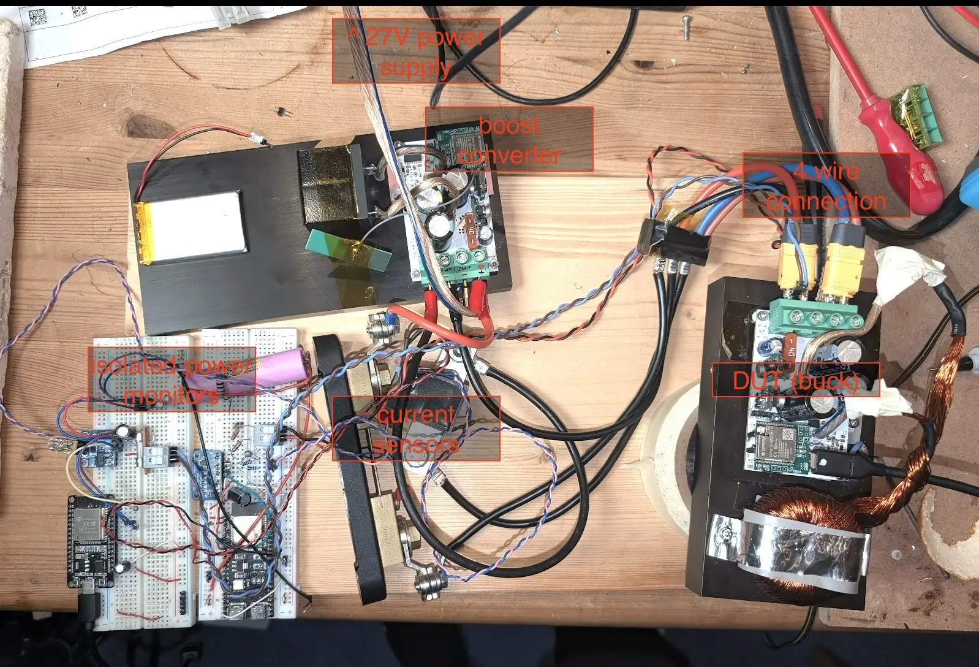
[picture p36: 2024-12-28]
img/power-loop-test.webp

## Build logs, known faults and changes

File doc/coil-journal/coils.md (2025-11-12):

# Naming Convention
```

KS184µ075s1-CuDHP180s2T24
^ KS=core mat 
  ^ 184=core outer dia (1.84 inch)
      ^ µ075=initial permeability (75µ)
         ^ s1=1 core stacked         
```
```
CuDHP180s2T24
^ wire conductor material name
     ^ conductor diameter (1.8mm) (!= wire diameter !!!)
        ^ s2=2 strands
           ^T24=24 turns
```



# KS184µ125s1-1.8mm?, 2 strands, 15 turns

# *Too Many Turns* (KS184µ075s1-CuDHP180s2T24)
KS184125A
2s 1.8mm Cu-DHP (basteldrahtm evek) awg13
24 Turns
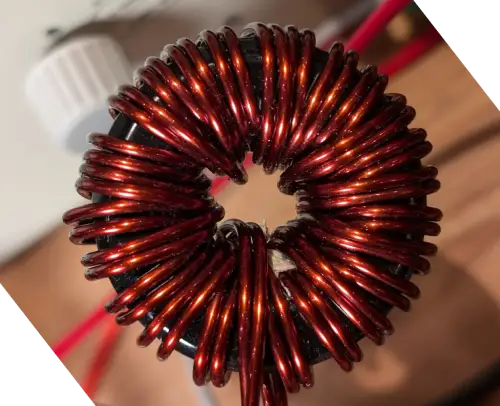
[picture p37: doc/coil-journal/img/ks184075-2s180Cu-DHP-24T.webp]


# wires
wire: https://www.ebay.de/itm/255497948294
```
Ø 1,80 mm Längenbeispiel: 100 g / ca. 4,3 m lang
Drahtdurchmesser / Nenndurchmesser: 1,80 mm
Gewicht - nur Kupferleiter ohne Lack - 8,96kg/dm³: 22,800 kg/km
Ø- Außen mit Lack Grad 2 (2L) Untere Grenzwert: 1,873 mm
Ø- Außen mit Lack Grad 2 (2L) Oberer Grenzwert: 1,909 mm
Nennwiderstand bei 20°C: 0,0067 Ω/m
```

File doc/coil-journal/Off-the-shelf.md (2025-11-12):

# Ruishen RSEQ32-470M

```
# Datasheet
L0@100khz = 47
DCR = 3(typ) | 4.5(max) mΩ
40°C temp rise current: 40 A 
Isat: 17A(20%drop) | 25A (30% drop)

```

```
Coil
turns: 18
dcr(hot) = 3.8mΩ (measured with 5A excertation current)
```

```
# tests in fbanana:

Idc=32.6A
Ipp=11.9A
V=73.6/27.1
> compute_L(73.6,27.1,39e3, 11.9)*1e6
36.8 µH (78% of L0)

Idc=14A
Ipp=10.65A
41.2 uH

Idc=6.9A
IPP=10.44A
42 µH

```

The saturation performance is good, at 32A L drops by 22%.
Versus the datasheet 25A with 30% drop.

# ftall coil inductivity

we can compute the actual inductivity with dc bias if we know Vin/Vout and the ripple current.
We can measure the ripple current with a current probe clamp and an oscilloscope. 

```
Idc=32.5A
Ipp=11.5A
V=73.6/27V
f=39khz
>>> compute_L(73.6, 27, 39e3, 12)
38.12 µH

Idc= 18.4 A
Ipp= 10.2 A
=> L = 43 µH

Idc=10.4A
Ipp=9.7A
=> L = 45 µH

Idc=5.2A
Ipp=9.5A
=> L = 46 µH

```

^ was this coodaca high sat?
# Codaca 2434 CPEX4141L-500 (high sat)
- rdc=2.27mΩ

# Codacoa

- in boost converter
- I=31A, Ipp = 14.8A
- Ploss = 4.9W std=0.33
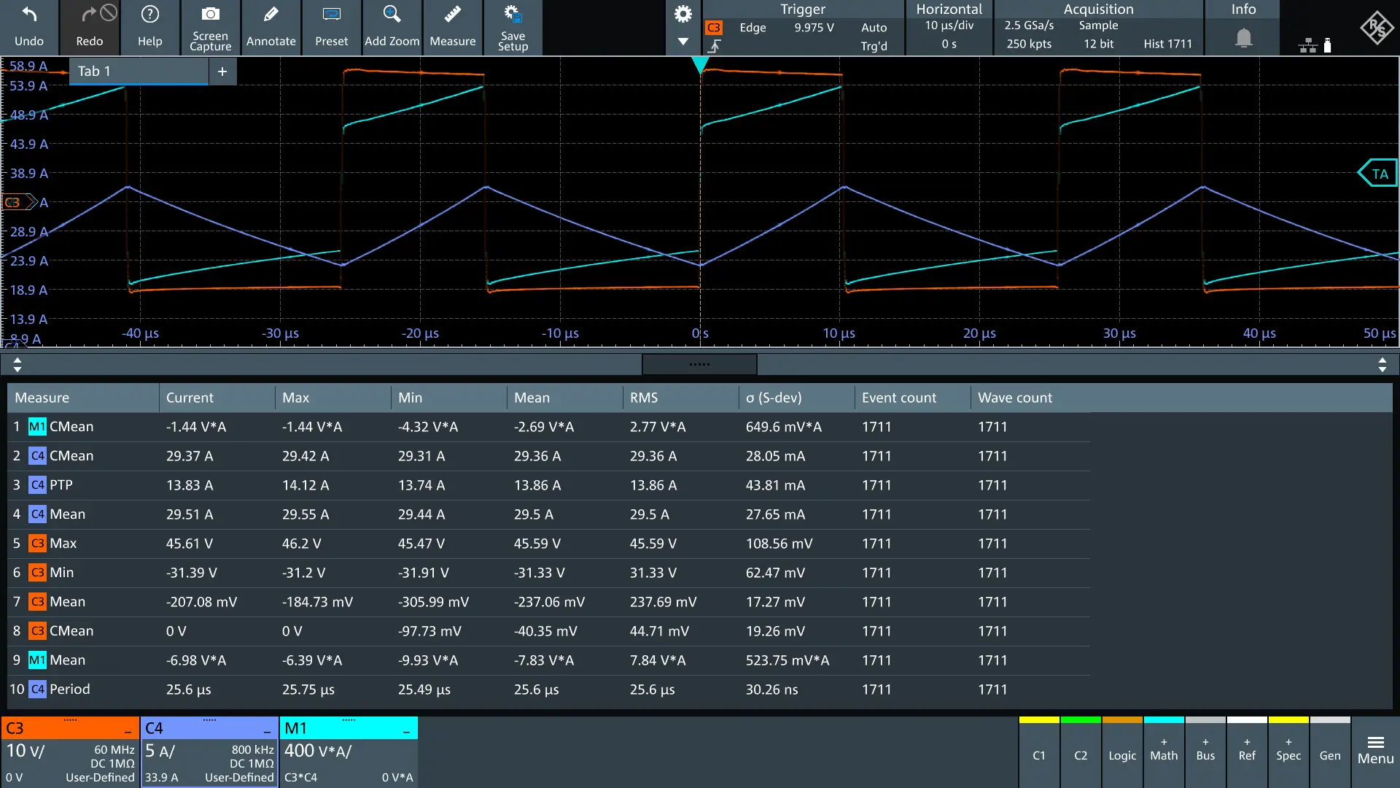
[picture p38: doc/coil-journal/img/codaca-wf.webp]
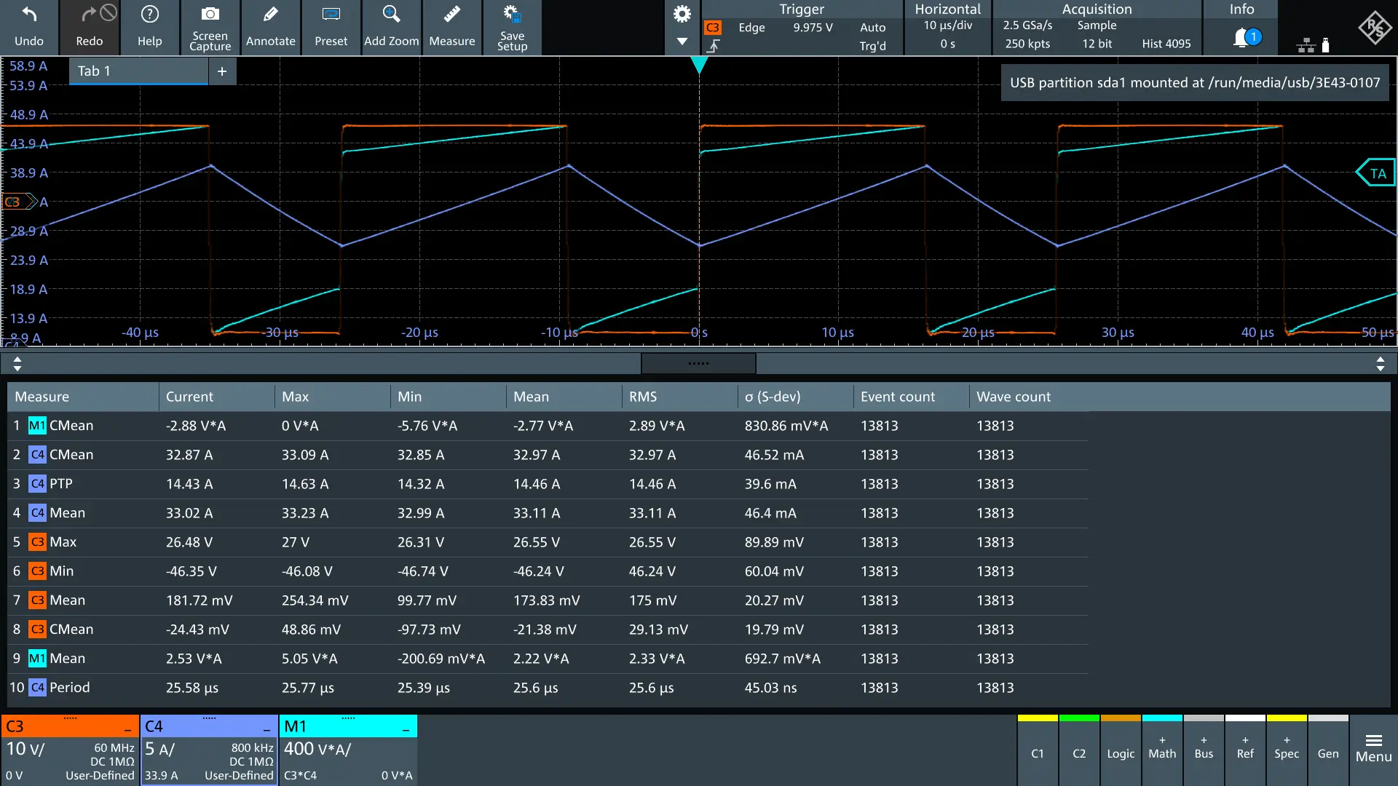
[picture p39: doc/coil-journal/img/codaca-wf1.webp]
  
- Power Measurements
    - 26/73V I=35.5A ipp=15A

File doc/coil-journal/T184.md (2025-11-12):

# KS184-125A, 1.8mm? (Cu? dark), 2 strands, 15 turns

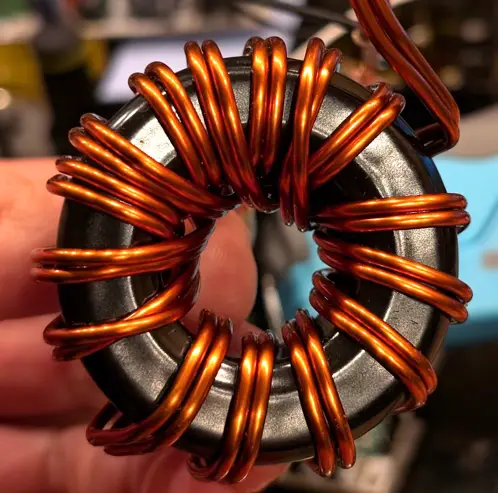
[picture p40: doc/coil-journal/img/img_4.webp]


- Power measurement:
    - V=73/28.5, I=29.7A, Ipp=18A
    - Ploss = -4.4784 std= 0.1549
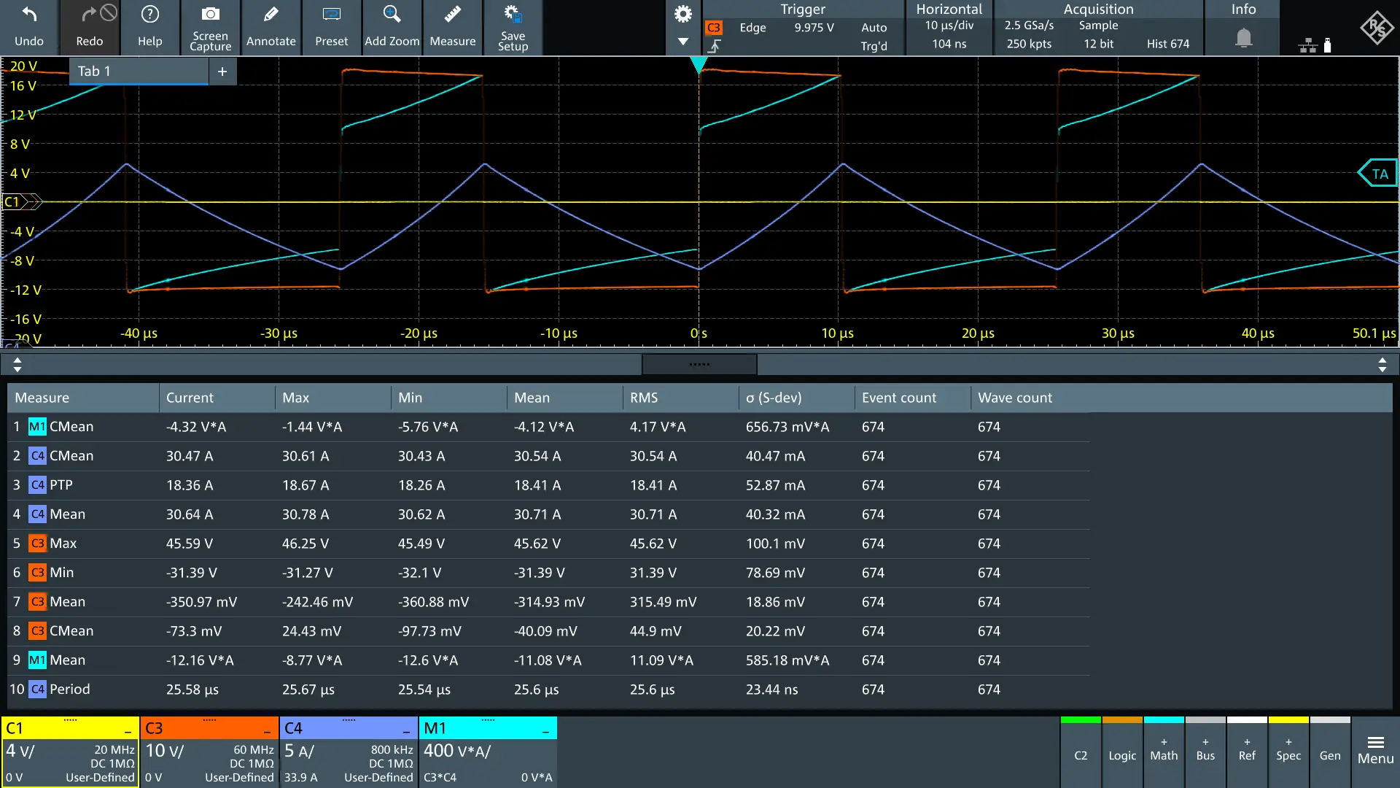
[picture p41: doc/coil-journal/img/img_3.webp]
      

Mod: added 2 turns (17 now):

L0@100khz = 79.8 µH
Rdc = 3.84mΩ

- Power measurement
    - I=30.7A Ipp=16.7 (!) => L=26.7µH (33% of L0)
    - Ploss= -3.7764 std= 0.2066

notes:
- could add more strands for higher ID usage

# KS184-125A, 1.8mm? (Cu?), 2 strands, 24turns


L0@100khz = 175.7 µH

- the coil design is not ideal
- core saturates early (u=125)
- has losses also during light load
- due to many turns, the magnetic field is even higher, core saturates

- Power measurement:
    - V=73/28.5, I=29.7A, Ipp=13A => Ldc= 34.3µH
    - Ploss = 10.6W +- 0.2W

# KS184-075A, 2.5mm CuW210, 2 strands, 17 turns

KS184-075A-CuW210-d2.5-s2-t17

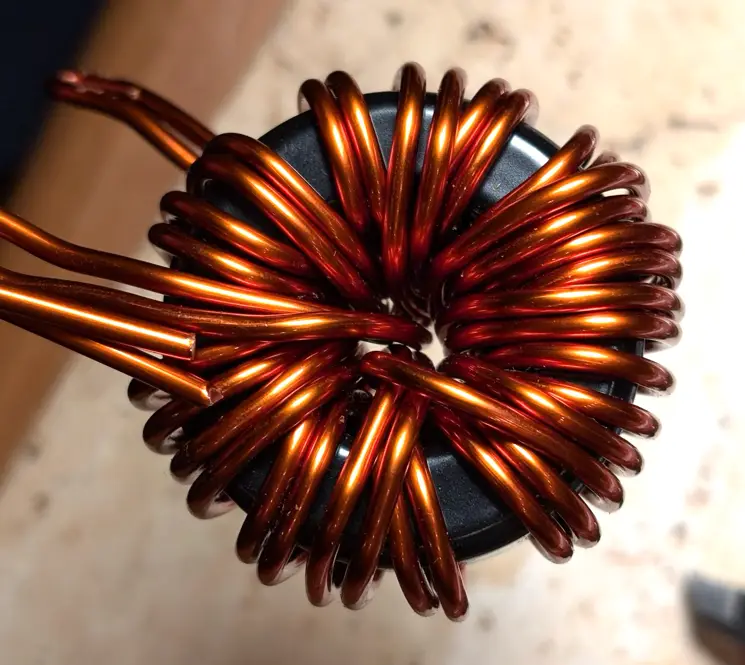
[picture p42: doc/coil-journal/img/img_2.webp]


- 2.5mm is AWG10.3
- had 3m of wire total (1.5m per strand)
- could not fit more than 17 turns
- excess 50cm
- core KS184-075A datasheet https://semic.cz/!old/files/pdf_www/Ljf_T184-S-075A_KD.pdf
- computed L0 = 48.8uH (core Al=169)
- micrometals analyzer:
    - ID ratio 0.35, which is completely off
    - 40khz, 30A: Ldc is 30-32, Ipp 12-14A, 4.8W Total loss, 2.76W copper loss
    - Rdc = 2.7mΩ, Rac factor = 7.731
- LCR meter measurement
    - DCR (4wire): 2.5mΩ
    - 1khz: 54uH, Rs=5.5mΩ
    - 10khz: 55uH, Rs=27mΩ
    - 100khz: 55uH, Rs=50mΩ
- consider using KS184-090A ?

- Power measurement:
    - V=73/28, I=30A, Ipp=14A
    - Ploss = Total Mean -5.8W std= 0.3 TODO propably wrong



# hf-litz

Core: KS185-075A
Coil: 32strands
Wire:
0.5mm wire (schneitech) AWG#24.1 or AWG#24.2
OD (with varnish): 0.545 mm .. 0.566 mm
Nennwiderstand bei 20°C: 0,0871 Ω/m (Gewicht - nur Kupferleiter ohne Lack - 8,96kg/dm³: 1,7593 kg/km)

Micrometals Analyzer:
L0 = 102.46
Ldc(30A) = 46.18 (45%)
Rdc = 0.006624
ID use ratio = 0.56
ploss(30A,27/45V,39khz) = 7.1 W (cu 6.105W)

Power Meausre:
Vin 72/28 I=29.4A, Ipp=8.08A
Vin 70/26.2 I=15.8 Ipp=4.73 => L = 89.5uH
Vin 69/26.9 I=23.2A Ipp=6.3A => L= 67.7uH
68.2/27 i=33.6 ipp=9.33 => L= 44.8uH
73.5/27.2 i=27.5 ipp=8A => L= ? TODO
i=33i=9.55

-> micrometals analyzer says 26 turns on their MS-184075-2 (same nom. Al=169nH)
inside a little paper box temperature rise is 35°C.

about 360cm total wire length pre-winding
excess after winding: 34+77
bonding wires: ?
total wound length: ?
forgot the count number of turns

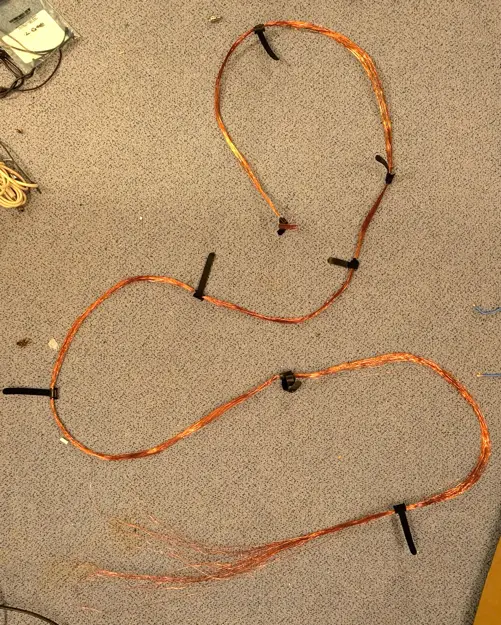
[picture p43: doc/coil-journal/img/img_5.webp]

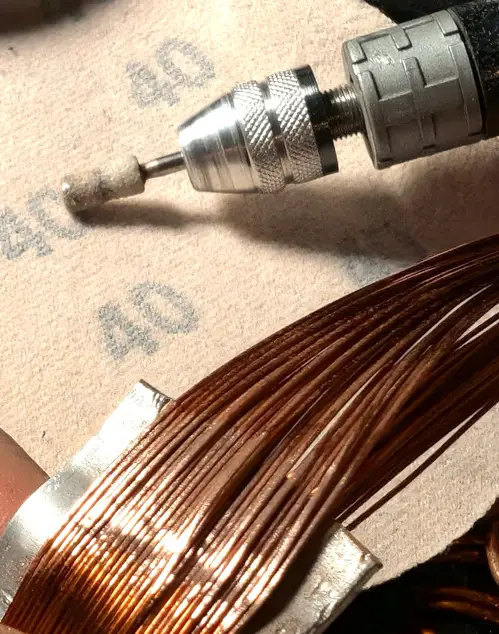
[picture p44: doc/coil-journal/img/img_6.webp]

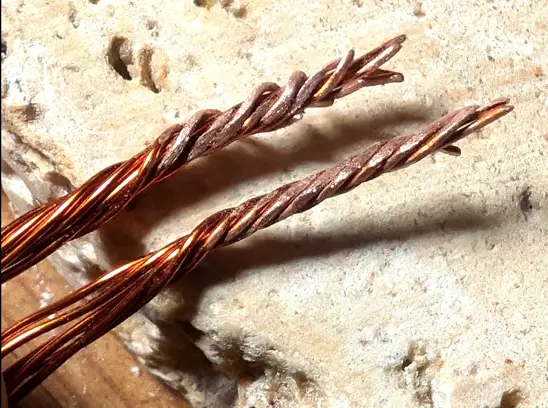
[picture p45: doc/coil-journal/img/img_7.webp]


termination
get a tool to remove the varnish
a good way seems to create bundles of 5


Rdc (4wire, keithley): 6.76mΩ
micrometals analyzer

TODO:

- measure Rdc
- measure L0
- use thermal imager to check strands

## 2s KS184-125A

- coil: w210 cu, 1.18mm, 12 strands (used 2m wire per strand)
- 10 turns?
- Measurement :
    - Vin 73.2/27.2, I=15.8A, Ipp=9.3A
    - 76/27 I=0, ipp=7
    - 73.5/27.3 I=34.3 Ipp=14.6A
    - 72.3/27.3 i=36.9 Ipp=15.6A

## 2s KS184-125A-d1.18-s10-n12

 

- coil: w210 cu, 1.18mm (schneitec), 10 strands (used 2m wire per strand)
- 12 turns?
- Rdc(keithley, 4wire clamps) = 2.43mΩ
- Measurements:
    - 73.3/27.3 I=30.4 Ipp=12.2A

TODO: 8 strands, 15 turns

# 2s Maginc equiv of MS184-075 (184075)
* has a 75 marking
* 14 turns?
* L0 = 69uH
* 3.02mΩ dcr

Idc=31.8A
Ipp=9.86A
V=73.6/27
=> Ldc=44.4µH (64%)

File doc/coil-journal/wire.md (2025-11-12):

https://elosal.de/Kupferlackdraht-Wickeldraht-18mm-G2

https://www.ebay.de/itm/255562746797

https://www.reichelt.de/de/de/shop/kategorie/kupferlackdraht-4484

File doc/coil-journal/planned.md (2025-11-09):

# T184

```
MS-184075-2
13 turns
awg 14 (1.63 conductor, 1.74 wire diameter, bundle: 4.63, IDuse= 0.41)
strands 6
stack 2
=> or 1.18mm wire (awg 16.8) and 9 strands <= TODO build this with core 77443a7 229357
actually put 14 turns, 
```

```
single T184

```

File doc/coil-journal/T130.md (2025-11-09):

2s KS130-060A
- 2s 1.8mm wire (cu?)
- 20 turns (no more possible, ID full)

Power Measurement:
- 73/28V, I=25.6A, Ipp=15A
  - Ploss = -3.7929 std= 0.1924
- 73/28V I = 29A, Ipp=16.5A
  -  -3.749 std= 0.1898

"earthin wire coil"
2s core
4.75mΩ
19 turns, 2 strands
1.9mm wire diameter

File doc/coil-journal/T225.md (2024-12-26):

2 stacked KS225060A
micrometals analyzer says:
21 turns, awg 16.7 (1.19cu, 1.3wire dia/mm)
  15 strands bundle d =5.7mm
  ID use =  0.47

could only fit 10? turns.

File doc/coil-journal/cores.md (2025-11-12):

# Toroids

| | T130 | T184-H19 | | |
|-----|---|---|---|---|
| 60  | | | | |
| 75  | | | | |
| | | | | |
| 125 | | (281nH) [kdm](https://www.semic.info/ljf-t184-s-125a-bk/), [MagInc](https://www.digikey.de/en/products/detail/magnetics-a-division-of-spang-co/0077438A7/18626927) | | |

# Non-toroidal

https://www.tme.eu/en/katalog/ferrite-cores_112517/?params=464:1506008,1711710,1711782&productListOrderDir=ASC&productListOrderBy=1000014&onlyInStock=1

https://www.tme.eu/en/details/b65813j0250a041/ferrite-cores/epcos-tdk/

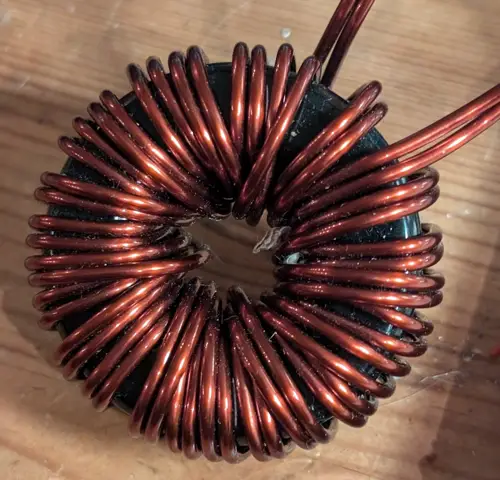
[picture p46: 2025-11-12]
doc/coil-journal/img/too-many-turns.webp

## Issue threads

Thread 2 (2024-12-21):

USB-C plug

fl4p, 2024-12-21:
place it so that it can be accessed with an enclosure

samuk, 2025-03-14:
Some parts that might be interesting in a [development context](https://talk.libre.solar/t/community-development-of-new-20a-mppt/121/5)

Small system for a 30w panel

[12.4v Sodium pack](https://vi.aliexpress.com/item/1005007901478757.html) 75AH
[8m -14m USB-C cable](https://vi.aliexpress.com/item/1005007307838164.html)
[USB LED](https://vi.aliexpress.com/item/1005004146259625.html)

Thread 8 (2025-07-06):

mcu-head submodule appears to be dead

CapnKernel, 2025-07-06:
This repo contains two submodules, which get fetched into two subdirs, `psu` and `mcu-head`.  The latter submodule is now 404.

```
[mjd@xiaomao Fugu2]$ cat .gitmodules
[submodule "buck100-LM5163"]
	path = psu
	url = https://github.com/open-pe/buck100-LM5163
[submodule "mcu-head"]
	path = mcu-head
	url = https://github.com/open-pe/mcu-head-p12-esp32s3-wroom
[mjd@xiaomao Fugu2]$ curl -o /dev/null -s -w "%{http_code}\n" https://github.com/open-pe/buck100-LM5163
200
[mjd@xiaomao Fugu2]$ curl -o /dev/null -s -w "%{http_code}\n" https://github.com/open-pe/mcu-head-p12-esp32s3-wroom
404
[mjd@xiaomao Fugu2]$
```

fl4p, 2025-09-01:
Hi, the repository was accidentally private, you can now access it https://github.com/open-pe/mcu-head-p12-esp32s3-wroom

Closed 2025-09-01.

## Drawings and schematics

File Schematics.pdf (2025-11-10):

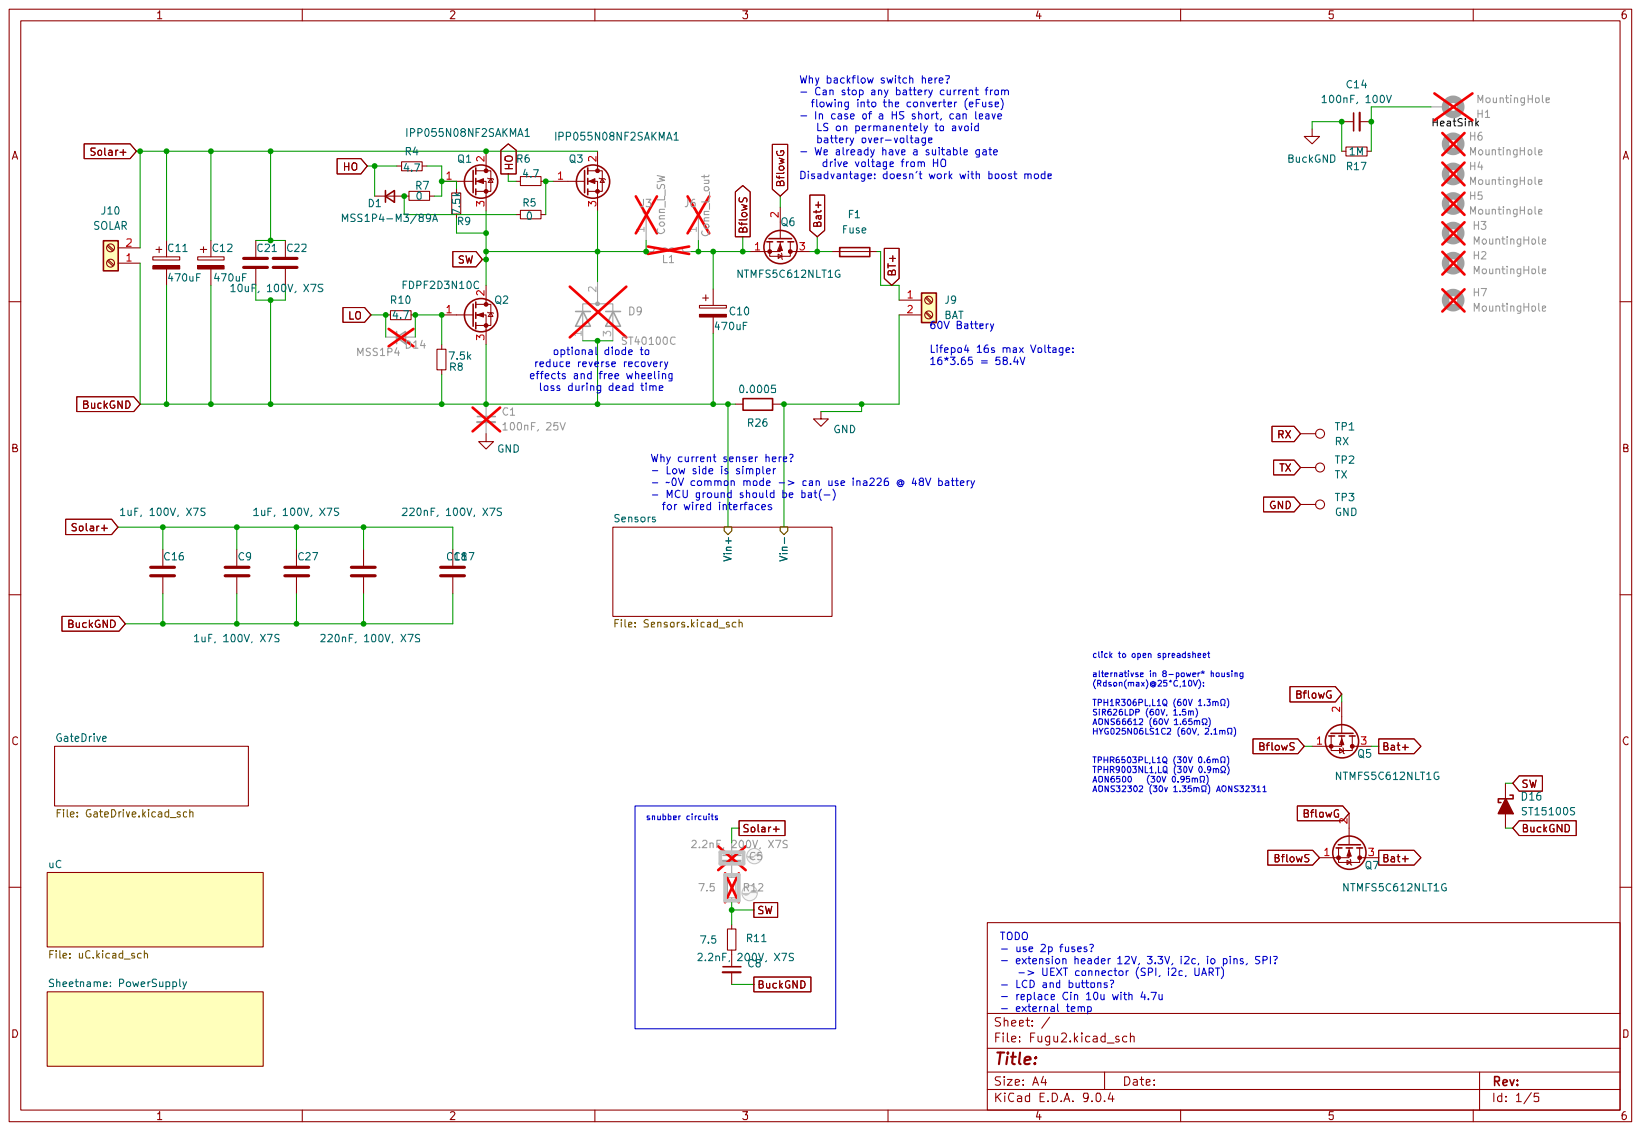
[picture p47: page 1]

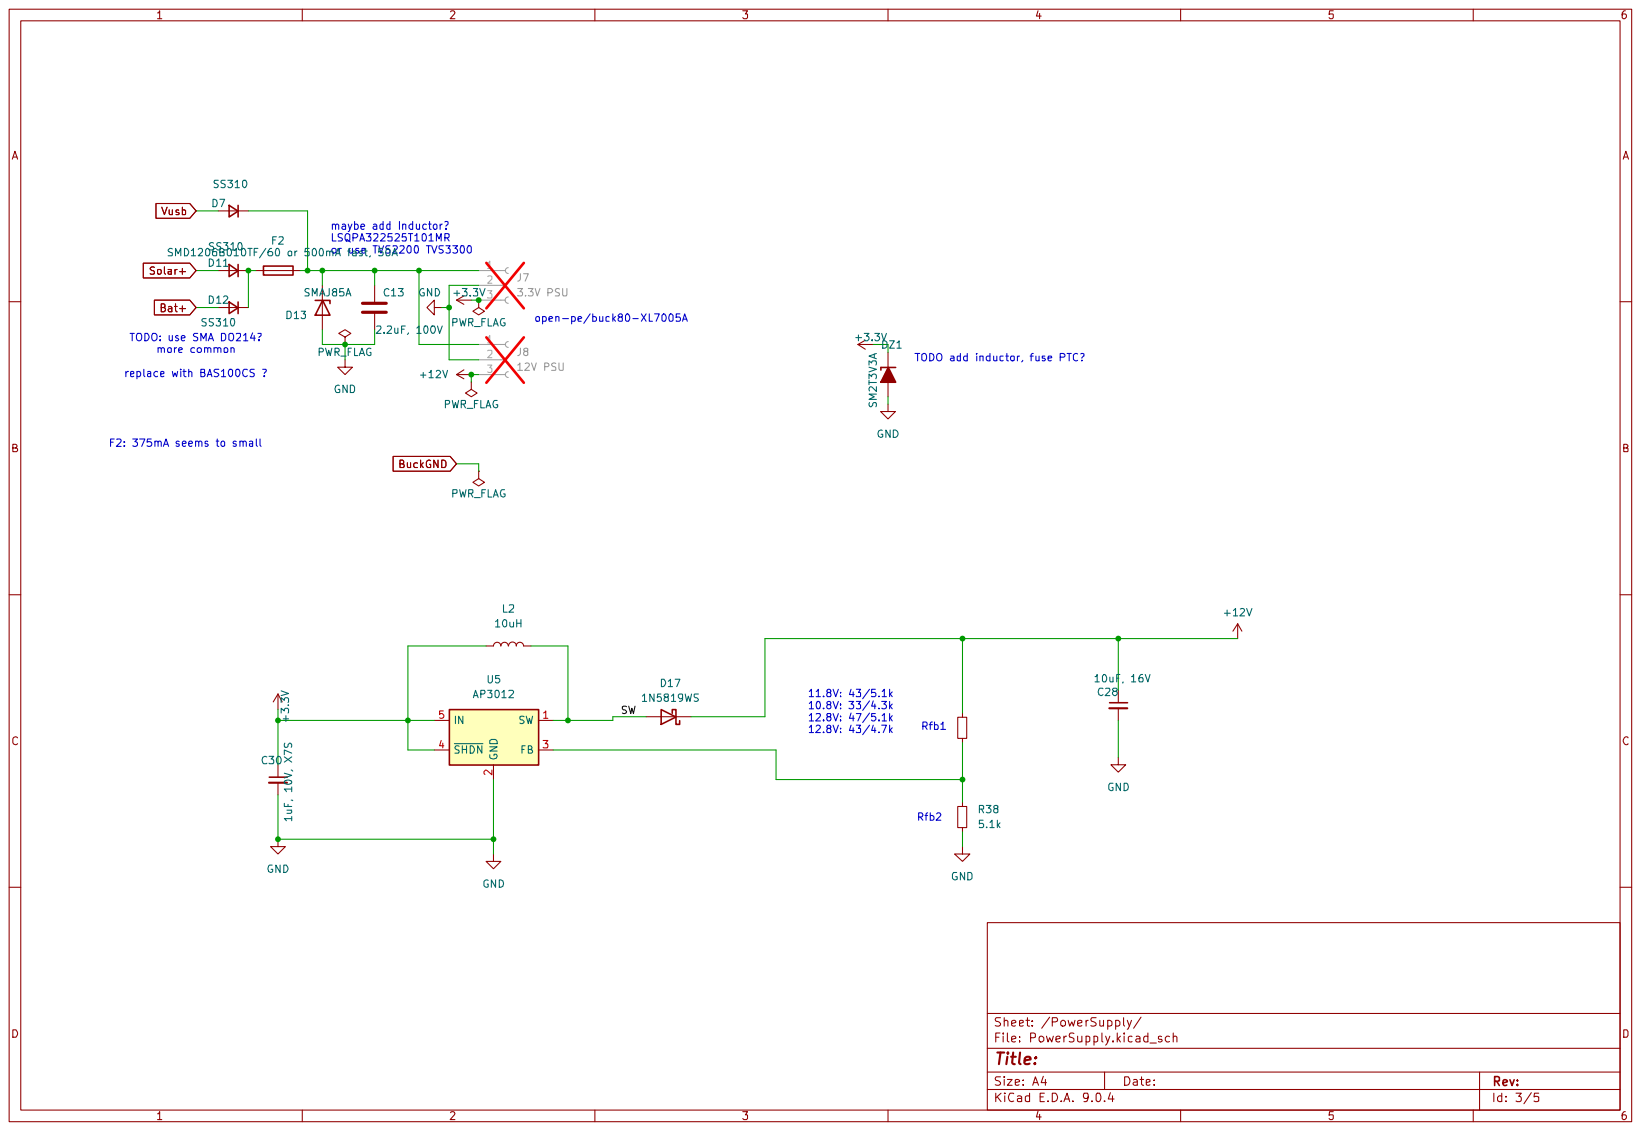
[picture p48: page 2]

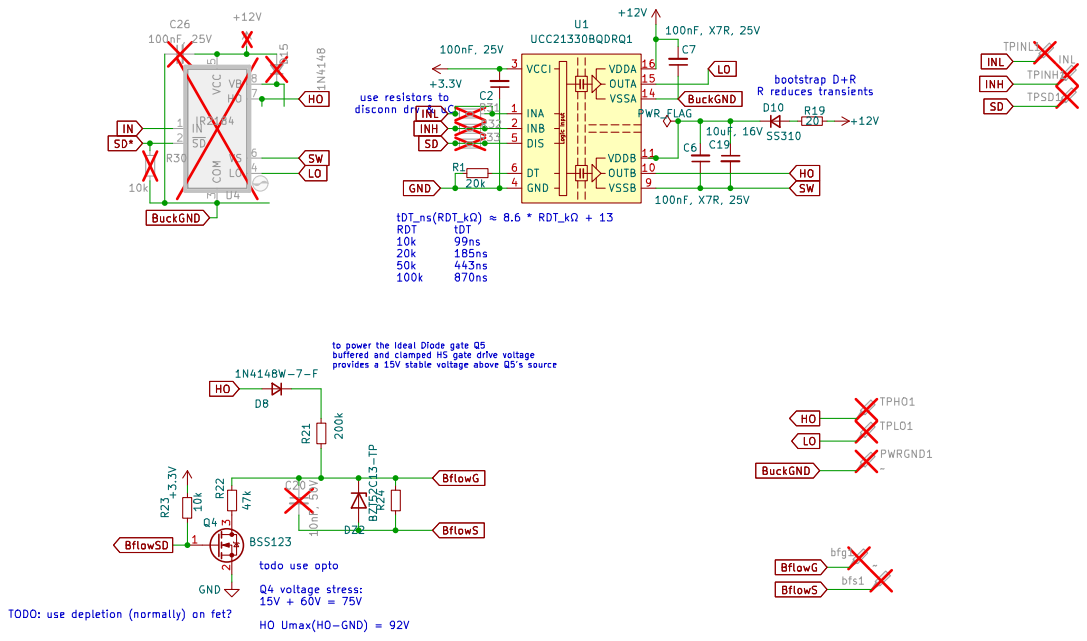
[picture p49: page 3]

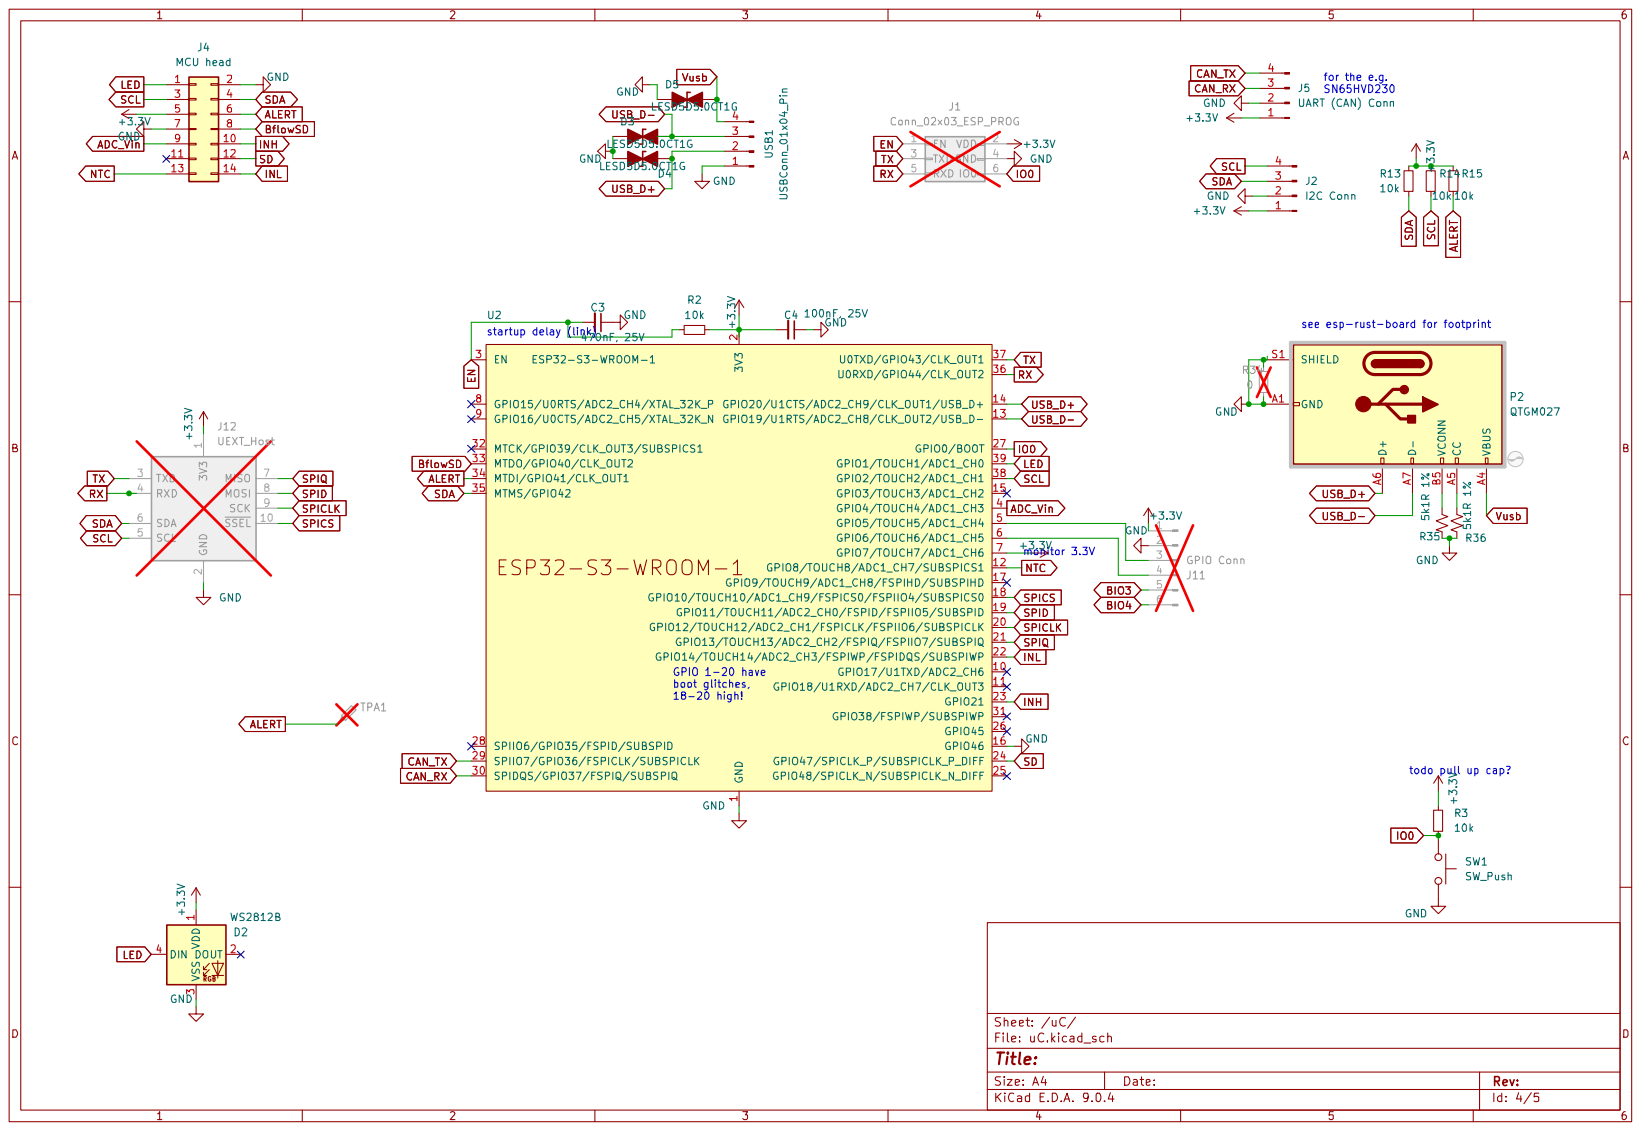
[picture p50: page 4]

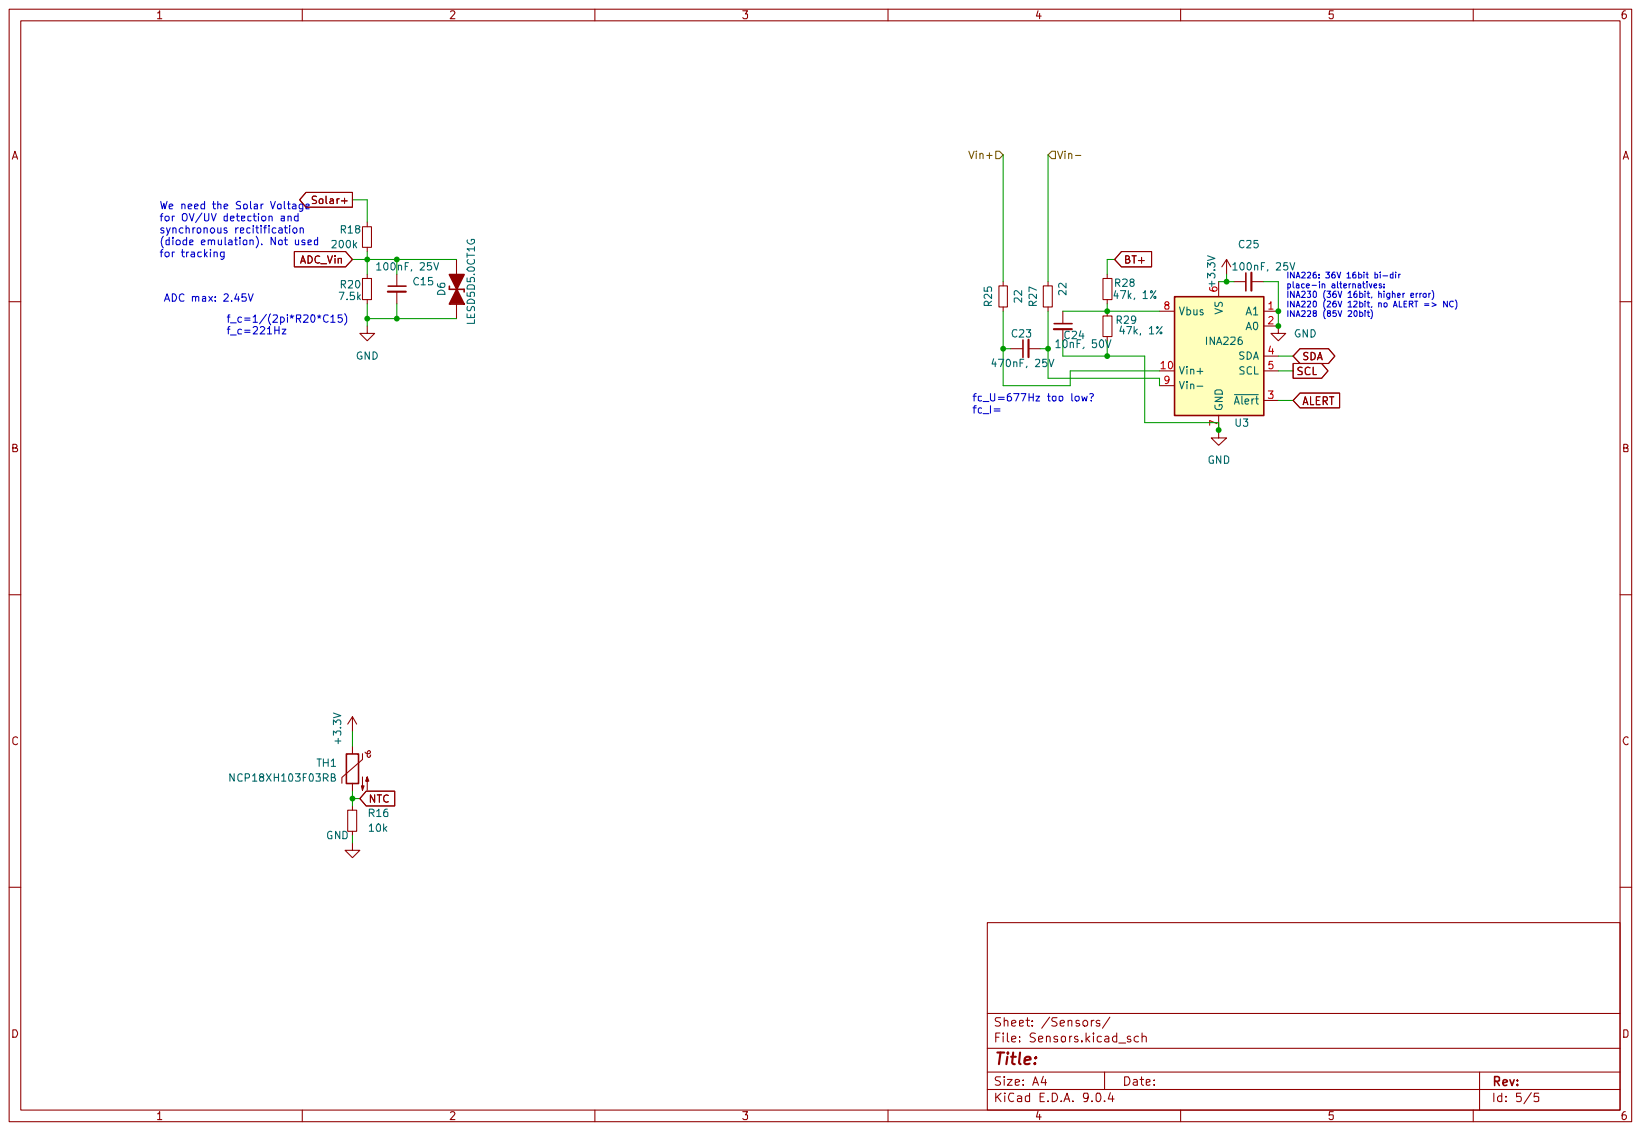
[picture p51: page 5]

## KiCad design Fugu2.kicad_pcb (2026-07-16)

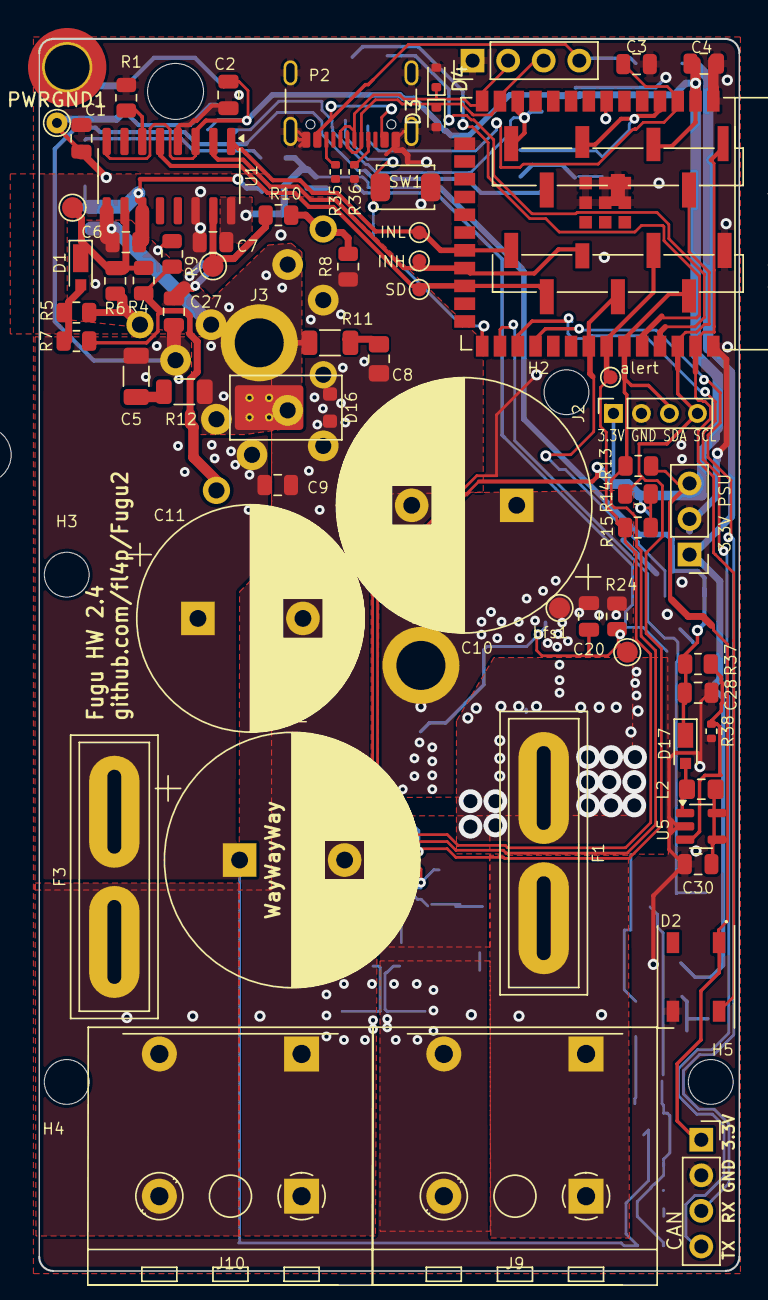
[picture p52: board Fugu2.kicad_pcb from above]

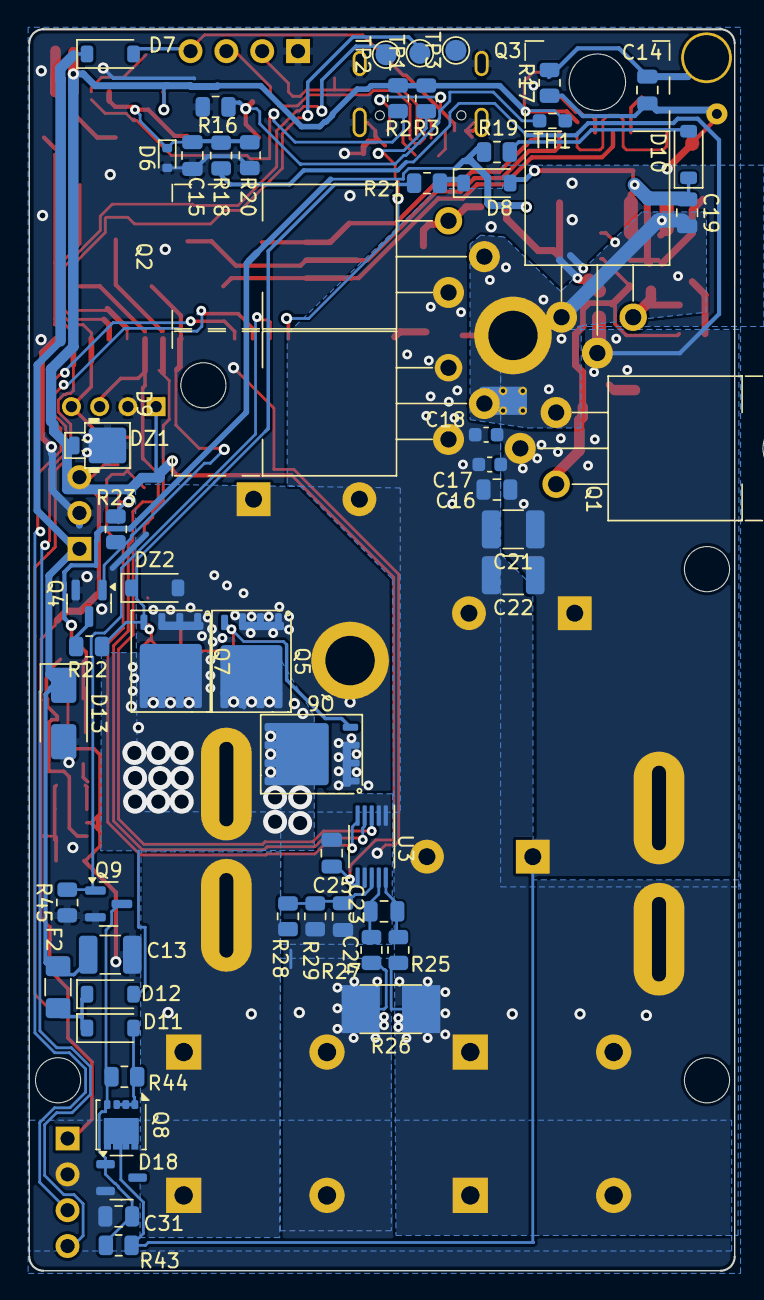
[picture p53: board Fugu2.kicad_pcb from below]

Board: 2 copper layers, 50.0 x 88.0 mm, 128 parts (57 on the bottom side), 56 nets.

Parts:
C1: 100nF, 25V; C_0805_2012Metric
C2, C4, C6, C7, C25: 100nF, X7R, 25V; C_0805_2012Metric
C3, C23, C30: 1uF, 10V, X7S; C_0805_2012Metric
C5: 2.2nF, 200V, X7S; C_1206_3216Metric
C8: 2.2nF, 200V, X7S; C_0805_2012Metric_Pad1.18x1.45mm_HandSolder
C9, C14, C16, C27: 1uF, 100V, X7S; C_0805_2012Metric
C10, C12: 470uF, 100V; CP_Radial_D18.0mm_P7.50mm
C11: 470uF, 100V; CP_Radial_D16.0mm_P7.50mm
C13: 4.7uF, 100V; C_1210_3225Metric_Pad1.33x2.70mm_HandSolder
C15, C20, C24, C31: 10nF, 100V; C_0805_2012Metric
C17, C18: 220nF, 100V, X7S; C_0603_1608Metric
C19, C28: 10uF, 16V; C_0805_2012Metric
C21, C22: 10uF, 100V, X7S; C_1210_3225Metric_Pad1.33x2.70mm_HandSolder
D1, D17: MSS1P4-M3/89A; D_MicroSMP_AK
D2: WS2812B; LED_WS2812B_PLCC4_5.0x5.0mm_P3.2mm
D3, D4, D6: LESD5D5.0CT1G; D_SOD-523
D7, D8, D10, D11, D12: SS310; D_SOD-123
D9: ST40100C; TO-220-3_Horizontal_BottomHeatsink_NoHole
D13: SMAJ85A; D_SMA
D16: ST15100S; TO-277B_ThermalVias
D18: 62V; SOT-23-3
DZ1: SM2T3V3A; D_Powermite_KA
DZ2: BZT52C13-TP; D_SOD-123
F1, F3: 40A; Fuse_Blade_ATO_directSolderThin
F2: SMD1206B010TF/60 or 500mA fast, 50A; Fuse_1206_3216Metric_Pad1.42x1.75mm_HandSolder
H1: MountingHole; MountingHole_3.2mm_M3_DIN965_Pad_TopOnly
H2, H3, H4, H5: MountingHole; MountingHole_3.2mm_M3_DIN965
J2: I2C Conn; PinSocket_1x04_P2.00mm_Vertical
J3: Conn_L_SW; SolderWire-1x01_D3.5mm
J4: MCU head; PinHeader_2x07_P2.54mm_Vertical_SMD_Pin1Left
J5: UART (CAN) Conn; PinSocket_1x04_P2.54mm_Vertical
J6: Conn_L_out; SolderWire-1x01_D3.5mm
J7: 3.3V PSU; PinHeader_1x03_P2.54mm_Vertical
J9, J10: 691256610002; TerminalBlock_WR-TBL_2566_1x02_P10.16mm
L2: 10uH; L_0805_2012Metric_Pad1.15x1.40mm_HandSolder
P2: QTGM027; USB_C_Receptacle_GCT_USB4105-xx-A_16P_TopMnt_Horizontal
PWRGND1: TestPoint_THTPad_D1.5mm_Drill0.7mm
Q1, Q3: IPA050N10NM5S; TO-220-3_Horizontal_BottomHeatsink_SmallHole
Q2: IPP022N12NM6; TO-220-3_Horizontal_BottomHeatsink_NoHole
Q4, Q9: BSS123; SOT-23
Q5, Q6, Q7: TPH1R306PL,L1Q or NTMFS5C612NLT1G; Infineon_PG-TDSON-8_FL
Q8: GT800N10D3; VSON-8_3.3x3.3mm_P0.65mm_NexFET
R1: 20k; R_0805_2012Metric
R2, R3, R8, R9, R13, R14, R15, R16, R23, R45: 10k; R_0805_2012Metric
R4, R6, R10: 4.7, 1%; R_0805_2012Metric
R5, R7: 2.2, 1%; R_0805_2012Metric
R11, R12: 7.5; R_1206_3216Metric
R17, R18, R21, R43, R44: 200k; R_0805_2012Metric
R19, R25, R27: 22; R_0805_2012Metric
R20: 7.5k; R_0805_2012Metric
R22, R28, R29: 47k, 1%; R_0805_2012Metric
R24: 1M; R_0805_2012Metric
R26: 0.0005; R_2512_6332Metric_Pad2.72x3.40mm_HandSolder
R35, R36, R38: 5.1k 1%; R_0402_1005Metric
R37: 33k; R_0805_2012Metric
SW1: SW_Push; SW_Push_SPST_NO_Alps_SKRK
TH1: NCP18XH103F03RB; R_0603_1608Metric_Pad0.98x0.95mm_HandSolder
TP1: RX; TestPoint_Pad_D1.5mm
TP2: TX; TestPoint_Pad_D1.5mm
TP3: GND; TestPoint_Pad_D1.5mm
TPA1: alert; TestPoint_Pad_D1.0mm
TPHO1: TestPoint_Pad_D1.5mm
TPINH1: INH; TestPoint_Pad_D1.0mm
TPINL1: INL; TestPoint_Pad_D1.0mm
TPLO1: TP_PWM_LO; TestPoint_Pad_D1.5mm
TPSD1: SD; TestPoint_Pad_D1.0mm
U1: UCC21330BQDRQ1; SOIC-16_3.9x9.9mm_P1.27mm
U2: ESP32-S3-WROOM-1-N4; ESP32-S3-WROOM-1-noPIN15
U3: INA226; VSSOP-10_3x3mm_P0.5mm
U5: AP3012; SOT-23-5
USB1: USBConn_01x04_Pin; PinHeader_1x04_P2.54mm_Vertical
bfg1: TestPoint_Pad_D1.5mm
bfs1: TestPoint_Pad_D1.5mm

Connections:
+3.3V: C2.2, C4.2, C25.1, C30.1, D2.1 (VDD), DZ1.1 (K), J2.1, J4.5, J5.1, J7.3, L2.1, R2.1, R3.1, R13.2, R14.2, R15.2, R23.2, TH1.1, U1.3 (VCCI), U1.8 (VCCI), U2.2 (3V3), U2.7 (GPIO7/TOUCH7/ADC1_CH6), U3.6 (VS), U5.4 (~SHDN), U5.5 (IN)
+12V: C7.2, C28.1, D17.1 (K), R19.2, R37.1, U1.16 (VDDA)
/PowerSupply/SW: D17.2 (A), L2.2, U5.1 (SW)
ADC_Vin: C15.1, D6.1 (K), J4.9, R18.1, R20.2, U2.4 (GPIO4/TOUCH4/ADC1_CH3)
ALERT: J4.6, R15.1, TPA1.1, U2.34 (MTDI/GPIO41/CLK_OUT1), U3.3 (~Alert)
BT+: F1.2, J9.1, R28.2
Bat+: D12.2 (A), F1.1, Q5.3 (D), Q6.3 (D), Q7.3 (D)
BflowG: C20.1, DZ2.1 (K), Q5.2 (G), Q6.2 (G), Q7.2 (G), R21.1, R22.2, R24.2, bfg1.1
BflowS: C10.1, C20.2, DZ2.2 (A), J6.1, Q5.1 (S), Q6.1 (S), Q7.1 (S), R24.1, bfs1.1
BflowSD: J4.8, Q4.1 (G), R23.1, U2.33 (MTDO/GPIO40/CLK_OUT2)
BuckGND: C1.1, C7.1, C8.2, C9.2, C10.2, C11.2, C12.2, C14.1, C16.2, C17.2, C18.2, C21.2, C22.2, C27.2, D9.1 (K), D9.3 (K), D16.A, J10.1, PWRGND1.1, Q2.3 (S), R8.1, R17.1, R25.2, R26.1, U1.14 (VSSA)
CAN_RX: J5.3, U2.30 (SPIDQS/GPIO37/FSPIQ/SUBSPIQ)
CAN_TX: J5.4, U2.29 (SPIIO7/GPIO36/FSPICLK/SUBSPICLK)
EN: C3.2, R2.2, U2.3 (EN)
GND: C1.2, C2.1, C3.1, C4.1, C13.2, C15.2, C24.2, C25.2, C28.2, C30.2, C31.2, D2.3 (VSS), D3.2 (A), D4.2 (A), D6.2 (A), D13.2 (A), D18.2 (A), DZ1.2 (A), J2.2, J4.2, J4.7, J5.2, J7.2, J9.2, P2.A1 (GND), P2.A12 (GND), P2.B1 (GND), P2.B12 (GND), P2.S1 (SHIELD), Q4.2 (S), Q9.2 (S), R1.2, R16.1, R20.1, R26.2, R27.2, R29.1, R35.2, R36.2, R38.2, R45.1, SW1.2, TP3.1, U1.4 (GND), U2.1 (GND), U2.16 (GPIO46), U2.40 (GND), U2.41 (GND), U3.1 (A1), U3.2 (A0), U3.7 (GND), U5.2 (GND), USB1.1
HO: D1.1 (K), R4.1, R6.1, TPHO1.1, U1.10 (OUTB)
INH: J4.10, TPINH1.1, U1.2 (INB), U2.23 (GPIO21)
INL: J4.14, TPINL1.1, U1.1 (INA), U2.22 (GPIO14/TOUCH14/ADC2_CH3/FSPIWP/FSPIDQS/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)
IO0: R3.2, SW1.1, U2.27 (GPIO0/BOOT)
LED: D2.4 (DIN), J4.1, U2.39 (GPIO1/TOUCH1/ADC1_CH0)
LO: R10.1, TPLO1.1, U1.15 (OUTA)
LV_PGOOD: Q9.1 (G), R45.2, U2.28 (SPIIO6/GPIO35/FSPID/SUBSPID)
NTC: J4.13, R16.2, TH1.2, U2.12 (GPIO8/TOUCH8/ADC1_CH7/SUBSPICS1)
unnamed: C5.2, R12.1
unnamed: C8.1, R11.2
unnamed: C14.2, H1.1, R17.2
unnamed: D1.2 (A), R5.2, R7.2
unnamed: D8.1 (K), R21.2
unnamed: D10.2 (A), R19.1
unnamed: C6.2, C19.1, D8.2 (A), D10.1 (K), U1.11 (VDDB)
unnamed: D11.2 (A), Q8.1 (S), R44.2
unnamed: D11.1 (K), D12.1 (K), F2.1
unnamed: C13.1, D7.1 (K), D13.1 (K), F2.2, J7.1
unnamed: C31.1, D18.1 (K), Q8.2 (G), Q9.3 (D), R43.2, R44.1
unnamed: P2.A5 (CC), R36.1
unnamed: P2.B5 (VCONN), R35.1
unnamed: Q1.1 (G), R4.2, R7.1, R9.2
unnamed: Q2.1 (G), R8.2, R10.2
unnamed: Q3.1 (G), R5.1, R6.2
unnamed: Q4.3 (D), R22.1
unnamed: R1.1, U1.6 (DT)
unnamed: C24.1, R28.1, R29.2, U3.8 (Vbus)
unnamed: C23.1, R25.1, U3.10 (Vin+)
unnamed: C23.2, R27.1, U3.9 (Vin-)
unnamed: R37.2, R38.1, U5.3 (FB)
RX: TP1.1, U2.36 (U0RXD/GPIO44/CLK_OUT2)
SCL: J2.4, J4.3, R14.1, U2.38 (GPIO2/TOUCH2/ADC1_CH1), U3.5 (SCL)
SD: J4.12, TPSD1.1, U1.5 (DIS), U2.24 (GPIO47/SPICLK_P/SUBSPICLK_P_DIFF)
SDA: J2.3, J4.4, R13.1, U2.35 (MTMS/GPIO42), U3.4 (SDA)
SW: C6.1, C19.2, D9.2 (A), D16.K, J3.1, Q1.3 (S), Q2.2 (D), Q3.3 (S), R9.1, R11.1, R12.2, U1.9 (VSSB)
Solar+: C5.1, C9.1, C11.1, C12.1, C16.1, C17.1, C18.1, C21.1, C22.1, C27.1, F3.2, Q1.2 (D), Q3.2 (D), Q8.3 (D), R18.2, R43.1
TX: TP2.1, U2.37 (U0TXD/GPIO43/CLK_OUT1)
T_HV+: F3.1, J10.2
USB_D+: D4.1 (K), P2.A6 (D+), U2.14 (GPIO20/U1CTS/ADC2_CH9/CLK_OUT1/USB_D+), USB1.2
USB_D-: D3.1 (K), P2.A7 (D-), U2.13 (GPIO19/U1RTS/ADC2_CH8/CLK_OUT2/USB_D-), USB1.3
Vusb: D7.2 (A), P2.A4 (VBUS), P2.A9 (VBUS), P2.B4 (VBUS), P2.B9 (VBUS), USB1.4

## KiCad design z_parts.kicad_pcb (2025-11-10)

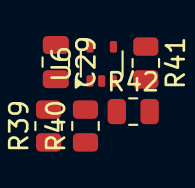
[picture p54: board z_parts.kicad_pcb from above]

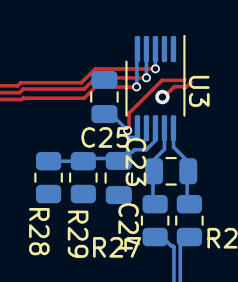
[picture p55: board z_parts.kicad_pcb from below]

Board: 2 copper layers, 14 parts (8 on the bottom side), 9 nets.

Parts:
C23: 470nF, 25V; C_0805_2012Metric
C24: 10nF, 50V; C_0805_2012Metric
C25, C29: 100nF, 25V; C_0805_2012Metric
R25, R27: 22; R_0805_2012Metric
R28, R29: 47k, 1%; R_0805_2012Metric
R39, R40, R41, R42: R_Small; R_0805_2012Metric
U3: INA226; VSSOP-10_3x3mm_P0.5mm
U6: ADS333; SOT-353_SC-70-5

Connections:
+3.3V: C25.1, C29.1, U3.6 (VS), U6.5 (V+)
BuckGND: C29.2, R25.2, R40.1, R42.2, U6.2 (V-)
GND: C24.2, C25.2, R27.2, R29.1, R39.1, U3.1 (A1), U3.2 (A0), U3.7 (GND)
unnamed: R41.1, U6.4
unnamed: C24.1, R28.1, R29.2, U3.8 (Vbus)
unnamed: C23.1, R25.1, U3.10 (Vin+)
unnamed: C23.2, R27.1, U3.9 (Vin-)
unnamed: R39.2, R42.1, U6.1 (+)
unnamed: R40.2, R41.2, U6.3 (-)

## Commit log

2023-08-03 rearregned buck
    [Fugu2.kicad_pcb]
2023-08-04 all footprints assigned
    [Fugu2.kicad_pcb, Fugu2.kicad_sch]
2023-08-08 sent to production
    [Fugu2.kicad_pcb, Fugu2.kicad_sch]
2023-08-09 updated MPNs
    [Fugu2.kicad_pcb, Fugu2.kicad_sch]
2023-08-09 gate drive circuit
    [Fugu2.kicad_pcb, Fugu2.kicad_sch]
2023-08-09 fix gate drive bootstrap VS
    [Fugu2.kicad_pcb, Fugu2.kicad_sch]
2023-08-14 fix DRC
    [Fugu2.kicad_pcb, Fugu2.kicad_sch]
2023-08-19 fix bflow FP, add connectors
    [Fugu2.kicad_pcb, Fugu2.kicad_sch]
2023-09-02 pcb
    gate driver ground to buck ground
    add LS diode
    add connectors& test points
    [Fugu2.kicad_pcb, Fugu2.kicad_sch]
2023-09-04 add another backflow switch
    [Fugu2.kicad_sch]
2023-09-04 larger inductor holes
    [Fugu2.kicad_pcb, Fugu2.kicad_sch]
2023-09-04 pcb page orientation
    [Fugu2.kicad_pcb]
2023-12-01 big update
    grouped schematics
    burden resistor footprint
    mounting holes
    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
    [Fugu2.kicad_pcb, Fugu2.kicad_sch, PowerSupply.kicad_sch]
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2024-10-19 UCC21330x, uC header, fMetal opt, 80x50mm board outline
    [Fugu2.kicad_pcb, Fugu2.kicad_sch, GateDrive.kicad_sch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]
2024-10-19 clean tracks
    [Fugu2.kicad_pcb]
2024-10-24 LS diode
    [Fugu2.kicad_pcb, Fugu2.kicad_sch, GateDrive.kicad_sch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]
2024-10-25 add SMD LS diode, add MPNs
    [Fugu2.kicad_pcb, Fugu2.kicad_sch, GateDrive.kicad_sch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]
2024-12-12 blade fuse slots 1mm
    [Fugu2.kicad_pcb, Fugu2.kicad_sch]
2024-12-24 i2c conn 2mm pitch
    [uC.kicad_sch]
2024-12-28 docs cleanup
    [diodes.kicad_pcb, uC.kicad_sch]
2024-12-28 pcb fixes
    [Fugu2.kicad_pcb, Fugu2.kicad_sch, GateDrive.kicad_sch]
2025-01-31 docs, add panelize script
    [Fugu2.kicad_pcb, Fugu2.kicad_sch]
2025-01-31 add pcbway quotation
    [T-X7W543990A-5sets-BOM_Fugu2.kicad_pcb(2024-10-27).xls]
2025-09-01 WIP on main
    [Fugu2.kicad_pcb, Fugu2.kicad_sch, uC.kicad_sch]
2025-09-01 schematics and pcb fixes
    [Fugu2.kicad_pcb, Fugu2.kicad_sch, Sensors.kicad_sch]
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2025-09-25 bump kicad version
    [Fugu2.kicad_pcb, Fugu2.kicad_sch, GateDrive.kicad_sch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]
2025-10-23 bigger terminal blocks, add usb-c socket
    [Fugu2.kicad_pcb, Fugu2.kicad_sch, GateDrive.kicad_sch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]
2025-10-29 usb-c plug THT, silkscreen cleanup
    [Fugu2.kicad_pcb, Fugu2.kicad_sch, uC.kicad_sch]
2025-11-09 add 3.3v monitor pin
    [Fugu2.kicad_pcb, Fugu2.kicad_sch, GateDrive.kicad_sch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]
2025-11-10 ceramic power supply cap
    [PowerSupply.kicad_sch]
2025-11-10 add CAN bus header for SN65HVD230
    [Fugu2.kicad_pcb, GateDrive.kicad_sch, uC.kicad_sch]
2025-11-10 onboard 12v supply
    [Fugu2.kicad_pcb, PowerSupply.kicad_sch]
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2025-11-10 schematic for OP amp based current sensor
    [Fugu2.kicad_pcb, PowerSupply.kicad_sch, Sensors.kicad_sch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]
2025-11-11 add HV fuse
    [Fugu2.kicad_pcb, Fugu2.kicad_sch]
2025-11-11 fix bflow gate drive
    [GateDrive.kicad_sch]
2025-11-11 dnp new current sense circuit
    [Sensors.kicad_sch]
2025-11-11 fix dcr
    [Fugu2.kicad_pcb]
2025-11-12 adj graphics
    [Fugu2.kicad_pcb, Fugu2.kicad_sch]
2025-11-12 bom optimization
    [Fugu2.kicad_pcb, Fugu2.kicad_sch, GateDrive.kicad_sch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]
2025-11-13 add pwr rail selection
    [Fugu2.kicad_pcb, Fugu2.kicad_sch, GateDrive.kicad_sch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]
2025-11-13 rename parts.kicad_pcb
    [z_parts.kicad_pcb]
2025-11-13 cleanup schematics
    [Fugu2.kicad_pcb, Fugu2.kicad_sch, GateDrive.kicad_sch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]
2025-11-14 silkscreen font size
    [Fugu2.kicad_pcb]
2025-11-15 opa current sense
    [Fugu2.kicad_pcb, GateDrive.kicad_sch, Sensors.kicad_sch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]
2026-07-06 doc: no-coil SW ring — frequency reconciled (Aikawa CSI + datasheet Coss)
    Fold the no-coil SW-node ring bench-vs-SPICE reconciliation into the
    authoritative repo. The frequency question, previously left "open /
    under-determined", is now reconciled by anchoring both L and C to
    measurements instead of model outputs:
    - Coss: a C-V charge sweep shows both SPICE models (vendor _L0 and the
    home-built) run ~15-20% high at 60 V vs the datasheet (~800 pF). The
    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
2026-07-06 doc: no-coil ring — curve-fit Coss (no scale fudge) + phantom-Cgd finding
    Refine the frequency reconciliation: instead of scaling the homebrew Coss
    to hit ~800 pF@60 V, re-fit Coss/Cgd to the datasheet Diagram-11 curve as
    behavioral charge capacitors (Qoss=105 nC / Qgd=19 nC as integral
    constraints). C-V re-verify lands within ~3% of datasheet across 40-80 V,
    and the ring reaches 60 MHz @ 9.2 nH with no coss_scale.
    Surfaced a real model bug: the old build held Cgd = Qgd/40 = 475 pF
    constant, but Crss collapses to ~37 pF by 60 V. That phantom ~440 pF was
    silently damping the ring. With the correct voltage-dependent Cgd the
    undamped ring overshoots to 140 V; the doc's calibrated ~2.5 Ohm
    Co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
2026-07-06 spice: import fets-to-tdson8 parasitic/loss modeling work onto main
    Port the spice/ modeling work developed on the fets-to-tdson8 branch onto
    the canonical main so it is preserved (branch clone is being retired).
    Squashes the additive content of three commits by Fabian:
    1c5a805 Fugu2: FastHenry commutation-loop L extraction + vendor Cin models
    5b58789 Fugu2: mfr MOSFET models settle the 32A switch-node overshoot
    f183f2d Fugu2: add sourced power-loss budget script + chart
    Brings the FastHenry extractor (spice/extract/), vendor cap/FET models
    (spice/extract/capmodels/), the DPT decks (dpt_toshiba/dpt_mixed.cir), and
    the loss-budget script + chart (spice/loss_budget.py, fugu2_loss_budge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
2026-07-06 doc: correct loaded ring — output-coil resonance ~18-19MHz, not 60MHz Coss
    New bench data (Fab, cursor reads; cross-checked by the dcdc-tools
    loaded-sw-ring verification) falsifies the earlier claim that the ~60 MHz
    ring is "present with and without the coil / unaffected by the inductor".
    The loaded (coil-connected) SW ring is ~18-19 MHz and VOLTAGE-INDEPENDENT
    (20V->18, 40V->18, 60V->19.2). A fixed frequency across 3x Vin rules out
    the Coss tank (Coss varies ~2.5x) -> it is the output-coil self-resonance,
    a different loop. The 60 MHz ring is the NO-COIL local-Coss ring only; the
    coil changes it 60->~19 MHz.
    A curve-fit-Coss deck matched the loaded ring at 20V only by coincidence
    (large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
2026-07-06 doc: reframe §3 damping — edge-limited over-ring, not a 2.5-ohm Coss loss
    Per the dcdc-tools loaded-sw-ring damping budget: the earlier "missing
    ~2.5 ohm device Coss-loss damping" is not physical. Tank Z0=sqrt(L/C)~3.4 ohm;
    the observed ~4-cycle decay needs only zeta~0.04 -> ~0.27 ohm, and the real
    loop R (copper 17mOhm + freq-resolved MLCC ESR ~6-12mOhm ~25mOhm) is ~10x
    below even that. Coss hysteresis is a superjunction effect, small for this
    80V trench part -> attribution retracted.
    The modest first overshoot is the FINITE EDGE (15.8ns rise ~ 1 ring period)
    weakly exciting the tank; the sim over-rings (140V undamped) mainly because
    it doesn't reproduce the 15.8ns edge (rise-time gap,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
2026-07-06 doc: re-correct loaded ring — Coss loop scaling, coil-SRF retracted
    Reverses db492e8. Fab re-measured on-scope: his earlier "18-19 MHz"
    loaded cursor reads were ~2x too low. Real loaded periods 27/18.6/17.1 ns
    = 37.0/53.8/58.5 MHz at 20/40/60 V -> the ring SCALES with bias as
    f ~ 1/sqrt(Coss(V)) (bench ratios 0.63/0.92 vs predicted 0.64/0.89).
    L@60V(58.5 MHz, ~800 pF) = 9.3 nH = the SAME commutation loop as no-coil,
    and loaded-60V(58.5) ~= no-coil-60V(60) -> the output coil does NOT touch
    the ring. So the original "60 MHz ring present with and without the coil,
    local Coss loop" reading stands, now backed by the full 1/sqrt(Coss)
    scaling.
    The intermediate "voltage-independent ~18-19 MHz co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
2026-07-06 Add Schottky diode models + spice-fit from dcdc-tools
    ST15100S and SVT15100UB datasheet-fit SPICE models (no usable vendor model
    exists) plus their gridline-digitized fit tooling, LTspice validation benches,
    and reference datasheets. Moved here from dcdc-tools since the Fugu2 LS
    Schottky-vs-body-diode Qrr and loss-budget studies (spice/loss_budget.py,
    dpt_*.cir) are the consumers. spice-fit/ is self-contained (relative ../models
    includes).
2026-07-07 doc/Capacitors: input-cap bank — roles, loss, DC-bias, ring share
    Substantial rewrite of the input-capacitor documentation:
    - Two roles split: electrolytics absorb the 39 kHz ripple (ESR-limited →
    loss), ceramics absorb the MHz commutation spikes (ESL-limited → loop
    area / Vds overshoot). Electrolytics own the loss; ceramics own the HF.
    - Loss split @ 72→27 V/30 A: ripple ~3.4 W in the electrolytics (chopped-DC
    term dominates, f_sw/L barely move it; only lever is parallel ESR), spike
    RMS only ~0.73 A → ~14 mW in the ceramics at ring-band ESR — negligible.
    Electrolytic ESR is ~flat above 20 °C (no hot derating).
    - DC-bias at 72 V verified vs vendor curves: 220 nF 0.164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
2026-07-07 doc/Capacitors: split loss-tool model detail out to dcdc-tools
    Move the DC-bias operating-point derivation, the per-part ESR(f)/ESL/DC-bias
    provenance, and the "how the loss model resolves caps by value-bucket" section
    to dcdc-tools/loss/docs/capacitors.md (tool-model material). Keep the board-design
    content here — roles, loss split, how-to-reduce, the depopulation BOM decision,
    the parts table, electrolytic — plus a short note carrying the verified 72 V
    effective-C numbers (220n 0.164x / 1u 0.195x / 10u 0.157x) and a pointer to the
    tool doc.
2026-07-08 doc/Capacitors.md: two-band Cin ring-share correction (ripple vs HF ring)
    Correct the "which ceramics carry the ring" section: the 1/branch-L ranking is
    the trunk/scalar approximation (drops mutual coupling). Split the current-share
    question into two regimes — the f_sw ripple band (capacitance-dominated: the
    10 uF C21/C22 carry ~83% current / ~91% ESR loss, C27 ~3%; scalar==physical) vs
    the HF inductive ring (mutual-coupled: the full physical port matrix puts C27
    at ~26% current / ~22% ring ESR-loss, NOT ~3%). C27 stays a depopulation
    candidate on the RIPPLE argument (does ~no f_sw work), not on being absent from
    the ring — the "~3% at the ring" figure was the trunk artifact.
    Also captu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
2026-07-16 restored INA226 schematics
    [Fugu2.kicad_pcb, Sensors.kicad_sch, uC.kicad_sch]
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2026-07-17 Fixed DRC errors
    Fixed DRC errors https://github.com/vikulin/Fugu2/issues/1
    See https://github.com/vikulin/Fugu2/issues/1 for a detailed report
    [Fugu2.kicad_pcb]
2026-09-02 Add parametric ASA shroud for the Fugu2 board on a 100x100 heatsink
    The heatsink is the floor and its fins stay in free air, per the design rule
    in doc/Enclosures.md 0. Frame + removable lid, both ASA, all outer surfaces
    flat with the lid-screw bosses inside.
    Geometry is taken from Fugu2.kicad_pcb, not from photographs. The three
    features that shape it: Q1's TO-220 overhangs the board by 7.08 mm and escapes
    through a slot in the bottom of the left wall, so that wall sits 0.2 mm off the
    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
2026-09-29 plan: fix mcu-head pin count, order decisions, V+ check before first TX enable
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2026-09-29 F3: 25A 58V MINI fuse (Littelfuse 0997025.WXN) on HV input
    Boost-charger use puts a battery on the HV terminal; F3 is the only
    thing that clears a battery short there. Switch F3 to the new
    open-pe:Fuse_Blade_Mini_directSolderThin footprint (8.12 mm pitch,
    measured from the Littelfuse STEP). doc/HV Fuse.md records the
    requirements, the parts found with prices, and the ATO alternative
    (ESKA 340.032-58V).
    F3 is still missing from the PCB since the cs-opa merge; needs F8.
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2026-10-10 doc: ESP32-S3 ADC1 calibration -- S-curve INL, universal correction, per-board gain/offset
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2026-10-10 doc: ESP32 ADC -- review fixes, clearer charts, merged firmware and measured board cal
    Codex review of be25373:
    - range is 16.5-73.4 V at the node (570-2658 mV are IDF readings)
    - fboost's worst transfer point is at the top rung, not the bottom
    - gain difference: same eFuse point, so board or residual chip -- not separable here
    - repeatability holds where the runs overlap (16.5-43.5 V); the 35 mV floor is a
    degree-5 residual, the operating-point cause a hypothesis
    - IDF bottom panel limited to the fitted range, detrending convention stated;
    readback compared at the step-1 value
    - charts: zero lines, findings in titles, legends off the data, peak in legends,
    25/65 V markers, taper dashe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
2026-10-10 ESP32 ADC doc: calibrate from a full 2 V pass (minimax), fboost recal + second check run, chip-specific floor and gain drift in Limits
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2026-10-11 HW Stories: flu -- as-built FETs and gate drive, link to dcdc-tools flu.yaml, 2026-10-11 Q3 screw short incident
2026-10-11 doc/INSTALLATION.md: revise after two independent reviews (Codex xhigh + Claude)
    Fixes, each checked against the PCB at HEAD and the EMC study:
    - battery cable lands on the system side (after battery fuse, BMS disconnect, shunt);
    the dedicated-cable reading of IEC 61000-6-3 §3.8 NOTE now "supports, does not
    settle", with the residual risk named and the hardware alternative as OPEN 1
    - ratings table; F3 is 58 V on an 80 V PV input -> fuse note and OPEN 2 (safety);
    F1 voltage rating OPEN 3; battery-end fuse rated for DC voltage and fault current
    - grounding section: PV- (BuckGND) and battery- (GND) joined only through R26
    - heatsink rule corrected: as built -6.62 dB vs AV, nylon screw -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
2026-10-11 HW Stories: flu -- correct 2026-10-11 incident: DZ1 not fitted, ~70 V Vin while seating HS-tab TMP117, D1-A shorted to GND, pcbway-order-2024-10 board
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2026-10-12 doc: EMI Precompliance -- bench plan, standards basis, wiring and the sourced basket
    Pre-compliance bench note for the switch-node ring and cable CM current, written
    against the integrated-radio (RED-only) standards basis decided 2026-10-10.
    The framing inverted during the work: radiated limits start at 30 MHz, so the
    original 15-55 MHz ring focus is largely below the scored band, and the in-band
    mechanism is CM current on the PV/battery cables. Limit-equivalent CM current is
    ~8 uA at 30 MHz on both the FCC 3 m and EN 61000-6-3 10 m routes, which is ~101 uV
    at the scope through a 22 dBOhm clamp -- about 40 dB over the floor, so no preamp
    and no attenuator.
    Includes: the MXO4 setup and the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
2026-10-12 doc, spice: correct the board-identity record for the no-coil ring study
    Two corrections to documents that described the wrong hardware.
    No-Coil SW Ring: the board under test was never written down. It is reconstructed
    as HW Stories/fetlib.md "testboard1" (HS 2p IPP055 / LS IPP024, no external diode)
    -- the only FET set in HW Stories/ that matches, corroborated by the absent LS
    diode agreeing with the D9-DNP body-diode freewheel used throughout. The near-miss
    boards and the open points (Rg = 15 Ohm not in fetlib.md) are recorded with it.
    The IPP050N10NF2S / IPP039N10N5 set annotated as "actually fitted" in
    pwr-mosfet-lib is *ftall*, a different board, which retires the FET-identity
    conflict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
2026-10-12 doc: LS cascode for Qrr relief -- assessment after Codex review
    Answers "would an LS cascode reduce reverse-recovery effects, and would it
    help EMC?". Mechanism is valid; the case for building one on this board is not.
    Three retractions are recorded in full because each was asserted confidently
    before being checked:
    - "Topologically impossible" was a non-sequitur. A parallel body diode does not
    have to be blocked, only held below its knee. I_lim is 292 A cold / 186 A at
    125 C against 32 A, so diode avoidance is not in doubt here.
    - "Voltage clamping is where the loss saving comes from" is wrong. Recovery
    energy is ~Vin*Qrr across the whole commutating cell and burns mostly in the
    H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
2026-10-12 ring_analysis: close the c_eff defects with an exact anharmonic period integral; the model choice moves L by 0.2 %
    c_eff_pf carried two open defects. Both are closed.
    1. The integrator used to validate the candidate models was broken: it returned
    282 pF where the exact answer for a constant 800 pF capacitor is 800 pF. So
    neither the charge chord nor the small-signal model had ever been checked
    against anything, and the doc carried a +-8 % caveat on every frequency and Z0
    as a result.
    2. Two call sites disagreed about the excursion. dfreq passed the upper half
    [Vin, Vpk]; bias/solve/snub passed a symmetric swing about Vin. The ring
    swings below the plateau into steeply high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
2026-10-12 Apply adversarial review: the c_eff fix did not close defect 2, and five doc claims were wrong
    Reviewer found that this morning's "exact anharmonic period integral" commit did
    not do what its message claimed, plus four wrong numbers and two mislabelled
    physics claims. All verified against primary sources before changing anything.
    ring_analysis.py:
    - CRITICAL. cmd_bias passed v_center = (Vin+Vpk)/2, so the potential well was
    centred on the MIDPOINT and the solved lower turning point was pushed back to
    ~Vin (20.1 / 40.4 / 60.2 V). The excursion was still the upper half: defect 2
    was not closed, and the reported 0.2 % spread measured three interpolation
    models over the same wrong inte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
2026-10-12 doc: BENCH J10 source inductance -- specify the 1.73 vs 11 nH discriminator
    EMI Precompliance names "the J10 DM voltage spectrum, or the bank
    anti-resonance" as the measurement that settles the widest uncertainty in the
    radiated estimate, but never specifies it, and the file it points at does not
    exist. This is that spec.
    Two corrections to the plan as named:
    - The anti-resonance is NOT the discriminator. The elco/MLCC anti-resonance
    sits at 230-712 kHz and every MLCC in the bank self-resonates below 10 MHz,
    so across 30-70 MHz the bank is purely inductive. There is no peak to hunt
    for; the discriminator is the inductive asymptote, a flat 6.4x in |Z|. A
    useful consequence is that D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
2026-10-12 Track the print-oriented 3D models and the four HW Stories images; ignore IDE and agent scratch
    The four images were already referenced by committed markdown -- ftall.md:235-239 and
    flu.md:30 -- so main carried four broken image links. Tracked as PNG rather than converted
    to the HW Stories .webp convention because ftall.md has uncommitted work in it from another
    session; the conversion and the link rewrite wait until that tree is clean.
    The print-oriented STLs and the arachne 3mf join fugu2-shifted-P1P-ASA.3mf and
    fugu2-board.stl, which were already tracked beside them.
    Ignored: .idea/webServers.xml (remote-server config, can carry credentials, same family as
    the already-ignored deployment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
2026-10-12 doc: retract the unpowered J10 spec, keep the corrected bank facts
    A Codex review killed the unpowered measurement on four independent counts,
    and verifying its findings against the PCB netlist turned up board facts worth
    more than the spec was.
    Retracted (details in the file): it measured the driving-point impedance at J10
    where the model defines a transfer impedance from the hot loop (0.377 vs
    4.46 nH on the model's own values, so a perfect nominal measurement would have
    read "inconclusive"); MXO4-K36 is gain/phase FRA only and the impedance option
    K337 is NOT installed, so "no VNA needed" was wrong -- that came from a
    distributor listing conflating two options; at zero bias the FET Coss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
2026-10-12 EMI Precompliance: flag that an RC snubber (R11 7.5 ohm / C8 2.2 nF) is already fitted
    Verified from the PCB netlist while checking a Codex review of the J10 bench
    spec. C8 had been read as an input-bank capacitor; it is the snubber cap, in
    series with R11 from SW to BuckGND.
    Consequence for the lever table: every "+ LS RC snubber" row is a re-tune of an
    existing network, not an addition. If the radiated deck's "board that exists"
    baseline does not contain R11/C8, the snubber lever is double-counted. The
    fitted 7.5 ohm is 2.2x the matched Z0 and 5x the 1.5 ohm the model prefers, and
    2.2 nF is under half the modelled 4.7 nF.
    Both radiated decks currently have no live owner, so this is recor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
2026-10-12 doc: retract "a snubber is already fitted" -- the board has none
    Fab, 2026-10-12: "i think we never used snubbers." Correct, and already written
    down: loss/examples/ftall.yaml declares board_as_built.snubber.fitted = false
    (attested 2026-08-11) and its header lists R11+C8 as one of three places the
    schematic is stale. The PCB netlist proves topology, not population; the dnp
    flag reads "fitted" and is wrong.
    So the radiated deck's unsnubbed baseline is right and its "+ LS RC snubber"
    lever is a genuine addition, not a double-counted re-tune.
    Also from the same attestation: dead time is 297 ns (R1 = 33k), not the 185 ns
    the schematic's 20k implies -- corrected in the cascode doc, where it mo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
